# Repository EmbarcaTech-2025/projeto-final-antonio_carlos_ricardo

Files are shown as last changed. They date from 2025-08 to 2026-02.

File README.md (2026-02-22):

# Projeto final - EmbarcaTech 2025 - 2026

Autores: **Antonio Marcio Crepaldi**, **Carlos Martinez Perez** e **Ricardo Jorge Furlan**

Curso: Residência Tecnológica em Sistemas Embarcados

Instituição: EmbarcaTech - HBr

Campinas 22, fevereiro de 2026.

---

## ⚠ Disclaimer
## THE SOFTWARE IS PROVIDED "AS IS", USE AT YOUR OWN RISK
## O SOFTWARE É FORNECIDO "COMO ESTÁ", USE POR SUA CONTA E RISCO

## This code was developed for educational purposes as an assignment for Phase 2 and 3 of the residency program in the **EmbarcaTech professional training program**, with the goal of demonstrating some of the concepts learned during the residency.

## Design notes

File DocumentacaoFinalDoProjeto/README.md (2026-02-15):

# Projeto final - EmbarcaTech 2025-2026

Autores: **Carlos Martinez Perez** e **Ricardo Jorge Furlan** e **Antonio Crepaldi (na fase 3)**  

Curso: Residência Tecnológica em Sistemas Embarcados

Instituição: EmbarcaTech - HBr

Campinas 15, fevereiro de 2026.

---

## ⚠ Disclaimer
## THE PROJECT IS PROVIDED "AS IS", USE AT YOUR OWN RISK
## O PROJETO É FORNECIDO "COMO ESTÁ", USE POR SUA CONTA E RISCO

## This project was developed for educational purposes as an assignment for Phase 3 of the residency program in the **EmbarcaTech professional training program**, with the goal of demonstrating some of the concepts learned during the residency.

## Third-Party Code

- The `pico_sdk_import.cmake` file was **automatically generated** during project creation by the **Raspberry Pi Pico plugin**.
- The `CMakeLists.txt` file was initially **automatically generated** during project creation by the **Raspberry Pi Pico plugin**, and later edited as needed for the project.

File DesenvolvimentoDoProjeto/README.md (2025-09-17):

# Projeto final - EmbarcaTech 2025

Autores: **Carlos Martinez Perez** e **Ricardo Jorge Furlan**

Curso: Residência Tecnológica em Sistemas Embarcados

Instituição: EmbarcaTech - HBr

Campinas 08, setembro de 2025.

---

## ⚠ Disclaimer
## THE SOFTWARE IS PROVIDED "AS IS", USE AT YOUR OWN RISK
## O SOFTWARE É FORNECIDO "COMO ESTÁ", USE POR SUA CONTA E RISCO

## This code was developed for educational purposes as an assignment for Phase 2 of the residency program in the **EmbarcaTech professional training program**, with the goal of demonstrating some of the concepts learned during the residency.

## Third-Party Code

- The files for controlling the **OLED display** (`ssd1306_...` files), including the text fonts, were based on the repository:  
  https://github.com/BitDogLab/BitDogLab-C/tree/main/display_oled_logo/inc with minor modifications.
- The `pico_sdk_import.cmake` file was **automatically generated** during project creation by the **Raspberry Pi Pico plugin**.
- The `CMakeLists.txt` file was initially **automatically generated** during project creation by the **Raspberry Pi Pico plugin**, and later edited as needed for the project.

## How to Build/Compile the Code

This software was developed for the **BitDogLab V6.3** board. This board uses the **Raspberry Pi Pico_W** board (which contains the **RP2040 microcontroller**).

For development, the **Visual Studio Code IDE** was used along with the **Raspberry Pi Pico plugin**. The SDK version used was **2.2.0**.

---

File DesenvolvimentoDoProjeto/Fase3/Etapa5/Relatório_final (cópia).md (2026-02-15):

# RELATÓRIO FINAL DO PROJETO

# Estação Meteorológica IoT de Baixo Consumo com LoRaWAN

**Autores: Antonio Crepaldi - Carlos Perez - Ricardo Furlan**

**15/02/2026**

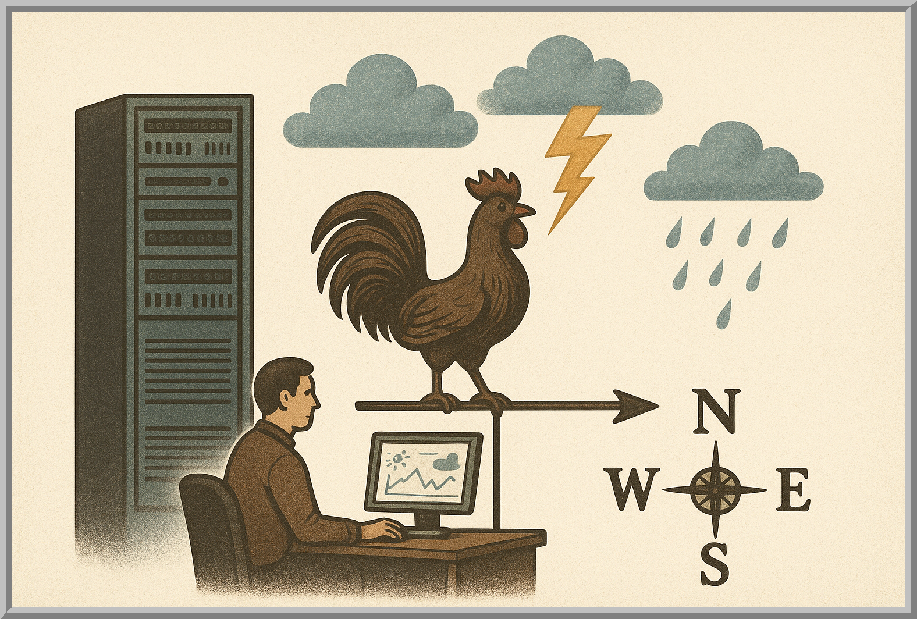
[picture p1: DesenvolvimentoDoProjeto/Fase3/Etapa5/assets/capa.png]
Capa do Manual

---

## 1. Introdução

Este relatório apresenta a consolidação final do projeto **Estação
Meteorológica IoT**, desenvolvido no âmbito do programa Embarcatech, com
foco em:

- Monitoramento ambiental distribuído;
- Comunicação via LoRaWAN;
- Autonomia energética com painel solar;
- Visualização em dashboards dos dados coletados;
- Solução escalável para múltiplas estações.

O projeto evoluiu desde validações laboratoriais (TRL 4) até validação
em ambiente operacional (TRL 7), culminando na implantação em
campo e validação integral do sistema.  
A figura a seguir, apresenta a estação operando em campo.

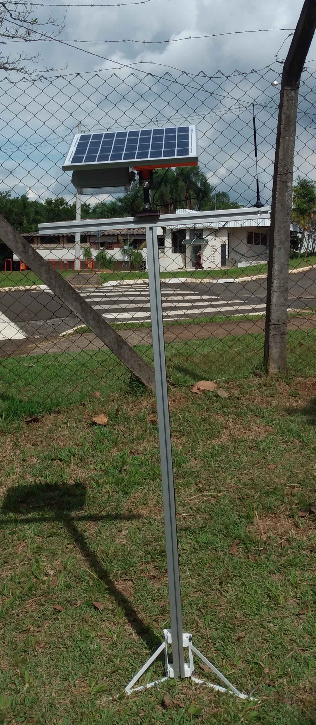
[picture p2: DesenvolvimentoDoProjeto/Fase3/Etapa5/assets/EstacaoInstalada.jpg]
Estação Instalada na FEEC


---

## 2. Requisitos do Projeto

O projeto atende ao que foi solicitado no Programa Embarcatech em sua fase 3. Os requisitos consolidados do projeto são os seguintes:  

### 2.1 Requisitos Funcionais

O sistema deverá ser capaz de executar as seguintes medições de parâmetros ambientais:  
- Temperatura do Ar: medição em graus Celsius (°C)
- Umidade Relativa do Ar: medição em porcentagem (%)
- Pressão Atmosférica: medição em hecto Pascal (hPa)
- Luminosidade: medição em Lux (lx)
- Localização: obtenção de coordenadas geográficas
- Tensão da bateria: medição em Volts (V)

Coleta de Dados:  
- Realizar a coleta de dados dos sensores habilitados em intervalos definidos (ex: a cada 1 minuto, 10 minutos, etc.).

Transmissão de Dados:  
- Transmitir os dados coletados via LoRaWAN para o gateway RAK7289V2 instalado na FEEC.  

Visualização e Análise de Dados:  
- Os dados serão acessíveis e visualizáveis através da plataforma TheThingsBoard, com dashboards personalizáveis e específicos.  

### 2.2 Requisitos Não Funcionais

- Modularidade: O design do sistema é modular, permitindo a fácil adição ou substituição de sensores para satisfazer às necessidades específicas de cada usuário.  
- Escalabilidade: O sistema é capaz de suportar a implantação de múltiplas estações em diferentes locais, de forma que os dados possam ser facilmente agrupados.
- Autonomia Energética: Operação autônoma com baixo consumo de energia, através de bateria de Lítio e carregamento com placa solar.
- Robustez Física e Resistência à Intempéries: O encapsulamento eletromecânico é resistente a condições climáticas adversas (chuva, vento, sol, poeira, umidade) atendendo ao grau de proteção IP68.
- Manutenibilidade: Facilidade de manutenção e atualização de software e hardware em campo.
- Segurança (Básica): Proteção básica dos dados transmitidos para o gateway, suprido pelo protocolo LoRaWAN.

---

## 3. Arquitetura Geral do Sistema

A figura a seguir, mostra a arquitetura geral do sistema, destacando os blocos de energia, sensores e comunicação.  
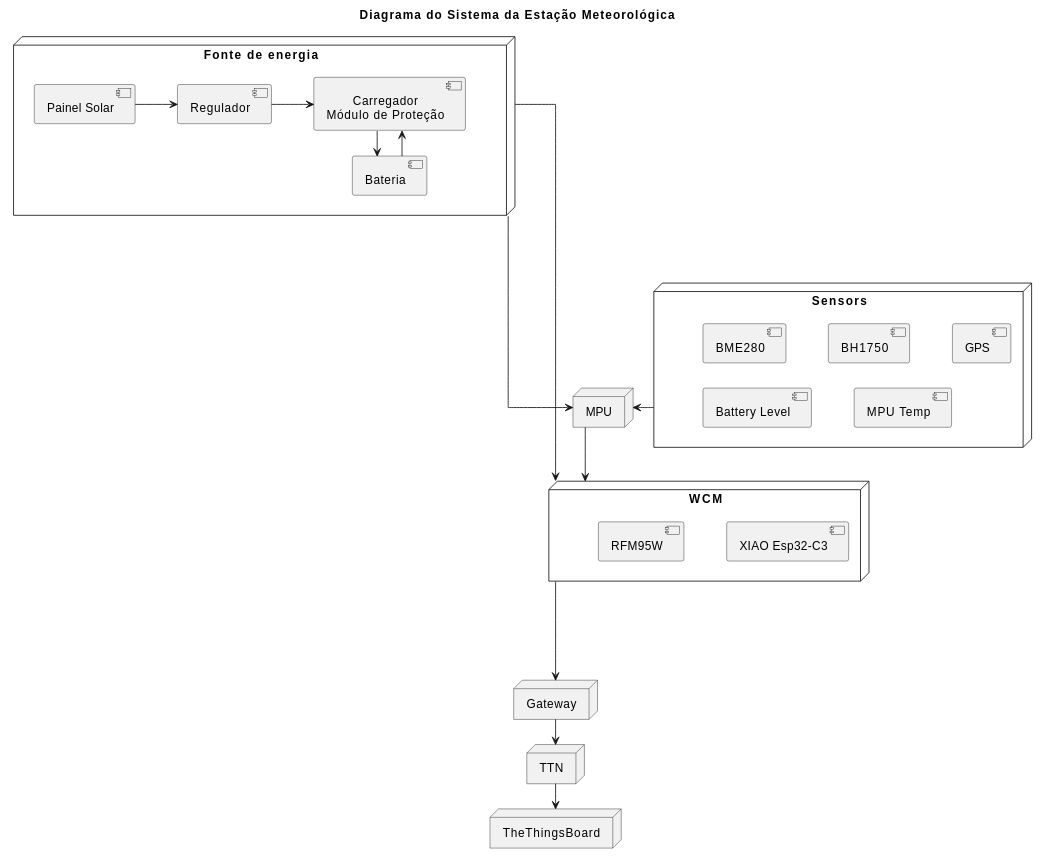
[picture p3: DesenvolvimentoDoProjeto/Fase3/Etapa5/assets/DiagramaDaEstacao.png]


O sistema é composto por cinco camadas principais:

### 3.1 Camada de Sensoriamento

A implementação consta dos seguintes sensores:  
- Temperatura, umidade e pressão atmosférica (BME280);

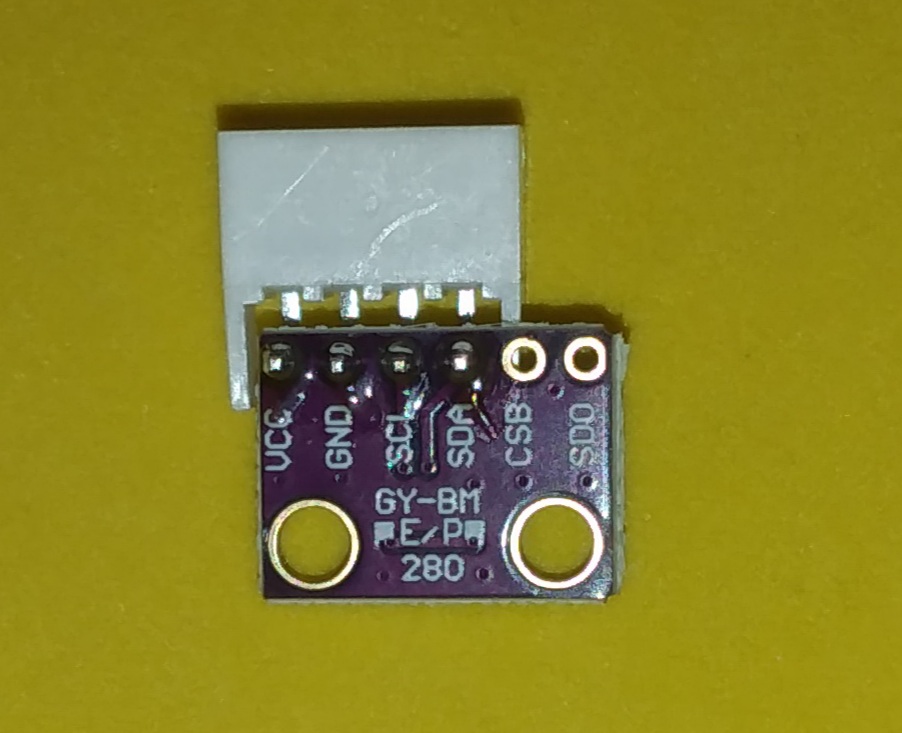
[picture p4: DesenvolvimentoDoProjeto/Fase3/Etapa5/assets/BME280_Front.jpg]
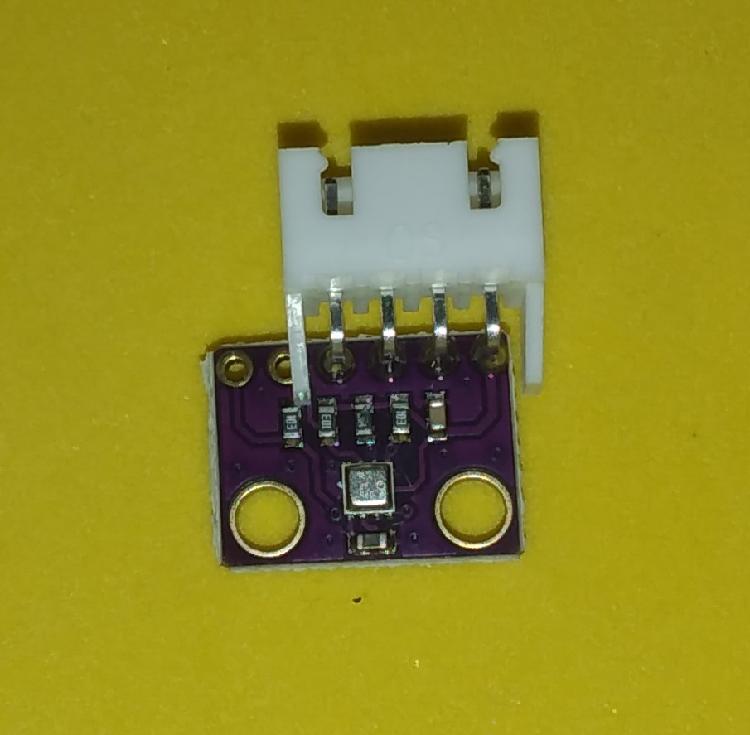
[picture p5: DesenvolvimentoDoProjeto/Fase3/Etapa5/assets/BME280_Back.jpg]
BME280 Verso
|  |  |
|---|---|

- Luminosidade (BH1750);

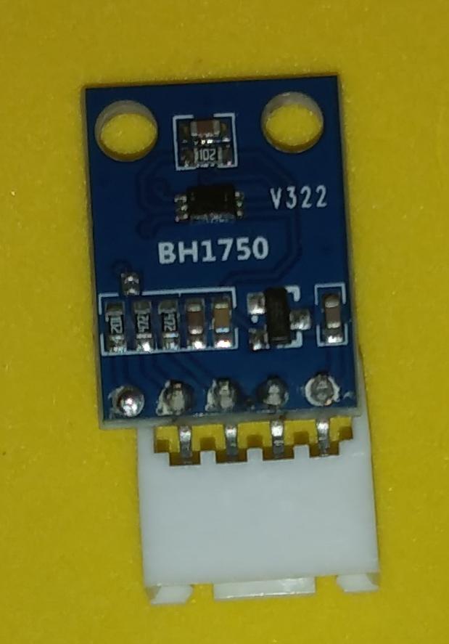
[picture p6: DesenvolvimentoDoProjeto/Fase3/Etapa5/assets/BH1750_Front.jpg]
BH1750 Frente
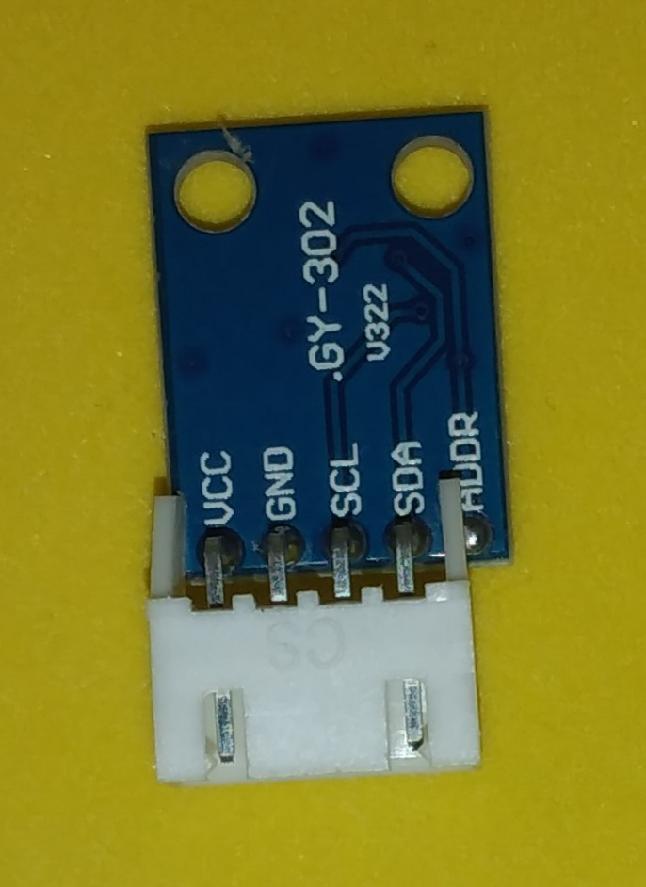
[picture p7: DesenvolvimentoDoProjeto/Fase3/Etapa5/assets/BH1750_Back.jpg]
BH1750 Verso
|  |  |
|---|---|

- GPS (GY-NEO6MV2);

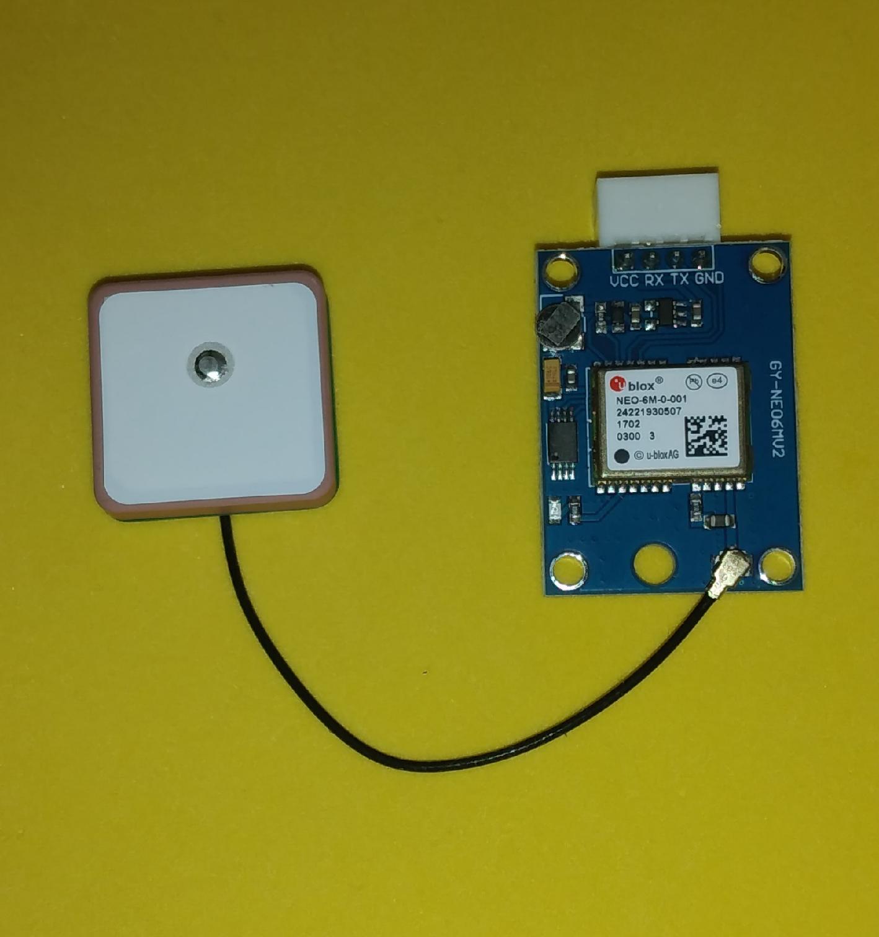
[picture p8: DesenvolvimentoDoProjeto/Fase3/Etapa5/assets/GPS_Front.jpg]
GPS Frente
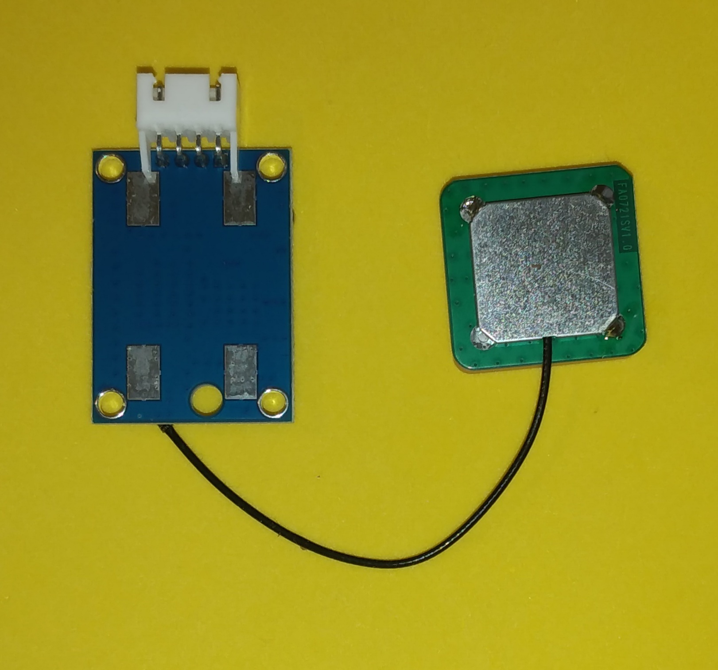
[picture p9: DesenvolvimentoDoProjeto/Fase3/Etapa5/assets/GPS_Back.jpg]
GPS Verso
|  |  |
|---|---|

- Nível de bateria (via AD e divisor resistivo);
- Temperatura interna do microcontrolador (RP2040).

### 3.2 Camada de Processamento

A camada de processamento é composta pelos seguintes elementos:

-   Microcontrolador RP2040 (Raspberry Pi Pico);
-   Estratégias de baixo consumo (desativação de funcionalidades desnecessárias e redução de clock do micricintrolador);
-   Estrutura modular do firmware.

A figura a seguir mostra a disposição dos componentes na placa.  

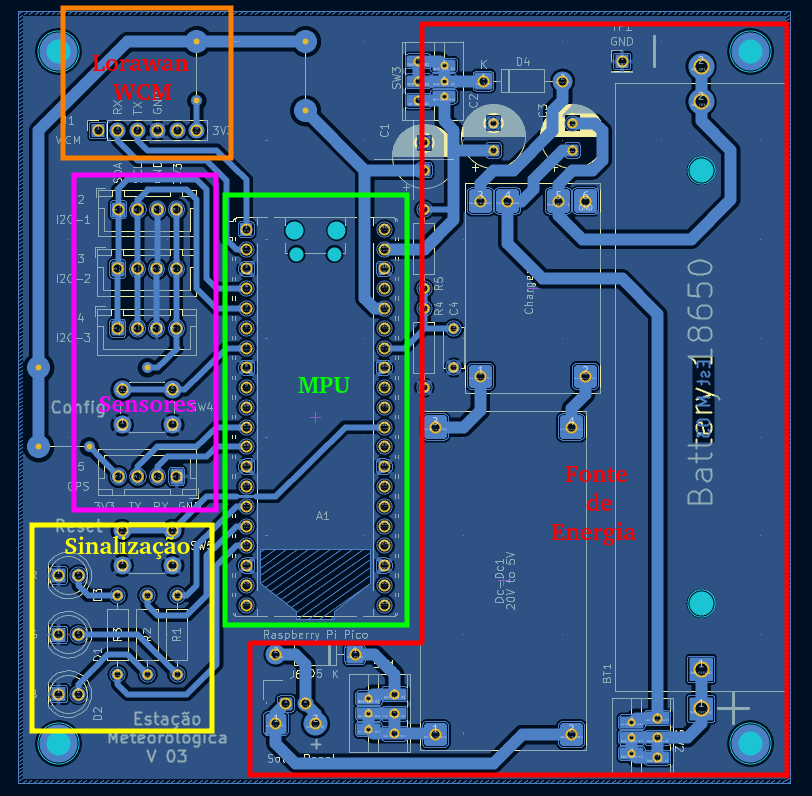
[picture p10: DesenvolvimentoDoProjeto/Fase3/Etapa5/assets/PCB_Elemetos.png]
Placa Principal - Extrutura


### 3.3 Camada de Comunicação

A camada de comunicação é constituída por:  
-   Módulo WCM - Wireless Communication Module (XIAO ESP32-C3 e RFM95W);
-  Implementação de Lite Sleep Mode;
-  Protocolo de comunicação LoRaWAN ABP;
-   Payload otimizado para redução do Time on Air (ToA).

Na figura a seguir aparece o WCM.

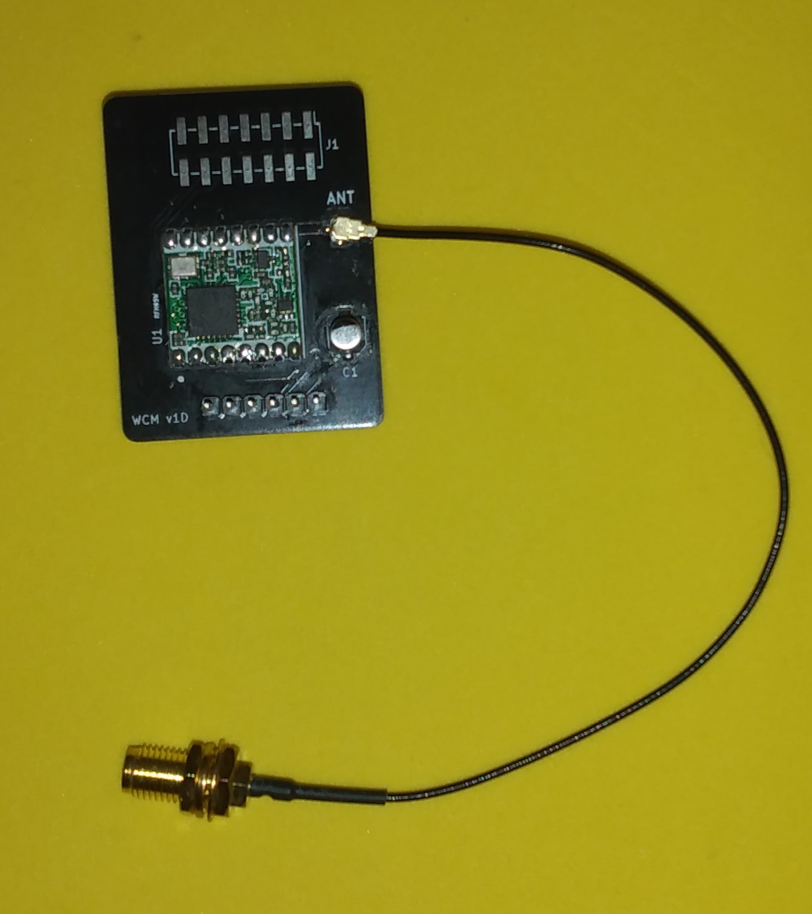
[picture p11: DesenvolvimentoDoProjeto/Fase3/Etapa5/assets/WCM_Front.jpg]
WCM Frente
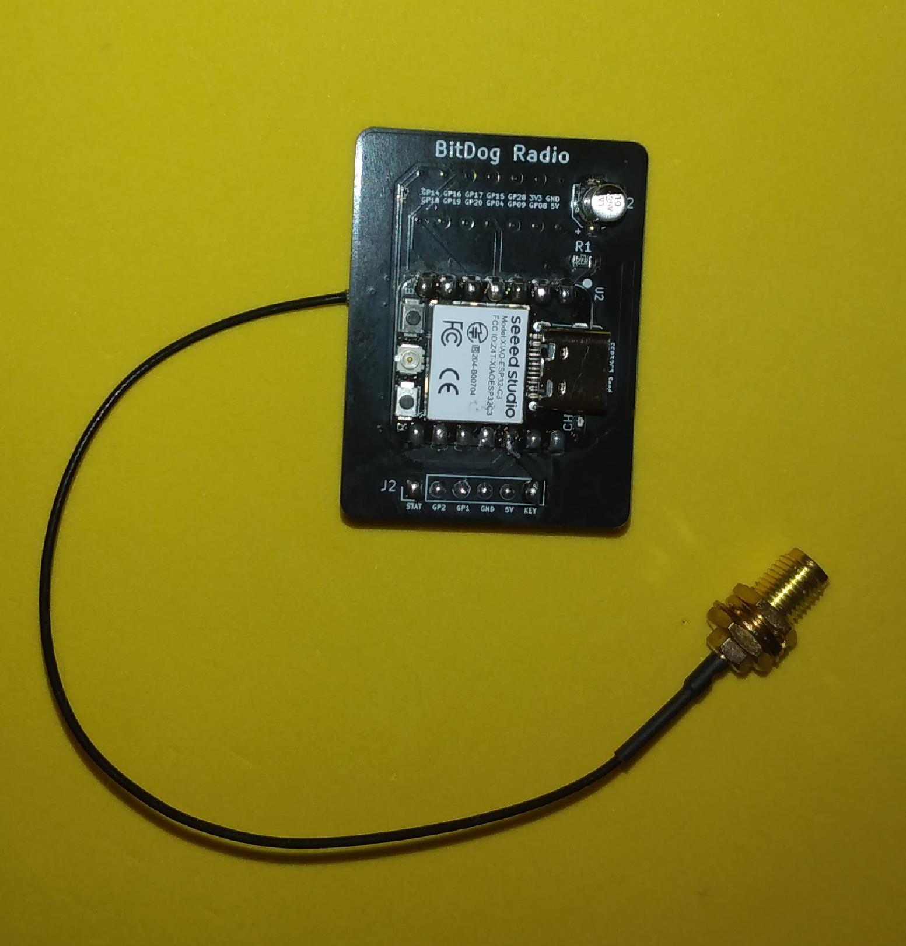
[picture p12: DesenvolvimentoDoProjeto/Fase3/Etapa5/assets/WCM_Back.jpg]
WCM Verso
|  |  |
|---|---|

O hardware do módulo WCM foi desenvolvido no projeto de iniciação científica da FEEC (https://drive.google.com/file/d/10zEuYUwZnq1ES-jrfOPs1fpPD2277zWO/view).

### 3.4 Camada de Recepção de Dados

A camada de recepção de dados é constituída por:  
-  Gateway RAK7289V2;
-  Servidor na nuvem (The Things Network - TTN).

A camada de recepção de dados foi desenvolvida no projeto de iniciação científica da FEEC (https://docs.google.com/document/d/1o25VC49TM4YPC_RLyG_XDTTJo1DXNHsViMWomo7teZQ/edit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).

### 3.5 Camada de Aplicação

A camada de aplicação envolve:  
-  Servidor local (Raspberry Pi 5);
-  Persistência de dados com PostgreSQL.
-  TheThingsBoard com dashboards individuais e comparativos;
-  Acesso via Cloudflare.

Esta camada também foi desenvolvida pelo grupo de iniciação científica da FEEC.

---

## 4. Evolução Técnica do Projeto

### 4.1 Desenvolvimento Individual dos Componentes

Foram desenvolvidos individualmente:  
-  Software para aquisição de dados dos sensores (em anexo);
-  Software para comunicação LoRa ponto a ponto com RFM95W (em anexo);
-  Estratégias de redução de consumo para RP2040 e ESP32-C3;
-  Estratégias de carregamento de bateria com placa solar.

### 4.2 Integração dos Componentes do Sistema

-  Desenvolvimento da PCB dedicada (em anexo):  
O desenvolvimento inicial da estação meteorológica previa o uso da placa educacional BitDogLab versão 7. No decorrer do desenvolvimento, devido aos rigorosos requisitos de consumo de energia, optou-se pelo desenvolvimento de uma nova placa dedicada. Isto deveu-se ao fato de que os diversos periféricos da BitDogLab, ou seja, display OLED, matriz de LEDs RGB, microfone e amplificador de áudio e regulador 3V3, consumiam energia mesmo não estando em operação. Além disso, o carregador não energizava a placa automaticamente. Outro aspecto que corrobora com essa decisão é a necessidade de utilização de carregamento de bateria via placa solar, através da utilização de um carregador dedicado. Assim, foi desenvolvida uma nova PCB agregando todas os componentes, (RP2040, carregador de bateria, regulador de tensão, bateria, chaves de comando e conectores para os sensores e WCM), como mostra a figura a seguir.  

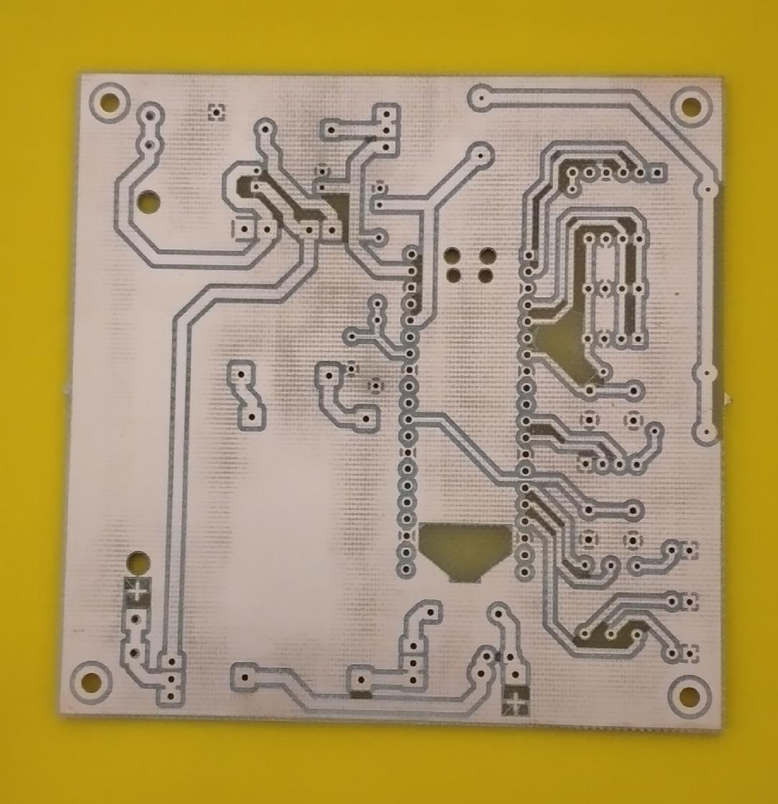
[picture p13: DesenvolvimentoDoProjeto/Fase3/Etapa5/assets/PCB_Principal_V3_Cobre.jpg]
Placa Principal, Cobre
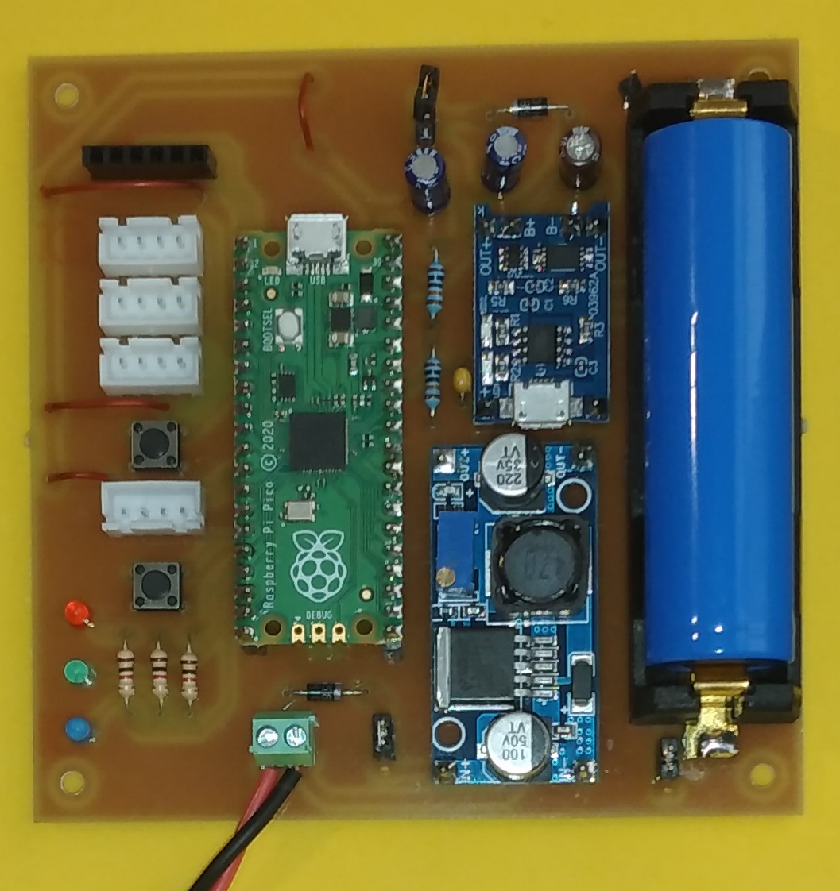
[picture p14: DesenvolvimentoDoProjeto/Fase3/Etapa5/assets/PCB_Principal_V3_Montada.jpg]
Placa Principal Montada
|  |  |
|---|---|

-  Firmware da estação (em anexo):  
O firmware da estação meteorológica tem duas seções principais:  
    - Interface de usuário, para configuração da estação e inicialização do sistema:  
A interface de usuário, com a configuração inicial do sistema, utiliza um menu intuitivo e de fácil navegação, através da utilização de um monitor serial via USB. Durante a operação normal, esta seção pode ser reacionada através do reset do sistema e do pressionamento do botão de configuração. Além disso, foram utilizados LEDs coloridos para indicar ao usuário os vários estados de funcionamento, ou seja, configuração, aquisição, comunicação, sleep mode e indicação de falhas de funcionamento.  
    - Loop para aquisição e comunicação dos dados climáticos coletados:  
O loop de operação da estação foi desenvolvido com uma estrutura modular de programação. A aquisição de dados pelos sensores, por exemplo, foi pensada para utilizar drivers que funcionam com uma estratégia comum de operação, ou seja, energizar o sensor, inicializar a aquisição, obter as medições das grandezas e, finalmente, colocar o sensor em sleep mode. Outro exemplo é a rotina responsável pela comunicação com o WCM, que pode ser editada para se comunicar com modelos futuros.  
Para atender aos requisitos de baixo consumo de energia, o firmware da estação, nos períodos em que ela não está coletando ou comunicando dados, foi projetado para simular um sleep mode via software, através da diminuição da frequência do clock principal e do desligamento dos PLLs, entre outras ações.  
O repositório do projeto (em anexo) descreve o firmware em detalhes.  

-  Firmware do WCM:  
O módulo WCM acorda assim que recebe uma comunicação via UART. Em seguida, recebe um comando para efetuar a comunicação e o payload com os dados a serem transmitidos e, assim que transmitir, volta a dormir, economizando energia.  

- Estrutura mecânica da estação:  
Para sua instalação em campo, a estação meteorológica conta com um suporte que sustenta a caixa com a placa principal, a placa solar e os sensores. Esse suporte, impresso em 3D, utilizando filamentos ABS, é acoplado á uma estrutura metálica fixada ao solo. Ele permite o correto posicionamento da placa solar para obter a máxima eficiência de insolação. Adicionamente, a placa solar funciona como abrigo à caixa do sistema.  

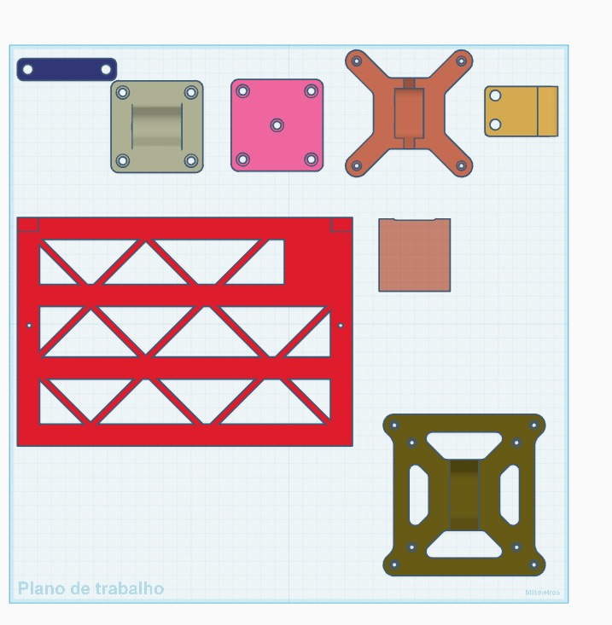
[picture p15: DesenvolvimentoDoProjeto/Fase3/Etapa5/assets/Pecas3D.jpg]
Pecas 3D


### 4.3 Construção e Montagem de Protótipos

Principais atividades realizadas:  
-   Montagem física de protótipos;
-   Correção do layout da PCB;
-   Substituição de componentes defeituosos;
-   Testes elétricos e funcionais;
-   Instalação física do primeiro protótipo em campo;
-   Mapeamento do sinal LoRaWAN em diversos pontos do campus (em anexo).  

### 4.4 Instalação Distribuída
-   Definição dos locais para instalação das unidades;
-   Instalação física das estações;
-   Verificação de funcionamento pós-instalação.

### 4.5 Backend e Dashboards
-   Verificação de chegada de dados no Gateway, TTN e TheThingsBoard;
-   Constatação de persistência e histórico;
-   Criação de dashboards.

### 4.6 Repositório Open Source
-   Criação de repositório exclusivo do projeto;
-   Organização de diretórios firmware, hardware e documentação.

---

## 5. Validação Final Integrada

Nesta seção são mostradas evidências do funcionamento do sistema.  

### 5.1 Evidência de Comunicação
 
- Dados obtidos durante o desenvolvimento simulando o gateway:  
    - A figura a seguir mostra o log da estação ao enviar dados ao WCM.
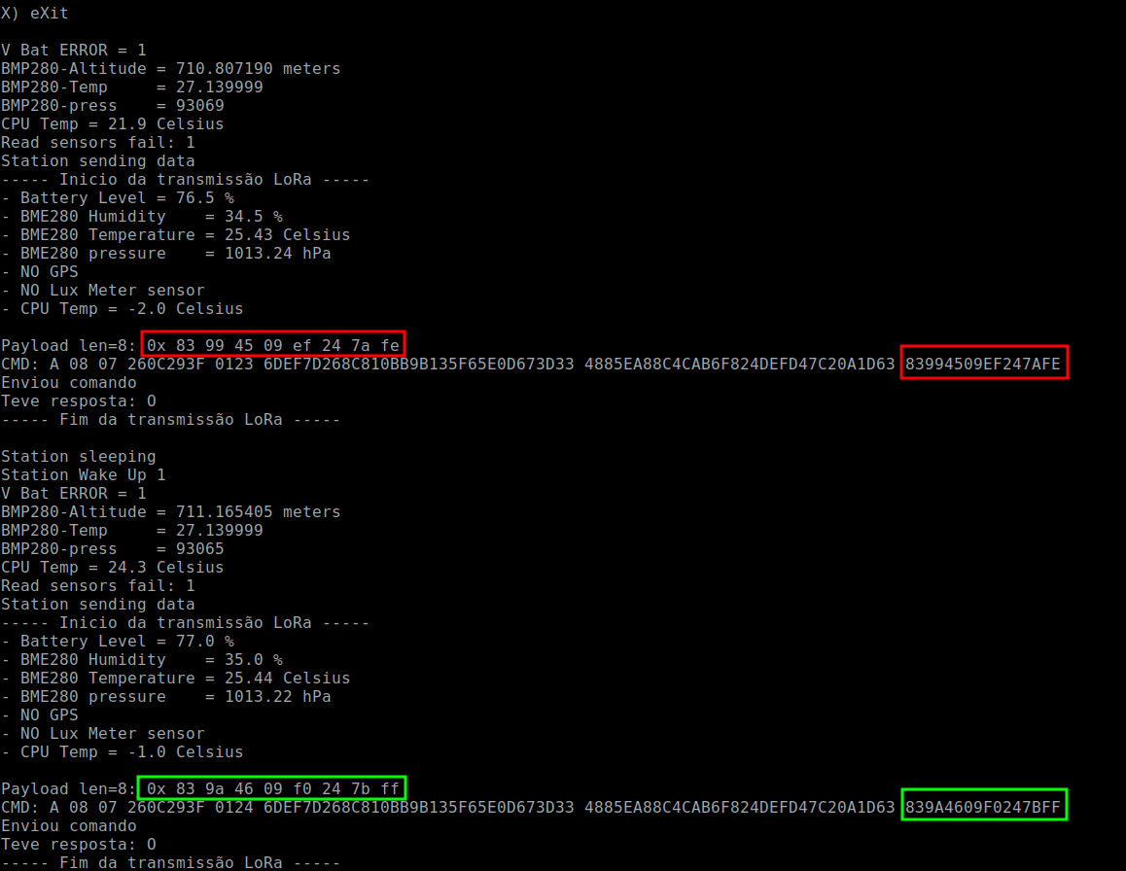
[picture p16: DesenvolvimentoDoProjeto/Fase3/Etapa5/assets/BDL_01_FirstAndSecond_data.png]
Dados enviados ao WCM
	

    - A figura a seguir mostra a recepção dos dados pelo simulador de gateway.
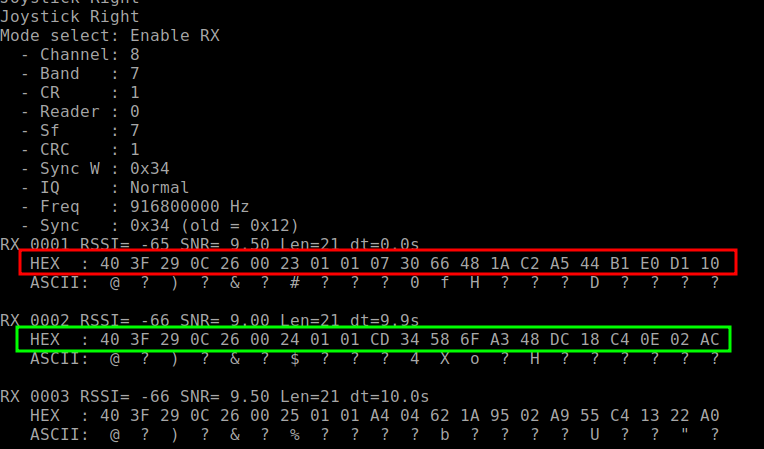
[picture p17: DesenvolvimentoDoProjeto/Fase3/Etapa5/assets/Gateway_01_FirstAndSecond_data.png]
Dados recebidos simulador Dateway
	

- A figura a seguir nostra os dados reais chegando ao gateway.
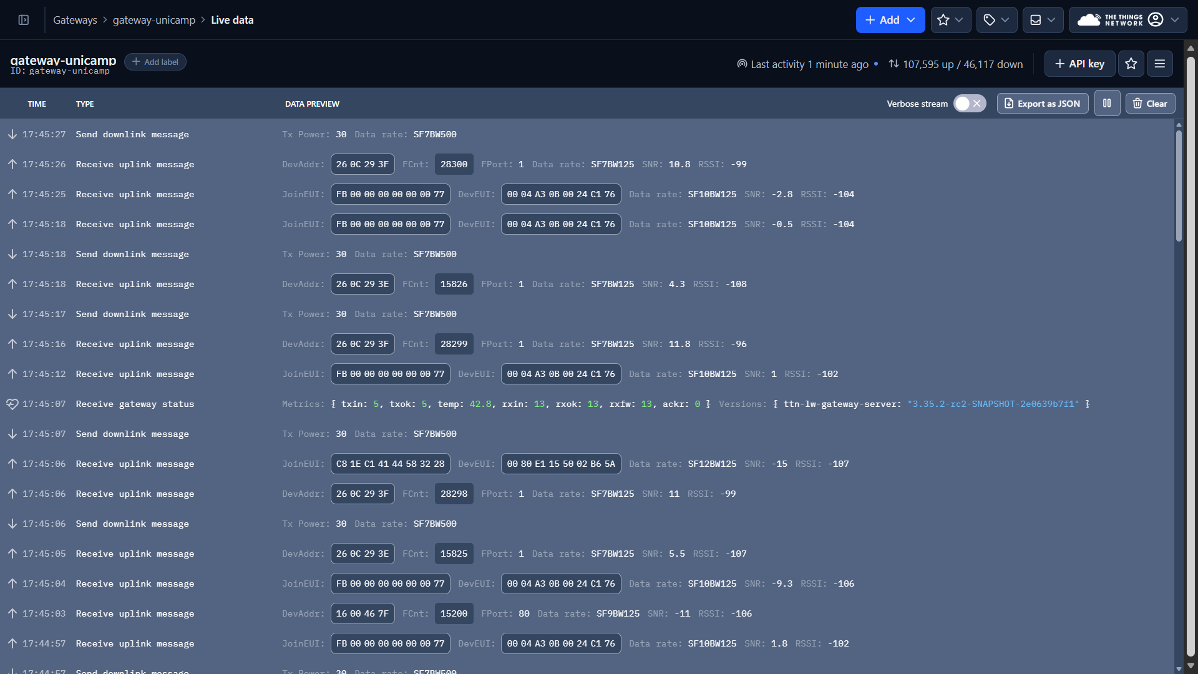
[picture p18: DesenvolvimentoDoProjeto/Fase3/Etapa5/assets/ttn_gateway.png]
TTN Gateway


- A figura a seguir nostra os dados reais chegando ao TTN e a decodificação do payload.  
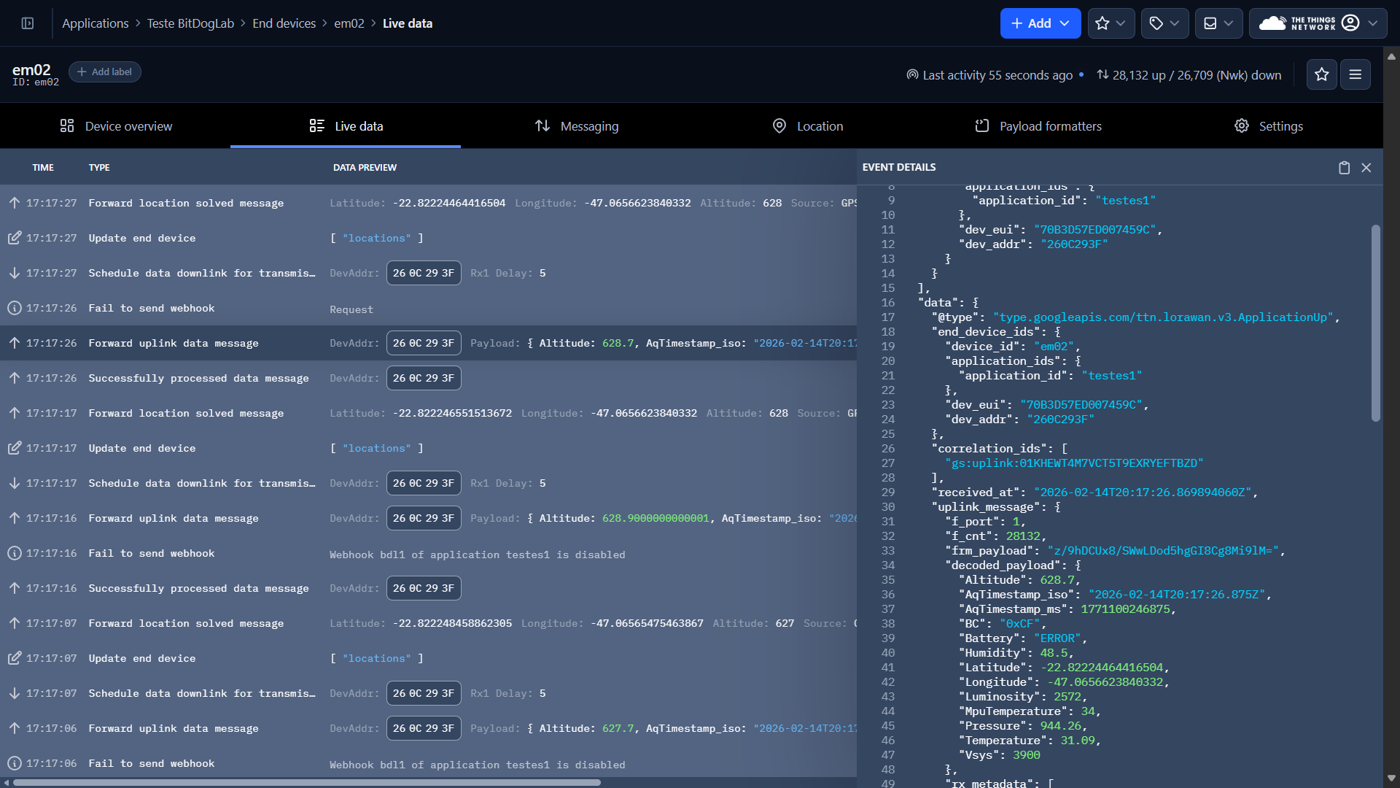
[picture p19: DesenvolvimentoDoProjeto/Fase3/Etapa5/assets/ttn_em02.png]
TTN em02


### 5.2 Evidencia de Autonomia Energética

- As figuras a seguir  mostram os estudos iniciais para avaliar o consumo do módulo WCM.  
	+ WCM transmitindo dados  
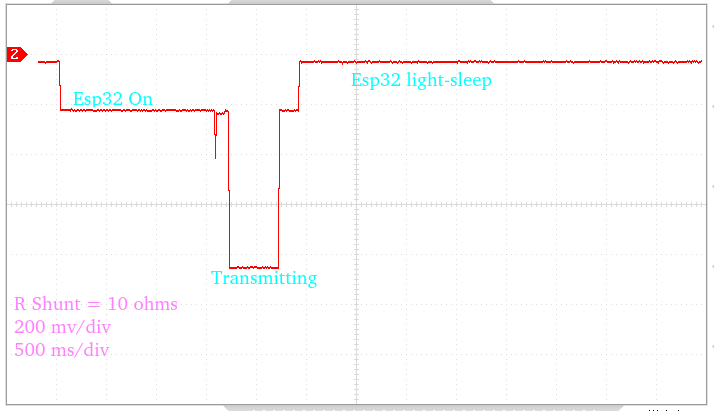
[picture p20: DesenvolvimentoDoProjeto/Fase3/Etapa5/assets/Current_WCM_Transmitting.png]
WCM Transmite

	+ WCM recebendo dados  
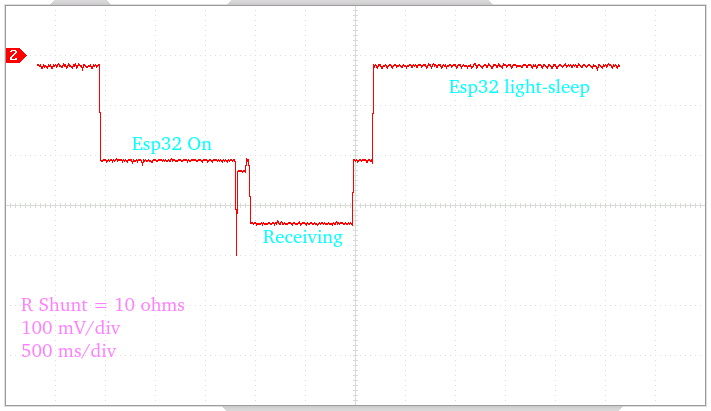
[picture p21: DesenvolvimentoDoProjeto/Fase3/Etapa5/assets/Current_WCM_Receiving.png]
WCM recebendo


- A figura a seguir mostra o resultado da otimização de consumo do RP2040 e WCM  
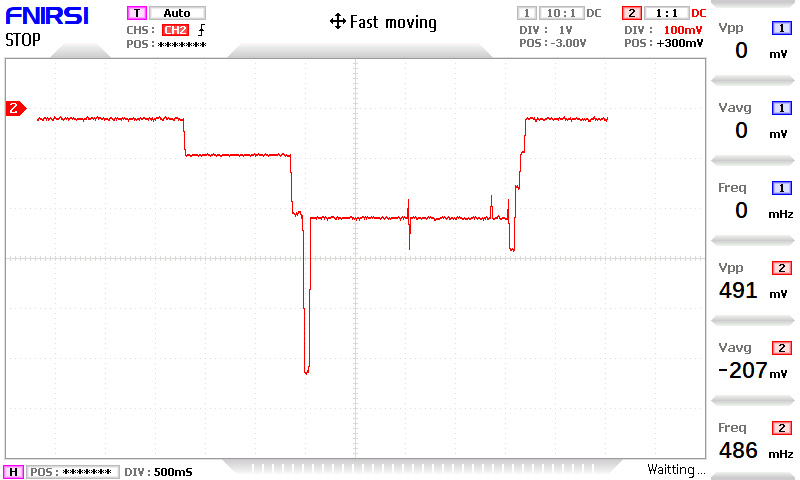
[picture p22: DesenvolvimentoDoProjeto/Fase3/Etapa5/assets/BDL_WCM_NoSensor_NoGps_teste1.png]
Otimização de consumo


- A figura a seguir mostra o gráfico de luminosidade e carga da estação operando ao ar livre, demostrando a carga da bateria em momentos de luminozidade alta.  
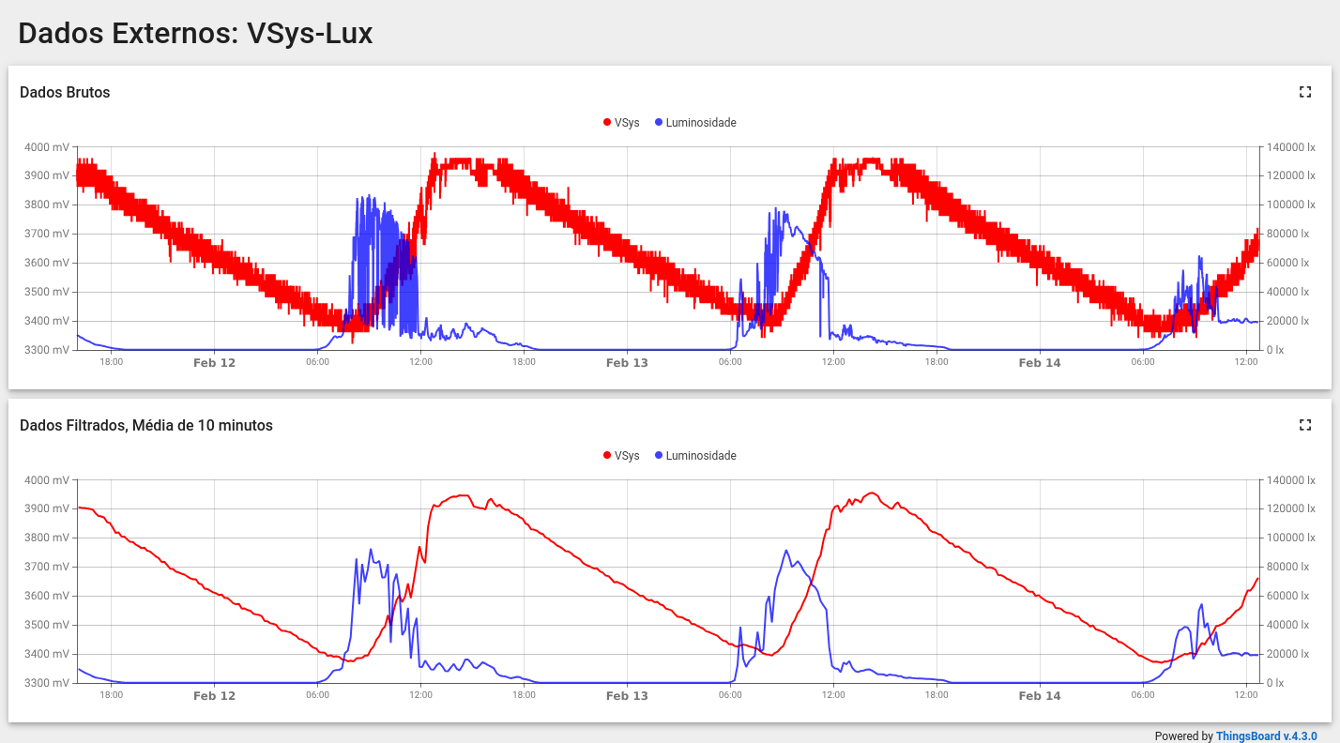
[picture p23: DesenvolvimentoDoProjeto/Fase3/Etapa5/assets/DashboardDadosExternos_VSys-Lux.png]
Dashboard dados Externos VSys e luminosidade


### 5.3 Evidência de Visualização de Dados

O dashboard abaixo contém dados da estação montada dentro do laboratório, sem painel solar. Nele, pode-se observar os seguintes eventos:
- A oscilação da temperatura e da umidade causada pelo liga-desliga do ar condicionado;
- Os momentos em que a iluminação interna é ligada e desligada;
- O esgotamento da bateria.  

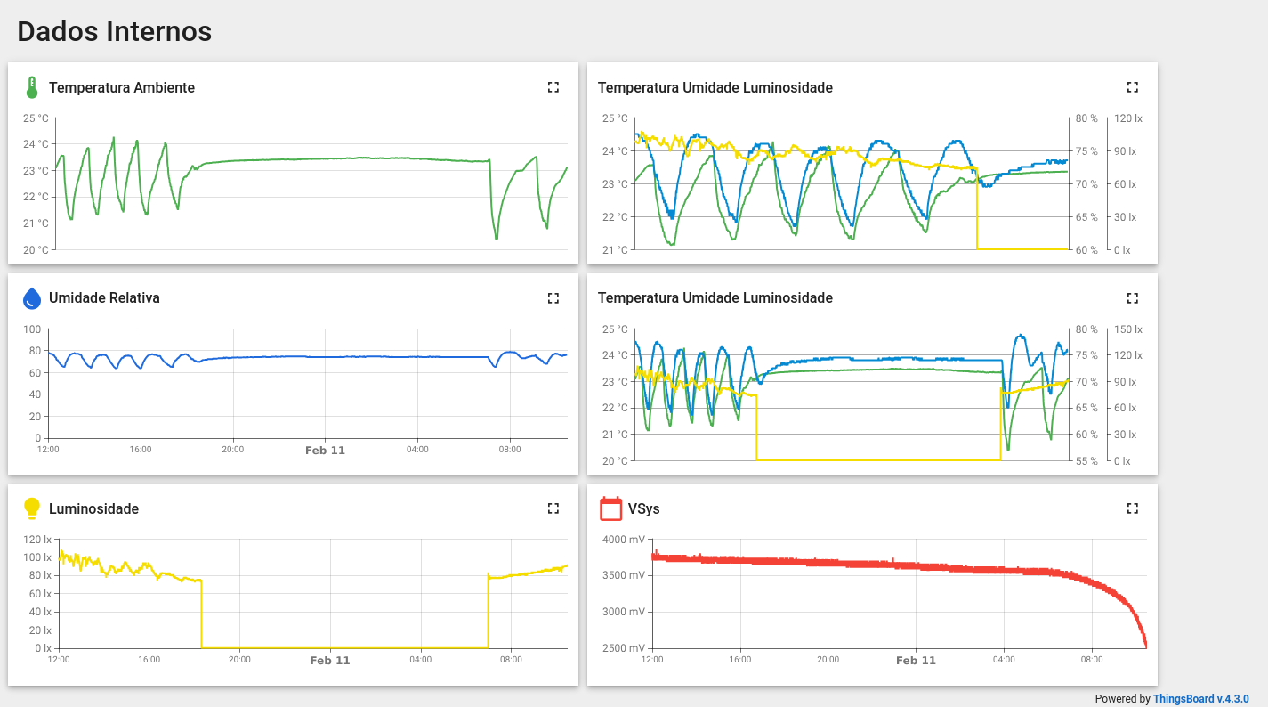
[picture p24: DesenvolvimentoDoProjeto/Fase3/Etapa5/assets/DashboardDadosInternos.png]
Dashboard dados Internos


Neste outro Dashboard, com dados de 10/02, na estação montada ao ar livre, pode-se observar os seguintes eventos:  
- Uma queda expressiva na pressão atmosférica entre 13 e 18 horas;
- Uma queda expressiva na temperatura entre 16 e 18 horas e 30 minutos.  

Cabe notar que foram observadas tempestades na região por volta das 18 horas.  

Dashboard dados Externos

---

## 6. Avaliação de Maturidade Tecnológica (TRL)

Estado ao final da Etapa 4: **TRL 5 -- Tecnologia validada em ambiente
relevante.**

Estado ao final da Etapa 5: Com a implantação em campo, operação
integrada e backend funcional, o projeto aproxima-se de **TRL 7 -- Demonstração de protótipo em ambiente operacional.**

A consolidação formal do TRL 7 dependerá de operação contínua prolongada
e coleta sistemática de dados.

---

## 7. Resultados Consolidados

-   Arquitetura modular e escalável;
-   Payload LoRaWAN otimizado;
-   Redução expressiva de consumo energético e carga via placar solar;
-   Integração real com TTN e ThingsBoard;
-   Hardware dedicado ao projeto;
-   Sistema preparado para replicação em escala.

---
  
## 8. Custo da estação

| Módulo | Custo estimado|
| :---: | ---: |
| Placa Principal | R$ 114,69 |
| WCM | R$ 164,16 |
| Sensores | R$ 83,97  | 
| Itens de Instalação | R$ 328,85 |
| **TOTAL** | **R$ 691,67** |

A título de comparação, uma estação comercial com LoRa, colocada no mercado nacional, pode ser obtida ao preço de R# 1.390,44, como informa https://www.mercadolivre.com.br/estaco-meteorologica-lora-7-em-1-com-sistema-de/p/MLB2030746108.

---
  
## 9. Conclusão

A Estação Meteorológica IoT desenvolvida demonstra viabilidade técnica,
maturidade arquitetural e potencial de escalabilidade.

O sistema encontra-se apto para expansão para múltiplas unidades,
operação contínua e evolução tecnológica futura.

---
  
---
  
## Anexos

Os anexos abaixo encontram-se dentro da pasta:  

https://github.com/EmbarcaTech-2025/projeto-final-antonio_carlos_ricardo/tree/main/DocumentacaoFinalDoProjeto

Obs.: Abaixo estão apenas o caminho e o nome do arquivo

### Manual do Usuário

Doc/Manual_Usuário/Manual_Usuario.md

### Planilha de Custos
Doc/BillOfMaterial_With_Cost.ods  
Doc/BillOfMaterial_With_Cost.pdf

### Mapeamento do sinal LoRaWAN
Doc/Dados_TX_LoRa.pdf

### Código Fonte
#### Placa Principal (Pico - RP2040)
Software/Main_Board

#### Placa WCM (ESP32-C3)
Software/WCM

#### Decodificador de Paylod para o TTN
Software/TTN_Payload_Decode

### Esquemáticos e PCB
#### Placa Principal (Pico - RP2040)
Hardware/MainBoard

#### Placa WCM (ESP32-C3)
Hardware/WCM

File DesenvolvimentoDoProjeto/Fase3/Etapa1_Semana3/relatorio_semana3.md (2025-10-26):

# Relatório — Semana 3  
**Escolha de Hardware e Planejamento para Mudanças**  
**Entrega escrita:** 26/10 **Apresentação:** 27/10

## 1. Objetivo
Selecionar hardware coerente com as especificações iniciais da estação meteorológica IoT e de acordo com a entrevista com o cliente(requisitos), planejar a resiliência a mudanças de componentes/tecnologias e documentar justificação técnica e econômica das escolhas.

---

## 2. Matriz comparativa de hardware

### 2.1 Microcontroladores (unidade de aquisição)

**Escolha recomendada:** *Raspberry Pi Pico 2*, com firmware em C, pois tem baixo custo e bom suporte.

| Característica | **Raspberry Pi Pico** | **Raspberry Pi Pico W** | **Raspberry Pi Pico 2** | **Raspberry Pi Pico 2 W** |
|---|---|---|---|---|
| **Microcontrolador** | RP2040 (Dual-core ARM Cortex-M0+) | RP2040 (Dual-core ARM Cortex-M0+) | RP2350 (Dual-core ARM Cortex-M33 ou RISC-V) | RP2350 (Dual-core ARM Cortex-M33 ou RISC-V) |
| **Frequência de CPU** | 133 MHz | 133 MHz | até 150 MHz | até 150 MHz |
| **Memória Flash** | 2 MB | 2 MB | 4 MB (padrão, expansível) | 4 MB (padrão, expansível) |
| **SRAM** | 264 KB | 264 KB | 520 KB | 520 KB |
| **Conectividade** | Nenhuma | Wi-Fi + BLE (CYW43439) | Nenhuma | Wi-Fi + BLE (CYW43439) |
| **GPIOs disponíveis** | 26 | 26 | 26 | 26 |
| **ADC** | 3 canais (12 bits) | 3 canais (12 bits) | 3 canais (12 bits) | 3 canais (12 bits) |
| **PWM** | 16 canais | 16 canais | 16 canais | 16 canais |
| **Interfaces** | I2C, SPI, UART, USB 1.1, PIO | I2C, SPI, UART, USB 1.1, PIO | I2C, SPI, UART, USB 1.1, PIO | I2C, SPI, UART, USB 1.1, PIO |
| **Suporte a PIO** | Sim (2 blocos) | Sim (2 blocos) | Sim (2 blocos) | Sim (2 blocos) |
| **Tensão de operação** | 1,8–5,5 V | 1,8–5,5 V | 1,8–5,5 V | 1,8–5,5 V |
| **Consumo típico** | 20–90 mA | 50–150 mA (com Wi-Fi) | 20–100 mA | 50–150 mA (com Wi-Fi) | 
| **Dimensões** | 51 × 21 mm | 51 × 21 mm | 51 × 21 mm | 51 × 21 mm |
| **Preço médio (2025)** | R$ 45 | R$ 65 | R$ 55 | R$ 75 |
| **Pontos fortes** | Simplicidade, baixo custo, PIOs poderosos | Wi-Fi integrado, alta estabilidade | CPU mais moderna e rápida | Wi-Fi + novo RP2350 |
| **Limitações** | Sem conectividade | Sem BLE | Ainda sem BLE | Sem BLE |
| **Classificação** | aceitável | aceitável | recomendado | aceitável |

---

### 2.2 Sensores
| Sensor | Medição | Interface | Precisão típica | Faixa | Custo |
|:-:|:--:|:--:|:--:|:--:|:---:|
| BMP180 | Pressão/Temp | I²C / SPI | ±1 hPa / ±1°C | 300–1100 hPa | médio |
| BMP280 | Pressão/Temp | I²C / SPI | ±1 hPa / ±1°C | 300–1100 hPa | baixo |
| BME280 | Pressão/Temp/Umidade | I²C / SPI | ±1 hPa / ±1°C / ±3% | similar | médio |
| AHT10 | Umidade/Temp | I²C | ±3% / ±0.3°C | comum | baixo |
| BH1750 | Luminosidade | I²C | bom para ambiente | 1–65535 lx | baixo |
| Anemômetro (sensor hall) | Velocidade vento | Entrada digital<br>pulsos | depende | 0–60 m/s | baixo |
| Pluviómetro (sensor hall) | Precipitação | Entrada digitall<br>pulsos | contagem por pulso | — | baixo |

**Escolha recomendada:**
- **BMP280:** baixo custo, disponibilidade, precisão.

---

### 2.3 Módulos de rede / Gateway
| Item | Função | Observação |
|:-:|:-:|---|
| RAK7289CV2 (Gateway LoRa) | Gateway LoRaWAN para uplink ao TTN | Recomendado; robusto, multi-channel, compatível TTN |
| Home built Gateway<br>RFM95W + ESP32-C3 | Gateway LoRaWAN para uplink | Necessário desenvolver todo o código |

---

### 2.4 Fontes de alimentação
| Tipo | Vantagens | Desvantagens | Quando usar |
|---|---|---|---|
| Rede elétrica AC para 5V DC | Estável, barato | Não disponível em campo | Estações fixas com rede |
| Bateria recarregável + regulador | Autonomia, remoto | Manutenção, custo | Locais remotos |
| Painel solar + bateria | Autossuficiência | Custo inicial | Locais isolados (recomendado) |

**Escolha recomendada:** *Painel solar + bateria* para estações remotas; rede elétrica quando disponível.

---

## 3. Justificativas técnicas e econômicas

### 3.1 Microcontrolador
- **Técnica:** RP2350 (Pico 2) atende leituras I²C, SPI, PWM, ADC; possui recursos para multitarefa simples e baixo consumo; boa comunidade para drivers de sensores.  
- **Econômica:** Custo unitário baixo (favorável para escalabilidade).
- **Alternativa:** ESP32 tem Wi-Fi/BT mais maduros e maior suporte a TLS se necessário, porém similar custo.

### 3.2 Sensores
- **Técnica:** Os senores escolhidos oferecem precisão adequada ao uso.
- **Econômica:** Possuem baixo custo alinhado aos requisitos do projeto.
- **Alternativa:** O projeto está construído de forma que, se o mercado fornecer alternativas mais atraentes, a sua troca pode ser realizada sem maiores dificuldades.

### 3.3 Rede e gateway
- **Técnica:** O módulo WCM(ESP32-C3 + RFM95W) e o uso do gateway RAK7289CV2, se mostraram eficientes para permitir a construção de uma rede LoRaWAN de estações meteorológica, como mostrou o  desenvolvimento do grupo da FEEC Unicamp.  
- **Econômica:** Custo do gateway é amortizado quando se atende várias estações.
- **Alternativa:** Utilizar, nos dispositivos IoT, o módulo RFM95W, controlado diretamente pela placa pico 2 e, para o gateway, utilizar uma solução home-built com ESP32-C3 + RFM95W.

### 3.4 Energia
- **Técnica:** O painel solar permite que a estação fique autônoma em relação à fonte de energia externa.  
- **Econômica:** O custo pode ser menor que uma instalação elétrica em lugares remotos.
- **Alternativa:** Gerador eólico ou instalação elétrica dedicda.

---

## 4. Plano de abstração de hardware (HAL)

### 4.1 Objetivo do HAL
Criar interfaces genéricas que desacoplem a lógica do sistema dos componentes físicos, permitindo trocar sensores e módulos de comunicação sem alterar a camada de aplicação.

### 4.2 Estratégia utilizada  
Os sensores do projeto têm uma interfaze (API) padrão composta de inicialização (init()) e aquisição de dados (read()). Desta forma, a troca de sensores pode ser realizada sem alterar a estrutura principal do firmware.

### 4.3 Benefícios  
- Troca de hardware reduz impacto no firmware (apenas trocar driver).
- Testes unitários isolados por interface.
- Reuso de código para múltiplas plataformas (RP2040 / Rp2350 / ESP32).

---

## 5. Análise de riscos de substituição e mitigação

### Riscos principais
1. **Obsolescência de sensores (EOL)** — fornecedor descontinua componente.  
   - *Mitigação:* projeto modular com HAL; manter lista de equivalentes.  

1. **Gateway/Rede indisponível (TTN down / gateway com defeito)**  
   - *Mitigação:* Manter backup dos dados em flash(storage circular) no dispositivo IoT.

1. **Interferência/ruído em leituras** (ambiente campo)  
   - *Mitigação:* condicionamento de sinal, filtros RC e aterramento adequado.

---

## 6. Diagrama consolidado do sistema



---

## 7. Conclusão
A arquitetura proposta combina **RP2350 (Pico 2)** em  nós, sensores consolidados (como exemplo BMP280), energia solar para autonomia e o **RAK7289CV2** como gateway LoRaWAN para integração com o **TTN**. O projeto é modular por meio de uma API para sensores padrão, equivalente a implementanção de um HAL adequado, facilitando substituições e escalabilidade. As escolhas tentam equilibar custo, desempenho e robustez operacional. As mitigações de riscos propostas objetivam acegurar continuidade e facilidade de manutenção do projeto.

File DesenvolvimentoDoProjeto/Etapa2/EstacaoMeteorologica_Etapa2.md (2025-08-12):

# EMBARCATECH - FASE 2

## PROJETO FINAL - ESTAÇÃO METEOROLÓGICA

Autores: Carlos Martinez Perez e Ricardo Jorge Furlan

## ETAPA 2 - 08/08/2025:

Nessa etapa, será realizada a definição da Arquitetura e a Modelagem do projeto. O objetivo é apresentar a proposta de arquitetura do sistema, incluindo o diagrama de hardware, os blocos funcionais e o fluxograma do software.  
   
---

### DIAGRAMA ESTRUTURAL

Figura 1: Diagrama Estrutural  
**Figura 1:** Diagrama Estrutural
  
### EXPLICAÇÃO SOBRE A ESTRUTURA

A estrutura da estação meteorológica é organizada em módulos funcionais, conforme ilustrado no Diagrama Estrutural na Figura 1.  

- CPU (Central Processing Unit) - Raspberry Pi Pico W:  
Este é o coração do sistema. O Pico W é responsável por orquestrar todas as operações, incluindo a leitura dos dados brutos dos sensores, o processamento inicial desses dados, o armazenamento temporário (se necessário) e a gestão da comunicação para o envio das informações. Ele atua como o cérebro da estação, garantindo que os dados sejam coletados e preparados para transmissão de forma eficiente.  

- Sensores:  
Este bloco agrupa todos os dispositivos responsáveis pela coleta de dados ambientais. A modularidade dos sensores permite a fácil adição ou substituição de componentes para atender a necessidades específicas. Os tipos de sensores representados incluem:  

    - Temperatura  
    - Umidade (do ar)  
    - Pressão  
    - Velocidade e Direção do Vento  
    - Luminosidade  
    - UV (Radiação Ultravioleta)  
    - Temperatura do Solo  
    - Umidade do Solo  
    - Qualidade do Ar  

Esses sensores fornecem os dados brutos que descrevem o microclima e as condições do solo.  

- Comunicação:  
Este módulo é fundamental para a transmissão dos dados coletados para um servidor remoto. Ele incorpora as tecnologias de conectividade que permitem à estação enviar as informações de forma confiável. Os componentes destacados são:  

    - Módulo LoRa SPI e Antena LoRa : Representam a opção de comunicação de longo alcance e baixo consumo de energia, ideal para áreas rurais sem infraestrutura Wi-Fi densa.  
    - WiFi Integrado : Sendo a comunicação primária, o Wi-Fi presente no Raspberry Pi Pico W, permite a conexão direta com redes locais ou roteadores para acesso à internet.  

- Fonte de Alimentação:  
Este bloco garante a autonomia energética da estação, um requisito fundamental para a operação em campo. Ele representa a capacidade de fornecer energia contínua ao sistema. Na figura aparecem:  
    
    - Bateria / Fonte 5V : Indicando que a estação pode ser alimentada por uma fonte externa de 5V ou, para autonomia, por um sistema de bateria, que pode ser recarregável por energia solar.  

Apresentam-se, a seguir, mais detalhes da estrutura do projeto.  

Figura 2: Diagrama de Blocos da Estação Meteorológica  
**Figura 2:** Diagrama de Blocos da Estação Meteorológica  

A figura 2 ilustra o **Diagrama de Blocos da Estação Meteorológica**, delineando a arquitetura modular proposta para o projeto. Cada bloco representa um subsistema chave, interconectado para garantir a funcionalidade completa do dispositivo. Essa organização modular, requisito primordial do projeto, é fundamental para a flexibilidade do desenvolvimento, a facilidade de manutenção e a escalabilidade futura, permitindo que novos sensores ou módulos sejam integrados de forma eficiente. O diagrama serve como um mapa visual da estrutura lógica do sistema, guiando a implementação e o entendimento das interações entre os componentes.  

Figura 3: Fluxo de Dados e Energia  
**Figura 3:** Fluxo de Dados e Energia  
  
A figura 3 detalha o **Diagrama de Blocos da Estação Meteorológica**, com a representação esquemática que ilustra a interconexão funcional dos principais subsistemas do projeto. Este diagrama ajuda a visualizar a arquitetura modular da estação e o fluxo de dados e energia entre os distintos módulos da estação meteorológica.  

Figura 4: Estrutura Modular de Energia  
**Figura 4:** Estrutura Modular de Energia  

A figura 4 apresenta a **Estrutura Modular de Energia**, ilustrando as conexões e interações entre os subsistemas de gerenciamento de energia, ressaltando o foco do projeto na autonomia energética, mesmo em locais remotos.  

Cada bloco tem as seguintes funções:  

- **Fontes de Energia Primária:** as fontes de energia representam diferentes formas de geração elétrica, permitindo diversificação de entrada e assegurando o funcionamento da estação em diferentes cenários ambientais.  
- **Painel Solar:** geração fotovoltaica baseada em incidência de luz solar. Ideal para locais abertos com boa exposição solar. Deve ser dimensionado para suprir o consumo da estação e recarregar a bateria.  
- **Gerador Eólico:** utiliza a força do vento para gerar energia. Complementa o painel solar em dias nublados ou períodos noturnos com boa ventilação.  
- **Célula de Combustível:** conversão de energia química (etanol, hidrogênio, etc.) em eletricidade. Opção de alta autonomia e baixo impacto ambiental. Útil como backup em ocasiões de baixa insolação e vento.  
- **Rede Elétrica Convencional:** fonte direta de 127/220V AC com conversão para carga DC. Pode ser usada em propriedades com infraestrutura elétrica instalada como fonte principal ou redundante.  
- **Carregadores de Bateria:** cada fonte primária possui um carregador de bateria dedicado, responsável por:
    - Controlar a tensão e corrente de carga.  
    - Evitar sobrecarga ou descarga profunda.  
    - Isolar eletricamente fontes diferentes.  
Esses módulos são otimizados conforme a natureza da fonte:  
        - MPPT (Maximum Power Point Tracking) para painéis solares.  
        - Reguladores lineares ou buck/boost para rede elétrica e célula combustível.  

- **Bateria Secundária 12V:** atua como reserva central de energia, mantém a alimentação da estação quando as fontes primárias não estão gerando energia. Deve ser de tecnologia recarregável, preferencialmente LiFePO₄ ou AGM (Absorbent Glass Mat), que oferecem boa estabilidade térmica e número de ciclos e com capacidade (Ah) dimensionada para no mínimo 7 dias de autonomia contínua.  

- **Regulador 12V → 5V:** responsável por fornecer tensão estável de 5V DC, compatível com a maioria dos componentes do sistema. Deve ser eficiente (preferência por reguladores comutados tipo buck converter) para minimizar perdas por aquecimento.  

- **Saída 5V:** ponto final da cadeia de energia, entregando a tensão necessária para os módulos do sistema. Pode incluir proteções adicionais, como polyswitch (PTC) para sobrecorrente, TVS diodes para surtos de tensão, além de filtros LC para estabilidade e eliminação de ruído.  

- **Considerações Técnicas e de Projeto:**  
    - Eficiência Energética: a escolha de fontes e reguladores prioriza o baixo consumo e alta eficiência energética, fator essencial para operação ininterrupta no campo.  
    - Escalabilidade: o sistema permite a inclusão de novas fontes ou substituição de módulos sem afetar o funcionamento geral, favorecendo manutenção e expansão.  
    - Monitoramento: opcionalmente, sensores de tensão e corrente podem ser integrados à CPU para monitorar o estado de carga da bateria e alertar o servidor em caso de falhas.  

Figura 5: Estrutura do Canal de Comunicação Wi-Fi  
**Figura 5:** Estrutura do Canal de Comunicação Wi-Fi  

O canal Wi-Fi é o meio principal de comunicação da estação meteorológica com o mundo externo, sendo responsável por transmitir os dados coletados para um **servidor remoto** via internet. Ele explora os recursos nativos do **Raspberry Pi Pico W**, que já integra módulo Wi-Fi 802.11 b/g/n, garantindo simplicidade de hardware e conectividade eficiente. Os blocos funcionais do Canal Wi-Fi, são:
- **Raspberry Pi Pico W:**  
    - Atua como ponto central de coleta, processamento e transmissão dos dados.  
    - Lê os sensores periodicamente, organiza os dados (brutos e processados) e prepara os pacotes de comunicação.  
    - Realiza a conexão Wi-Fi com SSID e senha configuráveis via firmware.  
    - Implementa protocolo MQTT, HTTP REST ou WebSocket (definir), conforme definido na fase de integração com o backend.  

- **Roteador Wi-Fi / Hotspot:**  
    - Dispositivo intermediário que fornece acesso à internet.  
    - Pode ser um roteador doméstico ou hotspot 4G/5G.  
    - Atua como gateway entre a rede local (LAN) e a internet pública.  

- **Servidor Remoto:**  
    - Recebe os dados da estação para visualização, armazenamento e análise.  
    - Pode estar implementado em nuvem (ex: AWS, GSP, Azure, Heroku) ou em um servidor próprio ("on premises").  
    - Compatível com plataformas de dashboards como **Grafana**, que acessa os dados via banco de dados (InfluxDB, PostgreSQL etc.).  
    - Também pode expor uma API REST para integração com sistemas de terceiros.  

Outros aspectos importantes relativos ao canal de comunicação, são:  
- **Segurança e Confiabilidade:**  
    - **Criptografia TLS (opcional):** pode ser implementada para proteger os dados transmitidos.  
    - **Reconexão automática:** o firmware do Pico W deve implementar lógica de reconexão automática em caso de perda de sinal.  
    - **Fallback local:** se o Wi-Fi estiver indisponível, os dados podem ser armazenados localmente no cartão SD, garantindo que nenhuma medição seja perdida.  

- **Vantagens:**  
    - **Alta taxa de transmissão**, ideal para dados contínuos e históricos.  
    - **Compatível com redes residenciais e empresariais.**  
    - **Baixo custo de implementação**, pois não exige hardware adicional além do Pico W.  

Figura 6: Estrutura do Canal de Comunicação LoRa  
**Figura 6:** Estrutura do Canal de Comunicação LoRa  

O **canal LoRa (Long Range)** representa uma alternativa de comunicação de **longo alcance e baixo consumo energético**, ideal para locais onde **não há cobertura Wi-Fi** confiável. Ele é especialmente indicado para aplicações rurais e remotas e atua como canal **secundário** ou complementar de envio de dados na estação meteorológica. Seus blocos funcionais são descritos a seguir:  
- **Raspberry Pi Pico W:**  
    - Responsável pela coleta dos dados dos sensores.  
    - Usa a interface **SPI** para se comunicar com o módulo LoRa externo (ex: SX1276/SX1278).  
    - Monta os pacotes de dados e envia periodicamente via LoRa.  
    - Pode implementar uma lógica de fallback: se o Wi-Fi falhar, o LoRa é ativado e se ambos falharem armazena os dados localmente no cartão SD.  

- **Módulo LoRa + Antena:**  
    - Dispositivo físico que implementa o protocolo LoRa (modulação, controle de potência, canal etc.).  
    - Conectado via SPI à CPU.  
    - A antena deve ser posicionada com boa visibilidade e isolamento para maximizar o alcance (até vários quilômetros, dependendo do ambiente).        
    - Frequência usada no Brasil: **915 MHz**.  

- **Gateway LoRa:**  
    - Dispositivo receptor que escuta os pacotes LoRa enviados pela estação.  
    - Pode ser dedicado (ex: RAK831, Dragino) ou construído com outro Pico W, ESP32 ou Raspberry Pi com módulo LoRa.  
    - Conectado a um roteador ou modem com acesso à internet.  
    - Realiza o "salto" dos dados da rede LoRa para a internet via Wi-Fi, Ethernet ou 4G.  

- **Servidor Remoto**  
    - Mesma função da estrutura Wi-Fi: recebe, armazena e exibe os dados em dashboards, como Grafana.  
    - Pode processar os dados recebidos diretamente do gateway ou via **rede LoRaWAN**, se houver um backend com protocolo como **The Things Stack**.  

Há algumas considerações técnicas e estratégicas que são dignas de nota:
    - **Alcance:** pode chegar a **10 km em campo aberto**, com consumo muito menor que Wi-Fi.  
    - **Baixo consumo:** ideal para dispositivos alimentados por energia solar ou baterias.  
    - **Baixa taxa de dados:** o LoRa transmite pequenos pacotes (tipicamente até 255 bytes), o que é suficiente para leituras periódicas de sensores.  
    - **Robustez:** funciona bem em áreas sem cobertura celular ou Wi-Fi.  

O projeto da estação meteorológica considera um modelo **híbrido**, ou seja:
    - Usa **Wi-Fi como canal primário** (alta taxa e velocidade).  
    - Usa **LoRa como canal secundário ou redundante**, quando o Wi-Fi falhar ou for insuficiente.  
    - Permite comunicação **assíncrona e resiliente**, garantindo que os dados cheguem ao destino mesmo em situações adversas.  

Figura 7: Estrutura de Armazenamento Local  
**Figura 7:** Estrutura de Armazenamento Local  

A estrutura de armazenamento local é responsável por **registrar os dados ambientais coletados** pela estação meteorológica em **memória não volátil**, permitindo a retenção mesmo sem conectividade com o servidor remoto. Essa funcionalidade é essencial para garantir **resiliência**, **confiabilidade** e **continuidade** no registro dos dados.  Os blocos funcionais do Armazenamento Local, são:  
- **Raspberry Pi Pico W:**  
    - Coleta dados dos sensores a cada intervalo definido (ex: 10 segundos).  
    - Organiza os dados em estruturas (ex: arquivos CSV, binários ou JSON).  
    - Realiza o salvamento dos dados em memória local via barramento SPI (usualmente).  

- **Módulo de Cartão MicroSD:**  
    - Utiliza comunicação SPI com o Pico W.  
    - Permite escrita e leitura em arquivos do sistema FAT32, que podem ser acessados facilmente em PCs.  
    - Armazena os seguintes tipos de dados:  
        - Leituras brutas (alta frequência)  
        - Médias temporais (10min, 12h, 24h)  
        - Logs de erro de sensores  
        - Estados do sistema (nível de bateria, status da conexão etc.)  
        - Suporta arquivos de log contínuo com rotação por data/hora.

- **Vantagens da Arquitetura:**  
    - **Continuidade de operação**: garante que nenhuma leitura se perca em caso de falhas na comunicação (Wi-Fi ou LoRa).  
    - **Facilidade de acesso local**: o cartão SD pode ser removido e lido diretamente em qualquer computador.  
    - **Flexibilidade de formatos**: permite salvar os dados em formatos customizados para diferentes aplicações.  

- **Considerações Técnicas:**  
    - Recomenda-se **uso de bibliotecas otimizadas** para SD (ex: FatFS ou pico\_sd\_card).  
    - É importante prever verificação de integridade (checksums) e estratégias de **rotação de arquivos** para evitar excesso de escrita em um mesmo setor do cartão (aumentando a vida útil).  

A estrutura de armazenamento local é especialmente útil em contextos onde a comunicação pode ser **intermitente** ou **indisponível por longos períodos**, como zonas rurais ou remotas. Ela forma o elo de segurança da arquitetura, garantindo a **persistência dos dados ambientais**.  

Figura 8: Estrutura de Monitoramento Remoto  
**Figura 8:** Estrutura de Monitoramento Remoto  

Esta estrutura representa como os dados fluem para que o usuário possa ter acesso a eles via internet.

- **Container Node.JS:**  
    - É o ponto de acesso pelo qual o dispositivo IoT enviará os dados.

- **Container PostgreSql:**  
    - Armazena os dados Recebidos

- **Container Grafana:**  
	- Gera os DashBoards

---

### FLUXOGRAMA DO SOFTWARE

A **Figura 9** apresenta a *estrutura lógica do código da CPU* da estação meteorológica, modelada para explorar os dois núcleos disponíveis no microcontrolador **RP2040** presente no Raspberry Pi Pico W. O diagrama ilustra a divisão funcional entre os núcleos 0 e 1, bem como a interação com a memória compartilhada, responsável por armazenar dados, ponteiros e parâmetros de configuração. Essa organização visa maximizar a eficiência do sistema, permitindo o processamento paralelo e a separação clara entre tarefas críticas de aquisição e rotinas de comunicação.  

Figura 9: Fluxograma CPU  
**Figura 9:** Fluxograma do Código da CPU  

Os blocos mais importantes da figura incluem: no **Núcleo 0**, a inicialização do Núcleo 1 e o controle da comunicação remota, operando em um loop contínuo após configurar os drivers. No **Núcleo 1**, destacam-se a inicialização dos sensores e a configuração da interrupção de aquisição, que permite leituras em tempo real sem bloqueios. A **memória compartilhada** atua como elo entre os dois núcleos, garantindo o acesso sincronizado aos dados coletados e parâmetros de configuração da estação, o que é essencial para a robustez e confiabilidade da operação multitarefa.  

A **Figura 10** ilustra o *fluxograma da estrutura principal do Núcleo 0* do microcontrolador RP2040, responsável por gerenciar a comunicação externa da estação meteorológica, a interação com o Núcleo 1 e o controle de integridade do sistema via watchdog. Esse núcleo é encarregado pelas tarefas de supervisão e transmissão de dados, funcionando continuamente em loop e garantindo que a estação esteja sempre conectada e sincronizada com o servidor ou gateway, além de coordenar o envio das mensagens processadas.  

Figura 10: Fluxograma Núcleo 0 - Base  
**Figura 10:** Fluxograma para o Núcleo 0  

Entre os elementos mais relevantes da figura estão: a **verificação e ativação do link de comunicação**, o **gerenciamento de mensagens recebidas e transmitidas**, e a **sincronização com o Núcleo 1** por meio de mensagens internas. Destaca-se também o controle do **WatchDog**, que garante a reinicialização do sistema caso ele entre em estado de falha ou travamento. A estrutura implementa verificações para confirmar se o link está ativo, se há mensagens a enviar, e se estas foram efetivamente transmitidas, com tentativas de reenvio em caso de falha, demonstrando uma lógica resiliente e adequada a ambientes com conectividade intermitente.  

As **Figuras 11 e 12** apresentam os *fluxograma da estrutura principal do Núcleo 1* do microcontrolador. Esse núcleo é responsável pela aquisição e preparação dos dados dos sensores, leitura dos parâmetros da estação e atualização da memória Flash. Além disso, realiza o controle dos contadores de eventos (como anemômetro e pluviômetro), a configuração das interrupções de leitura e o encaminhamento de mensagens com dados ambientais para o Núcleo 0, que se encarrega da transmissão externa.  

Figura 11: Fluxograma Núcleo 1 - Base  
**Figura 11:** Fluxograma para o Núcleo 1 (básico)  

As principais características do diagrama incluem: a **inicialização dos sensores I2C, I1C e entradas analógicas**, a **inicialização da interrupção de aquisição de dados** (que permite capturas precisas e não bloqueantes), e a **detecção de solicitações do Núcleo 0** para alteração dos parâmetros da estação, os quais são gravados na Flash. Destaca-se também a **lógica de tratamento de mensagens pendentes**, com verificações de envio e o uso de uma **estrutura FIFO circular**, que assegura a ordenação das mensagens e sua transferência controlada. Ao final de cada ciclo, o watchdog é atualizado, contribuindo para a estabilidade e segurança do sistema.  

A **Figura 12** apresenta o *fluxograma da rotina de interrupção de aquisição de dados* executada no **Núcleo 1** da estação meteorológica. Essa rotina é acionada periodicamente, com o objetivo de realizar a coleta das variáveis ambientais em instantes precisos. A interrupção é responsável por reunir todas as leituras instantâneas, estruturá-las e prepará-las para posterior envio ao servidor via o Núcleo 0.  

Figura 12: Fluxograma Núcleo 1 - Interrupção de Aquisição  
**Figura 12:** Fluxograma para o Núcleo 1 (interrupções)  

Entre as etapas mais relevantes, destacam-se: a **leitura dos sensores**, segmentada por protocolo — **I2C**, **I1C**, e **analógicos** — além da **leitura e reinicialização do contador de pulsos**, utilizado para sensores como anemômetros ou pluviômetros. Após a leitura, os dados são organizados em uma estrutura padrão e gravados no **buffer circular na memória Flash**, o que garante o registro cronológico e persistente. Em seguida, um **flag de disponibilidade de dados** é ativado, permitindo que o fluxo principal do Núcleo 1 prepare a transmissão. Por fim, os dados mais recentes são utilizados para **atualizar o display local**, fornecendo feedback imediato ao usuário. Essa abordagem garante precisão, reatividade e confiabilidade na aquisição dos dados ambientais.

### PRINCIPAIS CONEXÕES E GPIOS UTILIZADOS

| Componente | Interface | Endereço | Conector | GPIO |
| :-: | :-: | :-: | :-: | :-: |
| BME680 | I2C | 76-77 | J20-JST | 02 e 03|
| BME280 | I2C | 76-77 | J20-JST | 02 e 03|
| BMP280 | I2C | 76-77 | J20-JST | 02 e 03|
| ATH10 | I2C | 38 | J20-JST | 02 e 03|
| Anemômetro - HMC5883 | I2C | 3C | J20-JST | 02 e 03|
| Anemômetro - HALL | Pulse | - | J2-IDC  | 09 |
| Biruta - HMC5883 | I2C | 3C | J20-JST | 02 e 03|
| Pluviômetro - HALL | Pulse | - | J21-JST | 01|
| BH1750 | I2C | 23 | J20-JST | 02 e 03|
| GY33 | I2C | 29 | J20-JST | 02 e 03|
| DS1307 | I2C | 68 | J20-JST | 02 e 03|
| DS3231 | I2C | 68 | J20-JST | 02 e 03|
| Memory card | SIO | - | J2-IDC  | Cartão de expansão |
| AD card | SIO | - | J2-IDC  | Cartão de expansão |  
| LoRA card | SIO | - | J2-IDC  | Cartão de expansão |  

Obs.1: Endereço se refere ao endereço I2C;
Obs.2: Endereços repetidos indicam que apenas 1 dos componentes estarão instalados.

Componentes com saída analógica utilizarão o AD Card.
Obs.: As portas analógicas serão configuráveis por software

| Componente | Função |
| :-: | :-: |
| LM35 | Temperatura |
| GUVA-S12SD | UV |
| SEN0193 | Umidade do solo |
| MQ-131 | Qualidade do Ar: ozônio |
| MICS-6814  | Qualidade do Ar: CO, NH3, NO2 |
| NHZ-14A | Qualidade do Ar - CO2 |

---

### Obs.: A concepção geral da estação, apresentada acima, foi desenvolvida com uma arquitetura altamente modular, visando facilitar futuras expansões e manutenções. No entanto, nesta etapa inicial do projeto, e em função das limitações temporais, será implementado apenas o subconjunto mínimo necessário para assegurar a funcionalidade básica do sistema.

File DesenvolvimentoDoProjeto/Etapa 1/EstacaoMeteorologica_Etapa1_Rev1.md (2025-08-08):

# EMBARCATECH - FASE 2

## Projeto Final - Etapa 1 (16/07/2025)
Revisão 1: 08/08/2025

---

# Estação Meteorológica para o Agronegócio e a Agricultura Familiar

## Autores:                     Carlos Martinez Perez e Ricardo Jorge Furlan

---

### 1. INTRODUÇÃO

O agronegócio e a agricultura familiar, pilares fundamentais da economia global e brasileira, têm vivenciado uma transformação sem precedentes impulsionada pela adoção de novas tecnologias. A **"Agricultura 4.0"** ou **"Agricultura de Precisão"** representa a convergência de diversas inovações, como a Internet das Coisas (IoT), inteligência artificial, big data e automação, para otimizar processos, aumentar a produtividade e promover a sustentabilidade no campo. Nesse cenário, a capacidade de coletar e analisar dados em tempo real sobre as condições climáticas e do solo torna-se um diferencial competitivo para todos os produtores rurais.

#### 1.1 Objetivo do Projeto:

Este projeto visa o desenvolvimento de uma estação meteorológica inteligente, autônoma e modular, projetada especificamente para atender às demandas tanto do **agronegócio** quanto da **agricultura familiar**. O principal objetivo é fornecer aos produtores rurais dados precisos e localizados de temperatura, umidade do ar e do solo, pressão atmosférica, luminosidade (visível e UV), velocidade e direção do vento, em tempo real.  

#### 1.2 Justificativa:

A tomada de decisões no planejamento e na gestão das lavouras é diretamente influenciada pelas condições climáticas e do solo. A falta de informações detalhadas e específicas para cada microclima da propriedade, muitas vezes, leva a práticas ineficientes e/ou ineficazes. Ao disponibilizar dados climáticos e de solo com alta granularidade e de forma contínua, este projeto busca promover o conhecimento e a educação no campo, permitindo ao produtor rural:

* **Compreensão e Análise da Irrigação:** Decisões de irrigação baseadas na real necessidade hídrica das plantas, usando dados concretos para evitar o desperdício de água e o estresse hídrico, com foco em uma gestão mais consciente.
* **Aprendizagem sobre o Manejo de Culturas:** Melhor planejamento de atividades agrícolas como plantio e colheita, com base no conhecimento das condições que favorecem o desenvolvimento das culturas e na identificação de padrões favoráveis ou desfavoráveis.
* **Racionalização de Insumos e Consciência Ambiental:** Incentivar o uso mais eficiente da água, fertilizantes e outros insumos a partir do conhecimento de seu impacto nas condições locais, minimizando a pegada ambiental e os custos.
* **Capacitação e Resiliência:** Capacitar o produtor com informações para tomar decisões mais ágeis e fundamentadas, o que aumenta a resiliência da propriedade frente a eventos climáticos e promove uma gestão mais autônoma.

### 2. IDENTIFICAÇÃO DO PROBLEMA

Produtores rurais, tanto no agronegócio quanto na agricultura familiar, enfrentam desafios na tomada de decisões precisas sobre o manejo de suas culturas devido à carência de dados microclimáticos e de solo localizados e em tempo real. Essa lacuna de informação resulta em um deficit de conhecimento que pode levar a:

* **Manejo Hídrico Subjetivo:** Uso inadequado da água, seja por excesso (desperdício de recursos e lixiviação de nutrientes) ou por escassez (estresse hídrico e perdas de produtividade), pois não há dados para orientar as práticas.
* **Vulnerabilidade e Perdas:** Dificuldade em compreender as condições climáticas adversas específicas da propriedade (geadas, veranicos, chuvas intensas), bem como o ambiente ideal para o surgimento de pragas e doenças, aumentando os riscos para a produção.
* **Uso de Insumos sem Base de Conhecimento:** Aplicação de fertilizantes e defensivos de forma subótima, sem o amparo de dados reais do solo e do clima, o que leva a custos desnecessários e impactos ambientais evitáveis.
* **Planejamento Agrícola sem Fundamento:** Tomada de decisão sobre plantio e colheita baseada em estimativas ou dados regionais, que nem sempre refletem as condições pontuais da propriedade, limitando o potencial de conhecimento e aprendizado sobre a própria lavoura.

### 3.  REQUISITOS

#### 3.1 Requisitos Funcionais:

O sistema deverá ser capaz de executar as seguintes Medições de
Parâmetros Ambientais:
- Temperatura do Ar: Medição em graus Celsius (°C).
- Temperatura do solo: Medição em graus Celsius (°C).
- Umidade Relativa do Ar: Medição em porcentagem (%).
- Pressão Atmosférica: Medição em hecto-Pascal (hPa).
- Luminosidade: Medição em Lux.
- Intensidade UV: Medição em UV Index.
- Velocidade do Vento: Medição em metros por segundo (m/s) ou quilômetros por hora (km/h).
- Direção do Vento: Medição em graus magnéticos.
- Volume de Chuva (Precipitação): Medição em milímetros (mm).
- Umidade do Solo: Medição em porcentagem (%).
- Qualidade do Ar: Medida de parâmetros como: CO2, CO, O3, NH3, NO2, VOCs.
- Detecção de Descargas Elétricas: número de descargas ocorridas.

Coleta e Armazenamento de Dados:
- Realizar a coleta de dados de todos os sensores em intervalos definidos (ex: a cada 10 segundos para dados brutos, com resumos a cada 10 minutos, 12 horas e 24 horas para armazenamento histórico).
- Armazenar temporariamente os dados no Raspberry Pi Pico em caso de perda de conexão, utilizando um módulo de cartão de memória removível.  

Transmissão de Dados:
- Transmitir os dados coletados para um servidor remoto. A comunicação primária será via Wi-Fi e como opção LoRA, que farão a transmissão até um roteador (WiFi ou LoRa) para envio via internet até um servidor.

Visualização e Análise de Dados:
- Os dados serão acessíveis e visualizáveis através de uma plataforma como o Grafana, com dashboards personalizáveis e específicos para o agronegócio.
- Disponibilizar os dados via API REST e Web Socket para integração com outras plataformas.

Gerenciamento de Erros:
- O sistema deve reportar, ao servidor, erros dos sensores quando forem detectados.

#### 3.2 Requisitos Não Funcionais:
- Modularidade: O design do sistema será modular, permitindo a fácil adição ou substituição de sensores e componentes para satisfazer as necessidades especificas de cada usuário.
- Escalabilidade: O sistema deve ser capaz de suportar a implantação de múltiplas estações em diferentes locais, de forma que os dados possam ser facilmente agrupados.
- Autonomia Energética: Operação autônoma com baixo consumo de energia.
  Ainda, como opções, se vislumbram:
    - Módulo de bateria recarregável com substituição periódica.
    - Módulo de bateria recarregável com recarga por energia solar.
    - Módulo de bateria recarregável com recarga por célula de combustível movida a etanol.
- Robustez Física e Resistência à Intempéries: O encapsulamento eletromecânico será resistente a condições climáticas adversas (chuva, vento, sol, poeira, umidade).
- Manutenibilidade: Facilidade de manutenção e atualização de software e hardware em campo.
- Segurança (Básica): Proteção básica dos dados transmitidos para o servidor, principalmente relativos à: integridade, disponibilidade e confidencialidade.

### 4. LISTA INICIAL DE MATERIAIS
A lista seguinte contempla os principais componentes para uma implementação completa da estação. Os componentes para o MVP (Minimum Valuable Product - Produto Mínimo Viável), aparecem indicados.  

Sensores:
| Quantidade | MVP | Componente | Utilidade |
| :-: | :-: | :--- | :--- |
| 1 | | BME680 | Pressão |
| | | | Temperatura |
| | | | Umidade |
| | | | Qualidade do Ar |
| 1 | | BME280 | Pressão |
| | | | Temperatura |
| | | | Umidade |
| 1 | * | BMP280 | Pressão |
| | | | Temperatura |
| 1 | * | ATH10 | Umidade |
| | | | Temperatura |
| 1 | | Anemômetro com magneto + HMC5883 (ou sensor hall switch) | Velocidade do Vento |
| 1 | | Biruta com magneto + HMC5883 | Direção do Vento |
| 1 | | BH1750 | Luminosidade |
| 1 | | GY33 | Luminosidade "espectral" |
| 1 | | GUVA-S12SD | Índice UV |
| 3 | | LM35 | Temperatura do solo |
| 3 | | SEN0193 | Umidade do solo |
| 1 | | Pluviômetro de báscula | Pluviômetro |
| 1 | | MQ-131 | Qualidade do Ar - ozônio |
| 1 | | MICS-6814 | Qualidade do Ar - CO, NH3, NO2 |
| 1 | | NHZ-14A | Qualidade do Ar - CO2 |

Obs.: Nem todos os sensores serão implementados num primeiro momento do desenvolvimento, sendo apenas uma previsão para a estruturação do projeto.

Diversos:
| Quantidade | MVP | Componente | Utilidade |
| :-: | :-: | :--- | :--- |
| 1 | * | BitDogLab V6.3 | CPU |
| 1 | | RTC DS3231 ou DS1302 ou DS1307 | RTC (Real Time Clock) |
| 1 | * | Cartão de memória com módulo IDC | Armazenamento temporário |
| 1 | * | Cartão de expansão I2C com cabos | Módulo de expansão I2C |
| 1 | | Cartão de expansão IDC | Módulo de expansão IDC |
| 1 | | Módulo Lora IDC | Comunicação |
| 1 | | Módulo AD IDC | Conversor AD  |
| 1 | * | Fonte 5V | Alimentação |

A figura abaixo apresenta o diagrama estrutural da estação meteorológica, ilustrando a abordagem modular que fundamenta o projeto.
Cada bloco representa um subsistema autônomo, mas interconectado, garantindo flexibilidade, facilidade de manutenção e escalabilidade.
Essa arquitetura permite que os dados de diferentes sensores (temperatura, umidade, pressão, vento, chuva, luminosidade e umidade do solo) sejam coletados e processados de forma eficiente pelo Raspberry Pi Pico W, antes de serem transmitidos para um servidor remoto. A separação dos módulos otimiza o desenvolvimento e facilita futuras adaptações, reforçando o objetivo de criar um sistema robusto e versátil para o agronegócio.

Estrutura Simplificada da Estação Meteorológica

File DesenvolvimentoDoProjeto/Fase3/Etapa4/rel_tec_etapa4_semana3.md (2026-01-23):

# Relatório Técnico – Etapa 4 – Semana 3
## Consolidação da Documentação e Preparação Final do Protótipo

**Projeto:** Estação Meteorológica IoT  
**Período:** 19 a 25 de janeiro de 2026  
**Autores:** Antonio Crepaldi – Carlos Perez – Ricardo Furlan  

---

## 1. Introdução

A Semana 3 da Etapa 4 teve como objetivo a **consolidação final da documentação técnica do projeto**. Entretanto, dada a reorganização do hardware do projeto, detalhado mais à frente neste relatório, o grupo concentrou-se nessas atividades, visto que a documentação de instalação, configuração e operação da estação já teve sua estrutura praticamente consolidada na Fase 2 do programa Embarcatech.

---

## 2. Aspectos Abordados na Semana

As atividades dessa semana foram:  

- testes de validação da comunicação LoRaWAN junto ao Gateway e The Things Network (TTN);
- testes de carga de bateria com painel solar;
- desenvolvimento de novo hardware: definição de esquemático, layout e confecção da PCB do protótipo.

### 2.1 Testes de Validação LoRaWAN

Os testes de validação de LoRaWAN foram executados no laboratório da FEEC, junto ao Gateway e, usando o hardware previamente preparado com a BitDogLab, foi possível fazer chegar ao TTN o payload projetado com dados de bateria, temperatura e pressão.

### 2.2 Testes de Carregamento da Bateria

Foi verificada a possibilidade de carga da bateria da estação em dias nublados, garantindo a autonomia desejada. Além disso, várias condições de tensão que excedem as geradas pela placa solar foram testadas e aprovadas.

### 2.3 Desenvolvimento de novo hardware

A placa BitDogLab, em sua versão 7, carrega periféricos nativos, tais como, joystick, matriz de led, regulador de tensão, microfone e amplificador de áudio, display oled e buzzer, que não são necessários no projeto da estação meteorológica. Além disso, estes periféricos, mesmo não sendo utilizados, consomem energia, reduzindo significativamente a autonomia da estação.  
Assim, para mitigar essa condição indesejável, é necessário executar um grande retrabalho na placa, alterando seu propósito educacional. Nesse contexto, foi decidido pelo grupo a confecção de uma placa dedicada exclusivamente ao projeto da estação. Essa nova placa de face única, de tamanho compatível com a BitDogLab, consiste de Raspberry Pi Pico, regulador de tensão, carregador de bateria, bateria, chaves de operação e conectores para os sensores e a WCM, responsável pela comunicação LoRaWAN.  

---

## 3. Diagramas Atualizados

Como parte da consolidação, foram revisados e atualizados os seguintes diagramas:

- diagrama de arquitetura geral do sistema;
Diagrama Consolidado Estação

- esquemático da estação;
Layout

- layout da placa de circuito impresso.
Layout
Layout 3D

Esses diagramas refletem o estado atual do projeto e servem como apoio visual para entendimento rápido do sistema.

---

## 4. Organização e Versionamento do Repositório

O repositório do projeto está organizado visando clareza e manutenibilidade, com:

- separação clara entre firmware (Code), hardware e documentação (Docs);

- padronização de nomes de arquivos e pastas;

- inclusão de arquivos README explicativos.

---

## 5. Conclusão

A Semana 3 da Etapa 4 marcou um ponto de virada (turnning point), dado que foi resolvido pelo grupo a execução de uma placa consolidando todos os requisitos da estação, substituindo a BitDogLab. Isso se deveu ao fato de que os periféricos nativos da BitDogLab têm prioridade educacional. A prioridade da estação, por outro lado, é a autonomia energética.   
Assim, a próxima semana será de trabalho intenso para a montagem mecânica e instalação em campo do protótipo com a nova PCB.

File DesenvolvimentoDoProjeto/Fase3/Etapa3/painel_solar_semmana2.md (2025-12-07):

# Estudo Comparativo de Viabilidade Técnica e Económica: Estações Meteorológicas IoT

**Objecto:** Comparativo entre a arquitetura baseada no "Modelo Unicamp" (Painéis DIY + MP158) versus a Solução Profissional (Painel 10W + Step-Down Síncrono).
**Aplicação:** Alimentação de 9 Estações com BitDogLab (Raspberry Pi Pico W + ESP32 LoRa).

---

## 1. Resumo Executivo

A análise demonstra que a modernização dos componentes (painel solar e regulador de tensão) resulta numa **redução de custos superior a 65%**, aumenta a precisão dos sensores devido ao menor ruído elétrico e garante uma vida útil do equipamento superior a 10 anos.

---

## 2. Análise Financeira (Por Estação)

O impacto financeiro considera a substituição dos painéis e a troca do regulador MP158 pelo modelo Mini Síncrono.

| Item | Proposta Inicial (Unicamp + MP158) | Solução Otimizada (Resun 10W + Mini Step-Down) |
| :--- | :--- | :--- |
| **Painéis Solares** | R$ 227,20 (8 un.) | R$ 76,00 (1 un.) |
| **Regulador de Tensão** | ~R$ 15,00 (MP158) | ~R$ 9,00 (Mini Síncrono) |
| **Custo por Estação** | **R$ 242,20** | **R$ 85,00** |
| **Custo Total (9 Estações)** | **~ R$ 2.179,80** | **~ R$ 765,00** |
| **Economia Total Gerada** | — | **R$ 1.414,80** |

---

## 3. Comparativo: Painéis Solares

### A. Modelo Unicamp (Artesanal)
* **Arquitetura:** 8 placas laminadas (PET/Epóxi) ligadas manualmente.
* **Vulnerabilidades:** Degradação rápida do plástico (amarelecimento em < 3 anos), alta complexidade de soldadura (72 pontos de falha) e vedação precária.

### B. Solução Profissional (Recomendada)
* **Arquitetura:** Painel único Resun 10W.
* **Construção:** Vidro Temperado e Alumínio Anodizado (Certificação INMETRO).
* **Vantagens:** Instalação "Plug & Play", garantia de 12 anos e robustez contra granizo e radiação UV.

---

## 4. Comparativo: Reguladores de Tensão

A substituição do regulador MP158 pelo novo modelo Mini Step-Down Síncrono traz vantagens críticas para aplicações de IoT e sensores de precisão.

| Parâmetro Técnico | MP158 (Modelo Antigo) | Mini Step-Down Síncrono (Novo) | Veredicto |
| :--- | :--- | :--- | :--- |
| **Tecnologia** | Retificação Assíncrona (Diodo) | Retificação Síncrona (MOSFET) | **Novo é superior** |
| **Eficiência** | ~88% a 92% | Até **97.5%** | **Novo desperdiça menos energia** |
| **Output Ripple (Ruído)** | 30mV a 50mV | **10mV** | **Novo garante leitura estável dos sensores** |
| **Tamanho** | 42 x 16 mm | **26 x 15 mm** | **Novo facilita a integração na caixa** |
| **Aquecimento** | Moderado (pode exigir dissipador) | Mínimo (frio) | **Novo é mais seguro** |

> **Nota Técnica sobre o Ruído (Ripple):**
> O novo regulador possui um *ripple* de apenas 10mV. Para sensores climáticos (pressão, humidade), isto é crucial, pois evita flutuações nas leituras e previne reinícios inesperados do microcontrolador (Brownout).

---

## 5. Dimensionamento Energético (Balanço de Energia)

Considerando o hardware alvo (**BitDogLab**), o sistema é sobredimensionado para garantir operação contínua.

* **Consumo do Sistema:** ~1.2W (média).
* **Geração Painel 10W:** ~7W a 10W.
* **Margem de Segurança:** O painel gera aproximadamente **5x a 6x mais energia** do que o consumo, permitindo recarga rápida da bateria 18650 mesmo em dias com pouca incidência solar.

---

## 6. Arquitetura Final Sugerida

Para maximizar a eficiência, a segurança e a simplicidade de montagem das 9 estações:

1.  **Fonte:** 1x Painel Solar Resun 10W (18V).
2.  **Proteção:** 1x Diodo 1N4007 (No positivo, contra inversão de polaridade na instalação).
3.  **Conversão:** 1x Módulo Mini Step-Down DC-DC (R$ 9,00).
    * *Configuração:* Entrada 18V / Saída 5V USB.
4.  **Carga/IoT:** Placa BitDogLab.
    * *Conexão:* Via porta USB ou pinos VBUS/GND. A placa gere automaticamente a carga da bateria 18650 e a telemetria LoRaWAN.

---

## 7. Conclusão

A adoção do **Painel Profissional de 10W** combinada com o **Regulador Síncrono de Baixo Ruído** representa a melhor decisão técnica e económica.
O projeto ganha em **fiabilidade de dados** (energia limpa para sensores), **durabilidade física** (vidro/alumínio) e liberta orçamento substancial (R$ 1.400,00) que pode ser realocado para outros periféricos ou reservas de contingência.

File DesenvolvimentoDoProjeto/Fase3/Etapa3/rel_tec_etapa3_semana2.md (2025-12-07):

# **Relatório Técnico – Etapa 3 - Semana 2**  
## **Testes Funcionais Avançados**  
**Estação Meteorológica IoT – 02 a 08/12/2025**  
**Entrega:** 07/12 — **Reunião:** 15/12  
**Autores:** Antonio Crepaldi - Carlos Perez - Ricardo Furlan-

# **1. Introdução**

A Semana 2 da Etapa 3 teve como foco a execução de testes funcionais avançados para avaliar desempenho, tempo de resposta, estabilidade, consumo e robustez da comunicação da Estação Meteorológica IoT. Os testes desta fase permitem identificar gargalos, falhas de sincronismo e problemas de firmware ou hardware que só aparecem em operação contínua.

No entanto, o progresso foi parcialmente comprometido por atrasos na preparação de hardware crítico — especialmente o WCM (ESP32-C3 + RFM95W) — o que limitou a execução dos testes fim a fim com o TTN/ThinsBoard. Apesar disso, foram conduzidos os testes possíveis dentro do escopo atual, mantendo continuidade com a integração estabelecida na Semana 1.

Cabe ressaltar que, durante as próximas semanas, concomitante com a integração física das partes, deverão ser feitos os testes faltantes, efetivando as correções necessárias. sem comprometer o cronograma geral do projeto.

---

# **2. Metodologia de Testes**

### **2.1 Definição dos Casos de Teste**

Os casos de teste foram definidos com base na necessidade de avaliar o comportamento das partes do sistema já implementados em condições o mais próximo da realidade de operação, contornando as restrições já descritas. Os critérios para seleção incluíram:

* cobertura dos principais elementos do sistema (sensores, firmware, comunicação e energia);
* priorização de rotinas críticas para o funcionamento contínuo da estação;
* análise de pontos já identificados como sensíveis na Semana 1 desta etapa.

A matriz de cobertura contemplou:

* leitura dos sensores I²C,
* operação do GPS via UART,
* transmissão LoRa (ponto a ponto) e LoRaWAN (ainda pendente),
* montagem e envio do payload,
* ciclos de wake-up e consumo energético.

Com isso, foi preparado um **test plan** provisório contendo os testes de leitura, processamento, transmissão, latência, consumo, estabilidade do firmware e robustez da comunicação.

---

### **2.2 Ambiente e Ferramentas Utilizadas**

Os testes foram executados utilizando o hardware disponível até o momento:

* **BitDogLab (RP2040)** para leitura de sensores e montagem preliminar do pacote de telemetria;
* **WCM (ESP32-C3)** para testes iniciais do uplink LoRaWAN;
* **RFM95W** para validação da camada física LoRa.

A infraestrutura de rede foi composta por:

* servidor completo em Docker (ChirpStack),
* broker MQTT interno ao ChirpStack,
* simulador de gateway.

Foram utilizadas ferramentas auxiliares como multímetro, osciloscópio, interface serial para registro de comportamento. As versões do firmware foram registradas para rastreabilidade dos resultados obtidos.

---

### **2.3 Procedimentos**

Cada teste foi repetido diversas vezes para garantir consistência nos resultados, com repetição mínima de 5 ciclos por caso de teste. Os critérios de aceitação incluíram estabilidade da leitura, coerência do tempo de resposta e ausência de falhas inesperadas durante o ciclo completo.

---

# **3. Resultados dos Testes**

## **3.1 Desempenho Geral**
Assim que disponível o hardware faltante, o firmware necessário e a total integração do sistema, deverão ser efetivadas as seguintes medições:  
- Tempo médio de leitura de sensores:  
    - BMP280  
    - GPS  
    - Batery level  
- Tempo de processamento interno:  
    - Tempo para inicialização do sistemae carregamentoi da tela de configuração  
    - Tempo entre acordar, colher dados, montar o payload e enviar para transmissão  
    - Tempo de desativação de módulos para voltar a dormir  
    - Tempo total do ciclo completo  

## **3.2 Tempo de Resposta e Latência**

Assim que a comunicação LoRaWAN for integrada ao projeto, os seguintes dados de testes deverão ser obtidos para uma análise completa de desempenho:  
    - Tempo de envio do pacote via LoRaWAN → Servidor de rede.  
    - Análise de variabilidade (jitter).  

## **3.3 Estabilidade do Firmware**
Da mesma forma, com o sistema totalmente integrado, deverão ser observados os seguintes itens:  
    - Ocorrência de resets inesperados.  
    - Validação do funcionamento do watchdog.  
    - Ocorrência de leituras inconsistentes.  

## **3.4 Consumo de Energia**
Foram coletados, preliminarmente, ainda com o firmware em desenvolvimento, os seguintes valores de consumo de energia:  
* Raspberry Pi Pico:  
    - Corrente em simulação de deep sleep (clock reduzido): 1,7 mA
    - Corrente com clock default: 22 mA
* WCM (ESP32 + RFM95W): apenas com protocolo LoRa
    - ESP32-acordado (não transmitindo, nem recebendo  dados): 25 mA  
    - ESP32-acordado e recebendo dados: 35 mA  
    - ESP32-acordado e transmitindo dados: 90mA, com pouca alteração em diversas potências de transmissão 
    - ESP32 em light sleep: 0,5 mA  

Corrente Transmissão

corrente Recepção

Com a incorporação do firmware e tendo a estrutura de comunicação bem estabelecida, os seguintes consumos deverão ser ainda confirmados:  
* Corrente durante transmissão LoRaWAN.  
* Estimativa de autonomia diária baseada nas medições.  

## **3.5 Robustez da Comunicação**
Igualmente, os itens abaixo só poderão ser avaliadois assim que a nova versão de hardware e o novo firmware do WCM estiver pronta:  
    - Taxa de sucesso de pacotes.  
    - Pacotes não confirmados (quando aplicável).  
    - SNR e RSSI médios e extremos.  
    - Comportamento em paredes, distância e interferência.

---

# **4. Testes de Estresse**
Serão registrados aqui os testes pendentes que deverão ser levados a cabo quando da integração total do sistema:

## **4.1 Cenários-limite a Serem Aplicados**
- Transmissões repetidas com pouco intervalo.  
- Falhas induzidas (ex.: desconectar antena, reduzir bateria).  
- Ambiente com ruído eletromagnético.  

## **4.2 Comportamento a Ser Observado**
- Travamentos.  
- Degradação de desempenho.  
- Perda de pacotes.  
- Superaquecimento (se aplicável).  

---

# **5. Conclusão**

Mesmo sem muitos avanços nos testes de integração, pelos problemas já relatados acima, foram aplicados esforços em outros âmbitos com os recursos disponíveis:
* definição do payload de transmissão, essencial para a definição do ToA (Time on Air) e para apoiar a decodificação dos dados, além de influenciar no consumo de energia.  
* identificação dos principais gargalos de consumo de energia, gerando os pontos de atenção que deverão ser observados no desenrolar do projeto.
*  definição da estrutura básica do firmware da BitDogLab.

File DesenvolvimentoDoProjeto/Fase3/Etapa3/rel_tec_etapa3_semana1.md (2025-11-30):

# **Relatório Técnico – Etapa 3 - Semana 1**

### **Estação Meteorológica IoT – Integração Completa do Sistema**

**Autores:** Antonio Crepaldi – Carlos Perez – Ricardo Furlan
**Período:** 25/11 a 01/12/2025
**Entrega:** 30/11/2025

---

## **1. Objetivo da Semana**

A Semana 1 da Etapa 3 teve como foco a **integração completa do sistema**, conectando todos os módulos — sensores, atuadores, firmware, LoRaWAN, backend e dashboard. Os principais objetivos foram:

* Integrar todos os componentes físicos e lógicos do sistema.
* Garantir comunicação estável e coerente entre sensores → microcontrolador → transmissor → servidor → dashboard.
* Identificar conflitos de hardware, falhas de sincronismo e gargalos de comunicação.
* Validar o fluxo completo de dados, mesmo que ainda sem otimização.
* Consolidar a primeira versão totalmente integrada.

---

## **2. Estado Atual da Integração**

### **2.1 Módulos já validados anteriormente**

* Sensores em I²C1 funcionando de forma estável.
* GPS em UART decodificando NMEA com boa precisão.
* LoRa ponto-a-ponto validado com BitDogLab + RFM95W.
* Ambiente **ChirpStack** instalado e funcional com simulações MQTT.

### **2.2 Módulos integrados nesta semana**

* Esboço das rotinas de wake-up da BitDogLab, objetivando reduzir seu consumo.
* Desenvolvimento de firmware para ESP32-C3 para comunicação LoRa P2P, visando ativação do modo sleep para baixo consumo.
* Implementação em código Java para simular a montagem de Pyloads para tansmissão via MQTT para TTN/ChirpStack.

### **2.3 Integrações pendentes**

* Migração do simulador de payload de Java para C.
* Teste real de uplink LoRaWAN por falta de hardware.
* Integração com placas solares.
* Integração com dashboard final.

---

## **3. Atividades Realizadas**

### **3.1 Integração física e lógica**

* Revisão completa do cabeamento entre módulos.
* Testes funcionais dos sensores com o Pico W.
* Validação do SPI com o RFM95W.
* Testes de deep sleep.

### **3.2 Firmware do WCM (ESP32-C3 + RFM95W)**

* Desenvolvimento de firmware para transmissão e recepção de LoRa com sleep mode habilitado.
* Rotinas de publicação MQTT para o servidor ChirpStack.

### **3.4 Backend e infraestrutura**

* Testes de ingestão MQTT no ChirpStack.
* Preparação para integração com ThingsBoard/Grafana.

---

## **4. Problemas Encontrados (Buglist Inicial)**

| Categoria | Descrição | Status |
| --- | --- | --- |
| Firmware WCM | Diferenças entre estrutura Java e C dificultam montagem do payload | Em andamento |
| LoRaWAN | Join e uplink reais não testados | Pendente |
| Energia | Falta medição real de consumo | Pendente |
| SPI RFM95W | Monitoramento de estabilidade após solução do conflito no GPIO28 | OK |
| Dashboard | ThingsBoard ainda não configurado para múltiplas estações | Pendente |

---

## **5. Tabela de Verificação da Comunicação entre Módulos**

| Módulo | Protocolo | Status | Observações |
| --- | --- | --- | --- |
| Sensores → BitDogLab | I²C1 | OK | Estável |
| GPS → BitDogLab | UART | OK | Estável |
| BitDogLab → RFM95W | SPI | OK | Estável |
| BitDogLab → WCM | UART | OK | Estável |
| WCM → Gateway | LoRaWAN | Pendente | Aguardando teste real |
| Gateway → TTN | UDP/MQTT | Funcional com simulação | Converter em desenvolvimento |
| TTN → Dashboard | MQTT/HTTP | Pendente  | Aguardando teste real |

---

## **6. Registro Fotográfico**

* WCM controlado via adaptador serial:

Foto1

---

## **7. Conclusão da Semana**

A Semana 1 da Etapa 3 marcou o início da integração total do sistema, com avanços no firmware do WCM, na lógica do payload e na estrutura de telemetria e certa estagnação nos teste reais de integração do gateway LoRaWAN por falta de hardware.

---

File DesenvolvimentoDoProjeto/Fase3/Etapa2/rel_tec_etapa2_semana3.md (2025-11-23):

# **Relatório Técnico – Etapa 2 / Semana 3**

**Estação Meteorológica IoT com Comunicação LoRaWAN**
**Autores:** Antonio Crepaldi – Carlos Perez – Ricardo Furlan
**Data:** 23/11/2025

---

## **1. Objetivo da Semana**

A Semana 3 da Etapa 2 teve como prioridade **consolidar o sistema parcialmente integrado**, avaliando estabilidade, coerência entre módulos e revisando o nível atual de maturidade tecnológica (**TRL**).

As atividades principais objetivaram:

* Consolidação das integrações realizadas nas semanas anteriores;
* Aprendizado e familiarização com as stacks **TTN e ChirpStack**, visando a sua integração na fase final;
* Simulações com a comunicação LoRa ponto a ponto;
* Simulações de tráfego LoRaWAN com containers Docker;
* Revisão de arquitetura e padronização do firmware;
* Avaliação de consumo do hardware atual e da geração de energia com placas solares;
* Análise realista do TRL do projeto neste momento.

---

## **2. Estado Atual do Sistema Integrado**

O andamento do projeto e seu cronograma foram impactados por fatores externos críticos:

* A ausência de placas WCM prontas, impossibilitando a etapa essencial de testes reais da comunicação LoRaWAN com ESP32-C3, gateway e servidor de rede;  
* O código original do projeto da WCM apresenta limitações quanto à implementação de downlink na comunicação LoRaWAN, essencial pára a efetivação da comunicação diferida da estação;  
* A utilização de deep sleep, essencial para o gerenciamento do consumo de energia da estação, não foi tampouco, implementado no projeto original.  

Esses fatores implicam num esforço adicional para a consecução do projeto e o cumprimento do cronograma previamente estabelecido.  

Com base na Semana 1 e 2, o sistema integrado até o momento inclui:

### **2.1 Comunicação e Sensores**

* Sensores I²C migrados para barramento **I2C1**, liberando I2C0 para UART/GPS;  
* GPS operando com leitura NMEA quando conectado;  
* Módulo LoRa **RFM95W** validado em operação ponto-a-ponto LoRa (não LoRaWAN) entre duas BitDogLab, com RSSI estável e parâmetros SF, BW e CR ajustáveis.  

### **2.2 Energia**

* Primeiros testes reais com placas solares mostraram **capacidade média estimada de 10 Wh/dia**.  

### **2.3 Testes do RFM95W**

* Os testes permitiram:

  * Troca de modo TX/RX/RSSI;  
  * Leitura de registradores do RFM95W (especialmente o 0x42 – VERSION);  
  * Mitigação do conflito no GPIO28 da BitDogLab com o microfone.  

### **2.4 Integração pendente (por falta de hardware WCM)**

* Testes LoRaWAN via ESP32-C3 (WCM) → adiados
* Teste real de uplink com gateway e servidor
* Coleta real de RSSI/SNR via TTN
* Visualização real dos dados no ThingBoard

---

## **3. Testes Realizados Esta Semana**

Mesmo sem o WCM, foram realizadas as tarefas possíveis previstas no plano:

### **3.1 Testes funcionais do sistema parcialmente integrado**

* Validação do comportamento dos sensores no novo barramento I2C (ok).
* Consolidação da comunicação LoRa P2P com BitDogLab + RFM95W.

### **3.2 Métricas coletadas**

Embora incompletas sem LoRaWAN, as métricas de LoRa puro são relevantes:

| Métrica | Valor |
| --- | --- |
| Sucesso de pacotes  | 100% com SF fixo e sincronizado |
| Estabilidade do SPI | validada pelo reg. 0x42 = 0x12  |

**Corrente Raspberry Pico**, programa de led Blink, alimentação 5V
| Condição | Corrente Led ON | Corrente Led OFF |  
| --- | :---: | :---: |
| Default | 21,7 mA | 19,4 mA |
| Pll USB Off | 19,8 mA | 18,0 mA |
| Pll USB Off<br>CLK=4MHz |  6,0 mA |  3,9 mA |
| Pll USB Off<br>CLK=4MHz<br>Pll Sys Off |  4,0 mA |  **1,7 mA** |

**Corrente módulo WCN**, alimentação 5V: 31 mA

**Corrente módulo LoRa(RFM95W Kit Avançado)**, alimentação 3,3 V:
- Sem comandos por software:
    - Sem Reset(Reset open): 2,2 mA
    - Com Reset(Reset ground): 0,9 mA
 - Sem comandos por software:
     - modo LoRa + Sleep: **1.6 uA**
     - LoRa Standby: 1.83 mA

**Corrente módulo de Bateria da BitDogLab V7**, Tensão da bateria 4,04V:
- Durante power-on(3leds acessos): 14,8 mA
- Após power-on(leds apagados): **263uA**
- Power off: 50uA

### **3.3 Estudos paralelos sobre TTN**

Como o WCM foi projetado originalmente para integração com **TTN (The Things Network)**, mantivemos estudo das diferenças:

| Item | TTN | ChirpStack |
| --- | --- | --- |
| Arquitetura | Cloud-first | On-premise / local |
| SLA | limitado | controlado pelo usuário |
| Segurança | integrada | configurável |
| Customização | baixa | total |
| Decodificadores | Web Console | qualquer backend |

Manteremos compatibilidade com **TTN** para os testes de integração. No futuro do projeto será possível avaliar a utilização alternativa do **ChirpStack**.

### **3.4 Testes Preliminares da infraestrutura ChirpStack**

A equipe conseguiu:

* executar o **ChirpStack via docker-compose**, incluindo:

  * chirpstack-gateway-bridge
  * chirpstack-network-server
  * chirpstack-application-server
  * redis
  * postgres
* acessar os painéis web;
* criar gateways simulados;
* simular uplinks MQTT;
* simular packages LoRaWAN;
* validar decodificadores JSON (codec).

Tudo isso permite o desenvolvimento da parte do servidor servidor, mesmo sem rádio ativo.

---

## **4. Análise Realista do TRL**

A seguir, uma análise crítica do nível de maturidade tecnológica.

### **4.1 Situação Atual**

Apesar dos avanços técnicos, **o TRL não evoluiu tanto quanto planejado**, pois o ponto central desta fase — **testes LoRaWAN reais** — depende do hardware WCM que ainda não está pronto.

### **4.2 Avaliação usando a escala TRL (NASA/EC)**

Escala resumida:

* **TRL 3 – Prova de conceito experimental**
* **TRL 4 – Validação de componentes em ambiente de laboratório**
* **TRL 5 – Validação integrada em ambiente relevante**
* **TRL 6 – Protótipo funcional demonstrado**
* **TRL 7 - Protótipo funcional em campo**

### **4.3 Diagnóstico atual do projeto**

Com base nas semanas 1–3:

| Elemento | Situação real | TRL |
| --- | --- | --- |
| Leitura de sensores | Validada e estável | TRL 5 |
| LoRa ponto-a-ponto | Validado em bancada | TRL 5 |
| Energia solar | pré-análise, sem integração real | TRL 3 |
| LoRaWAN com WCM | **não testado, por falta de hardware** | **TRL 2–3** |
| Infraestrutura TTN | configurada e simulada | TRL 4 |
| Sistema como um todo | parcialmente integrado | **TRL atual estimado: 3-4** |

### **4.4 Justificativa**

Estamos entre TRL 3 e 4, mas não alcançamos TRL 4 porque:

* ainda não existe **demonstração integrada LoRaWAN real**;
* o servidor está configurado, mas não há dados reais entrando;
* não foram realizados testes de downlink, join OTAA, ADR, SNR real etc.

A conclusão técnica é:
**O sistema ainda está em validação de componentes e integração parcial**, sem o protótipo final integrado.

---

## **5. Plano de Ação para a Fase Seguinte (Etapa 3)**

### **5.1 Assim que as placas WCM estiverem funcionais**

1. **Configurar e testar uplink LoRaWAN real** (SF, BW, CR).
2. Validar OTAA e ABP.
3. Registrar métricas reais:

   * SNR
   * RSSI no gateway
   * time-on-air
   * taxa de sucesso
4. Integrar decodificador TTN → The ThingsBoard.

### **5.2 Firmware**

* Unificar o firmware entre sensores, LoRaWAN e lógica de transmissão.
* Incorporar machine-checking simples (failsafe, watchdog).
* Testar duty-cycle.

### **5.3 Energia**

* Medir consumo real do WCM + CPU + sensores.
* Ajustar duty cycle e intervalo de transmissão.
* Validar autonomia real da estação.

### **5.4 Documentação**

* Atualizar repositório com versões consolidadas.
* Gerar gráficos e logs para TRL da Etapa 3.

---

## **6. Diagrama Consolidado do Sistema (Atual)**

Representa o sistema proposto atualizado para o momento:

Foto1  

---

## **7. Conclusão**

Apesar do atraso causado pela indisponibilidade das placas WCM, a Semana 3 foi produtiva dentro das limitações:

* consolidamos toda a base técnica desenvolvida;
* validamos sensores, LoRa P2P e parte da arquitetura de energia;
* iniciamos os estudos do ambiente ChirpStack, operando via Docker, como alternativa futura de escalabilidade;
* revisamos o TRL de forma realista, mantendo o projeto dentro de padrões adequados de engenharia.

O projeto segue tecnicamente sólido, com fundações robustas.
A chegada das placas WCM será o gatilho para avançar para TRL 5 e 6.

---

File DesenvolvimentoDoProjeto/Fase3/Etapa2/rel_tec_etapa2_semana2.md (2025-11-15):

# Estação Meteorológica IoT – Etapa 2 - Semana 2  
## Integração Parcial dos Módulos
#### Autores: Antonio Crepaldi - Carlos Perez - Ricardo Furlan

### 1. Objetivo
Esta etapa teve como finalidade integrar os módulos de hardware e software já desenvolvidos na Estação Meteorológica IoT, estabelecendo comunicação entre sensores e microcontrolador via diferentes protocolos e validando a coerência dos dados trocados.  

Os objetivos específicos incluíram:
- Implementar a comunicação entre sensores e microcontrolador;
- Validar protocolos I²C, SPI, UART e LoRa (WCM – ESP32-C3);
- Garantir sincronismo e estabilidade na coleta e transmissão de dados;
- Iniciar os testes para o uso de placa solar;
- Identificar e corrigir conflitos de hardware e software.

---

### 2. Testes de Integração Realizados

Foram conduzidos testes sistemáticos de comunicação e sincronismo entre os módulos:

1. **Atualização do barramento I²C:**  
   Os sensores I2C que estavam alocados no barramento i2c0 foram transferidos para o barramento i2c1 a fim de liberar aquele para a interface UART visando o uso do módulo GPS.  

2. **Transmissão via LoRa (RFM95W):**  
   Foi utilizado o módulo RFM95W (Escola 4.0) para iniciar os testes de comunicação LoRa ponto a ponto. Além disso, foram também realizados testes com o mesmo módulo do kit avançado de periféricos.  

3. **Análise de placas solares:**  
   Foram iniciadas as tratativas para a utilização de placas solares no projeto. Apesar de ainda não estarem integradas, as primeiras medições com o aplicativo Android Charge Meter, dão conta de uma geração de 1,3 W num dia nublado e 4,2 W com céu limpo. Esses dados implicam em uma geração média, considerando apenas 5 horas de insolação, de entre 6,5 Wh/dia e 21 Wh/dia. Isso resulta numa média de 13 Wh/dia. Com uma margem de 20% de perdas em conversão e armazenamento, sobrariam, para uso efetivo da estação, aproximadamente 10 Wh/dia, em média, variando entre 5,2 Wh/dia e 16,8 Wh/dia. Esses dados, ainda preliminares, adiconados aos dados da bateria (3,7 V e 2 Ah ou 7,4 Wh) permitirão o cálculo prévio de autonomia, após a definição dos payloads e medições mais detalhadas de consumo e tempo de leitura e envio dos dados dos sensores. Mas, pode-se estimar que esse arranjo tem o desafio de ser bem equilibrado para que a estação funcione normalmente mesmo com seguidos dias de tempo nublado. Lembar que as placas devem ser instaladas com suas faces voltadas para o Norte inclinadas 23 graus em relação á vertical.

---

### 3. Resultados e Análises
1. A troca em si do barramento I2C de i2c0 para i2c1 não implicou em complexidade técnica, inclusive pelo fato de, na sua versão 7, a BitDogLab já utilizar o display oled nos pinos 2 e 3, padrão do barramento, evitando conflito com os GPIOs anteriores (14 e 15). Os primeiros testes com o módulo GPS mostraram bons resultados com a comunicação NMEA permitindo a obtenção do posicionamento geográfico com boa precisão.  

2. Foi implementado um firmware para estudo, em linguagem C, que comunica duas BitDogLab via LoRa com três tipos de mensagens enviadas e recebidas, com medição de RSSI  e informação de SF, BW, CR, frequência e SNR. A princípio, na BitDogLab houve a necessidade de eliminar o conflito do circuito do microfone da placa com o pino de reset do módulo RFM95W (GPIO 28), que causava o travamento da comunicação. Isso foi realizado simplemente trocando a posição do jumper que seleciona se o GPIO 28 recebe o sinal diretamente do microfone, para uso de ADC, ou de uma fonte externa, apesar do esforço demandado em descobri-lo.
O firmware utilizado permite a seleção de função da placa BitDogLab como transmissora, receptora ou medidora de RSSI.  

---

### 4. Registro Fotográfico do Protótipo

A foto abaixo mostra os módulos RFM95W disponíveis para teste de comunicação.  

Foto1  

As placas solares sob teste estão mostradas abaixo:  

Foto2  

O objetivo é integrar esses módulos à estação meteorológica, que aparece abaixo:  

Foto3  

---

### 5. Diagrama de Integração Atualizado

O diagrama de integração atualizado aparece abaixo:  



---

### 6. Observações e Próximos Passos

Nessa etapa do projeto, o foco esteve em efetivar os primeiros testes de conexão via LoRa e no uso das placas solares.  Os resulatados se mostraram bastante promissores.

Próximos passos do projeto:  

- Definir as mensagens LoRaWAN (payload) que serão transmitidas, a fim de determinar o Time on Air (ToA) aquilatando os requisitos restritivos do servidor de rede.  
- Avaliar o consumo geral de energia para dimensionar o sistema de placas solares e determinar a autonomia em diferentes condições climaticas.  
- Estudo para reestruturação do firmware de modo a acomodar a restrição atual de implementação de downlink LoRaWAN para reconhecer quais dados foram enviados e adequadamente recebidos pelo servidor de rede.  
- Iniciar estudos para a caixa que abrigará os dispositivos em campo.  

---

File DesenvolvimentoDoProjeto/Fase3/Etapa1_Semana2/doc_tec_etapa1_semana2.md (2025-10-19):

# Documento Técnico Resumido
## Estação Meteorológica IoT – Projeto Embarcatech

### 1. Introdução
A Estação Meteorológica IoT tem como objetivo realizar medições ambientais em tempo real e disponibilizar os dados por meio de uma infraestrutura conectada à internet. O sistema integra sensores meteorológicos, módulos de comunicação, fontes de energia autônomas e um servidor de visualização com dashboards interativos no Grafana ou thingsboard.

O projeto segue uma arquitetura modular, escalável e energeticamente autônoma, desenvolvida para suportar múltiplas estações distribuídas em campo, atendendo tanto a demandas de pesquisa e ensino quanto a aplicações produtivas, como agricultura, pecuária e monitoramento ambiental.

---

### 2. Requisitos Consolidados

#### 2.1 Requisitos Funcionais
O sistema deve:
- Medir prioritariamente: **temperatura do ar**, **umidade do ar**, **pressão atmosférica**, **luminosidade** e opcionalmente: **índice UV**, **velocidade e direção do vento**, **volume de chuva**.
- Realizar **coleta periódica** de dados a cada 5 minutos.
- **Armazenar temporariamente** os dados localmente (memória flash ou cartão SD) para que em caso de falha de conexão os dados possam ser transmitidos após o restabelecimento da rede.
- **Transmitir os dados** para um servidor remoto via **Wi-Fi** (HTTP/HTTPS) ou **LoRaWAN** com gateway.
- Disponibilizar os dados através de **dashboards no Grafana ou thingsboard**.
- Reportar **falhas de sensores** e anomalias operacionais ao servidor.
- **Autonomia energética:** operação contínua com baterias recarregáveis e painéis solares.

#### 2.2 Requisitos Não Funcionais
- **Modularidade:** cada bloco do sistema (sensores, energia, comunicação, CPU) deve ser independente e substituível.
- **Escalabilidade:** suporte a múltiplas estações simultâneas em locais distintos.
- **Robustez física:** invólucro resistente a intempéries (chuva, vento, sol e poeira).
- **Manutenibilidade:** fácil atualização de firmware e hardware em campo.
- **Segurança básica:** integridade e confidencialidade dos dados transmitidos.

---

### 3. Diagrama de Blocos e Camadas
O diagrama **DiagramaDaEstacaoEServidor.png** representa a **arquitetura hierárquica da estação meteorológica IoT**.


#### 3.1 Camada de Sensores
Compreende os módulos responsáveis pela aquisição de dados ambientais. Os sensores estão divididos em quatro grupos:
- **Digitais(pulos):** anemômetro e pluviômetro.
- **I²C:** sensores de temperatura do ar, umidade, pressão atmosférica, direção do vento e RTC.
- **Analógicos:** índice UV.
- **Serial (UART):** GPS

Esses sensores se comunicam com a CPU principal via barramentos digitais (I²C, GPIO, UART) e entradas AD.

#### 3.2 Camada de Infraestrutura
Inclui os subsistemas de energia e monitoramento:
- **Fonte primária de energia:** alimentação principal (painel solar ou fonte externa).
- **Fonte secundária de energia(no-break):** Bateria, o que garante autonomia durante falta da fonte primária energia.
- **Módulo de integridade:** monitora tensões, corrente e status da bateria.

#### 3.3 Camada de Processamento
A **CPU** (ex.: Raspberry Pi Pico W) realiza:
- Leitura e pré-processamento dos sensores;
- Armazenamento temporário em memória;
- Opcionalmente comunicação com a interface do usuário (display local, comunicação serial, wifi).

#### 3.4 Camada de Transmissão
Responsável pela comunicação com o servidor remoto. O sistema oferece três opções:
1. **Wi-Fi (HTTP)** – comunicação simples com servidor web;
2. **Wi-Fi (HTTPS/TLS)** – comunicação segura e criptografada;
3. **LoRaWAN + Gateway** – comunicação de longo alcance para áreas remotas.

#### 3.5 Camada de Servidor e Visualização
Após o envio dos dados, o servidor executa as seguintes funções:
- **Recepção e armazenamento** dos dados em um banco **PostgreSQL**;
- **Serviço de integração, visualização e análise** com o **Grafana** ou **ThingsBoard** para interface com os usuários, permitindo consultas e gráficos e históricos.

---

### 4. Interfaces e Dependências Principais

| Interface | Tipo | Função | Dependência |
|:---:|:----:|---|---|
| **I²C** | Digital serial | Comunicação com sensores de temperatura, pressão, umidade, luminosidade e RTC | CPU ↔ Sensores |
| **GPIO / Interrupções** | Digital | Leitura de pulsos do anemômetro e pluviômetro | CPU ↔ Sensores |
| **Wi-Fi / HTTPS** | Comunicação | Envio seguro de dados ao servidor | CPU ↔ Servidor |
| **LoRaWAN** | Comunicação de longo alcance | Alternativa para áreas sem Wi-Fi | CPU ↔ Gateway ↔ Servidor |
| **Energia Solar / Bateria** | Alimentação | Fonte primária e reserva de energia | Infraestrutura ↔ CPU |
| **Grafana/ThingsBoard<br>PostgreSQL** | Software | Visualização e armazenamento de dados | Servidor ↔ Usuário |

---

### 5. Conclusão
A arquitetura proposta integra sensores, energia, comunicação e software em uma estrutura modular. O projeto consolida a transição para um sistema de monitoramento ambiental funcional, com armazenamento local, comunicação segura e visualização em tempo real, apto para evoluir de TRL 4 para TRL 7 até o final da Fase 3 do Programa Embarcatech.

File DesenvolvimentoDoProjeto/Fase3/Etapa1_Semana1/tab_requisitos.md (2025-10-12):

# 📋 Tabela de Requisitos do Projeto – Estação Meteorológica IoT

| Requisitos Funcionais | Requisitos Não Funcionais |
|---|---|
| - Medição de Temperatura do Ar (°C)<br>- Medição de Umidade Relativa do Ar (%)<br>- Medição de Pressão Atmosférica (hPa)<br>- Medição de Luminosidade (Lux)<br>- Medição de Velocidade do Vento (m/s ou km/h)<br>- Medição de Direção do Vento (graus magnéticos)<br>- Medição de Volume de Chuva (mm)<br>- Coleta periódica de dados em intervalos definidos (ex: 5min)<br>- Armazenamento temporário local em caso de perda de conexão (Flash ou cartão SD)<br>- Transmissão de dados via Wi-Fi e LoRa até o servidor remoto<br>- Visualização de dados em dashboards Grafana/ThingsBoard<br>- Relato de erros de sensores ao servidor | - Design modular para adição e substituição de sensores e componentes<br>- Escalabilidade para múltiplas estações em diferentes locais<br>- Autonomia energética com baixo consumo de energia<br>- Opção de bateria recarregável substituível<br>- Opção de recarga solar<br>- Encapsulamento resistente a intempéries (chuva, vento, sol, poeira, umidade)<br>- Facilidade de manutenção e atualização em campo<br>- Segurança básica dos dados (integridade, disponibilidade e confidencialidade) |

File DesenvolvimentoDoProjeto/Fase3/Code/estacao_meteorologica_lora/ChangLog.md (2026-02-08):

# Estação Meteorológica LoRa/LoRaWAN
## Next:
- Melhorar estrutura do loop_printf quando o USB está off
- Manter histórico na flash do fcnt
- Verificar se e possivel melhorar a estabilidade da USB no modo OFF-ON
- rever funcionamento GPS, principalmente durante sleep
- Compartilhar código com esp32-c3

- wcm melhorar protocolo de envio/recebimento dos dados para o WCM
    - Aguardar OK de acordado
    - Criar Tipos de Mensagem de retorno
- Remover driver ina
- Doxigen pendentes:
    - aq_data_gps

## Build:0033 - 08/02/2026
- Doxigen:
    - hw_sleep

## Build:0032 - 08/02/2026
- Correção, faltava desligar o pll_sys no sleep

## Build:0030 - 08/02/2026
- refactory da rotina de geração do CMD do arquivo wcm.c
- Add opção de adicionar checksum ao payload
- Add janela para pressionar botão
- Doxigen:
    - wcm
    - storage

## Build:0029 - 07/02/2026
- Move conteudo das rotinas que estavam dentro do dir src/gps para aq_data_gps

## Build:0028 - 07/02/2026
- Doxigen:
    - main
    - aq_data
    - aq_data_ad
    - aq_data_bmep280
    - aq_data_lux
    - buttons_and_leds
    - code_config
    - est_config
    - loop_printf
    - menu-conf
    - wrap_watchdog
    
## Build:0027 - 07/02/2026
- gps rever printf para loop_print
- Criação do ChangeLog.md, estes dados foram para lá
- README.md com a descrição do funcionamento do programa (iniciado)
- Inicio da documentação com Doxygen

## Build:0026 - 06/02/2026
- Pequenos ajustes no MPU Temp
- Correção da primeira leitura do BME280
- BMEP280 suporta leitura tanto no BME280 como no BMP280
- Correçao nas defines de DEBUG do code_config.h

## Build:0025 - 06/02/2026
- Corrigido msg de erro do bme280
- Ajustado layout do printf:
  - de dados que serão enviados ao WCM
  - aq_data_lux
  - aq_data_ad
- Redução do consumo do BH1750 de 115uA para 3,7 uA

## Build:0024 - 01/02/2026
- USB TurnOn parametrizado
- Correção do calculo da pressão de bme280

## Build:0023 - 31/01/2026
- Correções do watchdog

## Build:0022 - 30/01/2026
- Opção de sempre ativar o menu após reset (util para detectar resets/travamentos)
- Add prints de parâmetros de compilação
- criação da rotina get_t_now() para que timer_hw->timerawl se transforme em uma variável de 64 bits
- Menu_conf: revisão de testos, limitado o modo LoRa em ABP e OTAA
- Botão Config, inverte a função do always menu
- Add Watchdog

## Build:0021 - 28/01/2026
- Adicionado no menu/sistema um parâmetro de calibração vsys_k_10000
- removido antigos src do bmp280
- rotinas i2c do luximetro revisto o blocking por timeout

## Build:0020 - 28/01/2026
- Luximetro:
    - foi reduzida a sensibilidade para 31/69 para poder suportar incidencias diretas do sol
    - foi adicionado no menu/sistema um parâmetro de calibração lux_k_10000
    - removido o antigo driver bh1750
- Correções no WCM.c para o VSys

## Build:0019 - 27/01/2026
- correção: Não salvava a versão da configuração
- Unificada as rotinas de ad: cpu temp e vsys
- corrigido a falta de? adc_gpio_init(ADC_VSYS_GPIO);

## Build:0018 - 24/01/2026
- Add aq_data_bmep280.h
Obs.: - roda só o bmep280 para testes e está com prints de debug
      - Está com o debug ativo e só em flash

## Build:0017 - 22/01/2026
- Add VSys

## Build:0016 - 17/01/2026
- Add ao Payload lux
- Add no estado original da flash, no printf e no menu_conf
- Refactore sensor tbo por cpu_temp
- Change default channel to 8

## Build:0015 - 15/01/2026
- Add no log das chamadas ao WCM o char que retornou
- Add driver do luximetro bh1750
- Add Timeout de transmissão

## Build:0014 - 14/01/2026
- Rotina de on-off do PLL USB agora leva em conta não só a USB mas também se o AD está On ou Off
- Implementada rotinas para comunicação LoRa e LoRaWANa OTAA
- Corrigido ordem do address no ABP

## Build:0013 - 14/01/2026
- Removido arquivos flash .h e .c

## Build:0012 - 14/01/2026
- Migrado da estação original as rotinas storage.h .c
- Add Funcionalidade no menu para Read Write configuração e clear all

## Build:0011unic - 13/01/2026
- Códigos default da instalação da Unicamp

## Build:0011 - 13/01/2026
- Correções no sensor CPU temp

## Build:0010 - 13/01/2026
- Criado: int aqdata_init_power_on( AqData *value)
- Transformado em parâmetro a interrupção da UART do GPS
- No menu:
  - Add CPU temp
  - Mudança de "Sleep time" para "Sampling time"

## Build:0009 - 11/01/2026
- Pequenas melhorias no menu_conf.c
- Adicionado controle de log(ativação) da USB: OFF, ON, OFF-ON
- Adicionado controle de LEDs acessos para reduzir consumo
- Obs.: wcm_send está documentado

## Build:0008- 10/01/2026
- replace printf por loop_printf para printf s que são acessados dentro do loop, para poder desativar a USB

## Build:0007- 10/01/2026
- Refactory variáveis de configuração
- Add Mode Lora
- Revisto menu

## Build:0006- 10/01/2026
- Transmitindo LoRaWAM ABP
- Baixo consumo quando em idle 

## Build:0004- 04/01/2026
- Menu parcialmente funcional para LoRaWAN ABP variaveis do lorawan
- Rotinas com sensores de:
    - Bateria
    - Pressão, temperatura (BMP280)
    - GPS
- Sleep mode
- Comunicação com WCM para envio LoRaWAN ABP

## Build:0002- 08/12/2025
- Add simple Sleep mode
- Add simple Bat    Driver
- Add simple Bmp280 Driver
- Add simple GPS    Driver
- Add print do que deve ser enviado pelo loRa
- Add Debug Mode
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

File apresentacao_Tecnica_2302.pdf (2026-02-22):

# Estação Meteorológica IoT

Contexto e Objetivos
- Âmbito Embarcatech
- Implantação distribuída no campus da Unicamp
- Projeto open source
- Requisitos técnico e não funcionais

# Estação Meteorológica IoT

Requisitos
- Sensores de temperatura, umidade, pressão e luminosidade
- Localização por GPS
- Autonomia energética
- Comunicação LoRaWAN
- IP68
- Visualização dos dados
- Escalabilidade

# Estação Meteorológica IoT


Arquitetura
- Sensoriamento
- Processamento
- Comunicação
- Backend
- Aplicação

# Estação Meteorológica IoT


Camada de Sensoriamento

- BME280
- BH1750
- GPS
- Tensão da bateria
- Temperatura interna do MCU

# Estação Meteorológica IoT

Camada de Processamento

- RP2040
- Modularização do firmware
- Simulação de sleep mode via software:
- Redução de clock
- Desligamento de PLL

# Estação Meteorológica IoT

Decisão Crítica de Engenharia – BitDogLab --> PCB dedicada


# Estação Meteorológica IoT

Camada de Comunicação


- WCM (ESP32-C3 + RFM95W)
- LoRaWAN ABP
- Lite Sleep Mode
- Payload otimizado


# Estação Meteorológica IoT


Gerenciamento Energético - Resultado da otimização

# Estação Meteorológica IoT

Backend

- Gateway RAK7289V2
- TTN
- Cloudflare
- Raspberry Pi 5
- ThingsBoard
- PostgreSQL

# Estação Meteorológica IoT


Evidências em Campo

# Estação Meteorológica IoT


TRL

- TRL 4 - componente e processos
- TRL 5 - teste de integração em laboratório
- TRL 6 - protótipo em laboratório
- TRL 7 - protótipo em campo

# Estação Meteorológica IoT

Conclusão Técnica

- Sistema validado
- Arquitetura consolidada
- Escalável
- Preparado para operação contínua
- Custo estimado de R$ 695,00

# Estação Meteorológica IoT

## OBRIGADO!

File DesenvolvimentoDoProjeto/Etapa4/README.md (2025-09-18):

# 📑 Relatório Final – Estação Meteorológica para o Agronegócio e a Agricultura Familiar

**Projeto Final - Etapa 4 (18/09/2025)**

**Autores: Carlos Martinez Perez e Ricardo Jorge Furlan**

---

## Índice
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

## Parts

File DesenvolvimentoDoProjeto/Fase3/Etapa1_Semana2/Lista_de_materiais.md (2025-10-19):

# Lista de materiais

| Item | Quant. | PCB | Descrição | Obs |
|:-:|:-: |:-:|:-:|:-:|
|  1 | 10 | |BitDogLab V7.0 | |
|  2 |  2 | X | Pico_2W | |
|  3 | 10 | |BMP280(com adaptador) | Sensor pressão temperatura |
|  4 |  2 | X |BMP280(sem adaptador) | Sensor pressão |
|  5 |  ? | |AHT10(com adaptador)  | Sensor umidade |
|  6 |  2 | X |AHT10(sem adaptador)  | Sensor umidade |
|  7 |  ? | |BH1750(com adaptador) | Sensor Luminoidade |
|  8 |  2 | X |BH1750(sem adaptador) | Sensor Luminoidade |
|  9 |  2 | X |Sensor Hall vetorial  | Direção Vento |
| 10 |  4 | X |Sensor Hall On-Off | Pluviometro/velo Vento |
| 11 |  2 | X |Módulo de carda da bateria | |
| 12 | | | Cabo JSD 4 vias | |
| 13 | 10  | | Placas de espanção | |
| 14 | ?+2 | | RTC |

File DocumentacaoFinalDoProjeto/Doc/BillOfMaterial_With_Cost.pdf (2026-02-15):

# Estação Meteorológica IoT: “Bill of Material” (com custos estimados)

## Placa Principal

Item | Quant. | Preço Unitário | Preço Total | Referência
PCB | 1 | R$ 30,00 | R$ 30,00 Estimado
Suporte bateria | 1 | R$ 3,99 | R$ 3,99 | https://www.casadarobotica.com/componentes-eletronicos/partes/suporte-para-pilhas/case-suporte-soquete-para-1-bateria-18650
Bateria | 1 | R$ 14,99 | R$ 14,99 | https://www.casadarobotica.com/fontes-conversores/fontes/outros/1x-bateria-3-7v-18650-de-litio-recarregavel-goldhill
Conector Borne KRE 2 Vias | 1 | R$ 0,60 | R$ 0,60 | https://www.piscaled.com.br/conector-borne-kre-2-vias
Diodos 1N5819 | 2 | R$ 0,22 | R$ 0,44 https://www.eletrogate.com/diodo-1n5819-10-unidades
Chaves H-H | 3 | R$ 1,20 | R$ 3,60 https://www.casadoresistor.com.br/chave-hh-liga-desliga-250v-03-terminais-180
Módulo Regulador de Tensão Step Down LM2596 | 1 | R$ 7,90 | R$ 7,90 | https://www.eletrogate.com/modulo-regulador-de-tensao-step-down-lm2596
Módulo Carregador Bateria de Lítio TP4056 Micro USB | 1 | R$ 3,70 | R$ 3,70 | https://www.makerhero.com/produto/modulo-carregador-de-bateria-de-litio-tp4056/
Capacitores 100uF x 16V | 3 | R$ 0,28 | R$ 0,84 https://www.casadoresistor.com.br/capacitor-eletrolitico-100uf-x-16v
Capacitor 100nF ceramico | 1 | R$ 0,15 | R$ 0,15 https://www.a2robotics.com.br/capacitor-disco-ceramico-100nf-x-50v-104
Raspberry Pico | 1 | R$ 37,90 | R$ 37,90 https://www.makerhero.com/produto/raspberry-pi-pico/
Barra de 40 Pinos | 2 | R$ 1,80 | R$ 3,60 https://www.makerhero.com/produto/barra-de-pinos-1x40-180-graus/
Conector de 20Pinos | 3 | R$ 1,20 | R$ 3,60 | https://www.casadarobotica.com/componentes-eletronicos/partes-eletronicas/conectores/barra-de-pinos-pin-head-femea-pci-1x20-passo-2-54mm-180
Resistores 1 k x 1/4W 5% | 3 | R$ 0,08 | R$ 0,24 https://www.casadoresistor.com.br/resistor-filme-carbono-carvao-cr25-1-4w-5-1k
Resistores 100k x 1/4W 1% | 2 | R$ 0,15 | R$ 0,30 https://www.casadoresistor.com.br/resistor-filme-metalico-metal-film-mf25-1-4w-1-100k
Led Vermelho 3mm | 1 | R$ 0,18 | R$ 0,18 https://www.casadoresistor.com.br/led-3mm-200mcd-30-vermelho-encapsulamento
Led Verde | 1 | R$ 0,18 | R$ 0,18 https://www.casadoresistor.com.br/led-3mm-verde-0301doyg
Led Azul | 1 | R$ 0,32 | R$ 0,32 https://www.casadoresistor.com.br/led-3mm-250-mcd-difuso-azul
Conectores JSH | 4 | R$ 0,40 | R$ 1,60 https://www.smartkits.com.br/conector-jst-xh2-54mm-macho-4-vias
Chaves tactil | 2 | R$ 0,28 | R$ 0,56 | https://www.casadoresistor.com.br/chave-tactil-kfc-a06-6x6x5-4t-180
Total | | | R$ 114,69

## WCM

Item | Quant. | Preço Unitário | Preço Total | Referência
PCB | 1 | R$ 30,00 | R$ 30,00 Estimado
XIAO-ESP32-C3 | 1 | R$ 70,00 | R$ 70,00 Estimado, referências abaixo
RFM95-W | 1 | R$ 61,10 | R$ 61,10 https://www.piscaled.com.br/modulo-lora-rfm95w-915mhz
Capacitores SMD 100uF | 2 | R$ 0,59 | R$ 1,18 https://www.casadoresistor.com.br/capacitor-eletrolitico-smd-100uf-16v-diametro-7mm-altura-5mm
Resistor SMD | 1 | R$ 0,08 | R$ 0,08 https://www.casadoresistor.com.br/resistor-smd-0603-1-4k75
Barra de 6 pinos | 1 | R$ 1,80 | R$ 1,80 https://www.makerhero.com/produto/barra-de-pinos-1x40-180-graus/
Total | | | R$ 164,16
Preço Estimado do XIAO-ESP32-C3 | Referência
US$ 4,90 R$ 69,90 https://www.robocore.net/seeed-studio/seeed-studio-xiao-esp32c6 | https://www.seeedstudio.com/Seeed-XIAO-ESP32C3-p-5431.html

## Sensores

Item | Quant. | Preço Unitário | Preço Total | Referência
bme280 | 1 | R$ 32,87 | R$ 32,87 | https://www.usinainfo.com.br/sensor-de-pressao/sensor-de-pressao-umidade-e-temperatura-bme280-de-alta-precisao-33v-4682.html
bh1750 | 1 | R$ 12,00 | R$ 12,00 https://www.piscaled.com.br/modulo-sensor-de-luminosidade-bh1750-gy-302-lux
Módulo GPS GY-NEO6MV2 Com Antena | 1 | R$ 37,90 | R$ 37,90 | https://www.makerhero.com/produto/modulo-gps-gy-neo6mv2-com-antena/
Conectores JSH | 3 | R$ 0,40 | R$ 1,20 https://www.smartkits.com.br/conector-jst-xh2-54mm-macho-4-vias
Total | | | R$ 83,97

## Instalação

Item | Quant. | Preço Unitário | Preço Total | Referência
Painel Solar | 1 | R$ 78,99 | R$ 78,99 | https://www.mercadolivre.com.br/painel-placa-solar-fotovoltaica-10w-inmetro/up/MLBU727939907
Caixa | 1 | R$ 78,90 | R$ 78,90 | https://www.mercadolivre.com.br/up/MLBU780593118
Cabos JSH | 3 | R$ 3,00 | R$ 9,00
Suporte Caixa Painel solar | 0,22 | R$ 63,50 | R$ 13,97 | https://www.filamentos3dbrasil.com.br/produtos/filamento-abs-premium-natural/
Parafusos Suporte | 2 | R$ 2,00 | R$ 4,00 Estimado
Solda | 1 | R$ 15,99 | R$ 15,99 | https://www.casadarobotica.com/prototipagem-ferramentas/prototipagem/soldas/solda-tubinho-fio-ra-63x37-sn-x-pb-1-0mm-22g-cobix
Parafusos PCB | 4 | R$ 0,75 | R$ 3,00 https://www.casadoresistor.com.br/espacador-nylon-femea-macho-m3x12mm-branco
Antena | 1 | R$ 125,00 | R$ 125,00 | https://www.mercadolivre.com.br/antena-para-rf-lora-868mhz--915mhz-1m-6dbi--cabo-ipex/up/MLBU1972521930
Total | | | R$ 328,85

## Custo Total

Item | Quant. | Preço Unitário | Preço Total | Referência
Placa Principal | 1 | R$ 114,69 | R$ 114,69
WCM | 1 | R$ 164,16 | R$ 164,16
Sensores | 1 | R$ 83,97 | R$ 83,97
Itens de Instalação | 1 | R$ 328,85 | R$ 328,85
Total | | | R$ 691,67

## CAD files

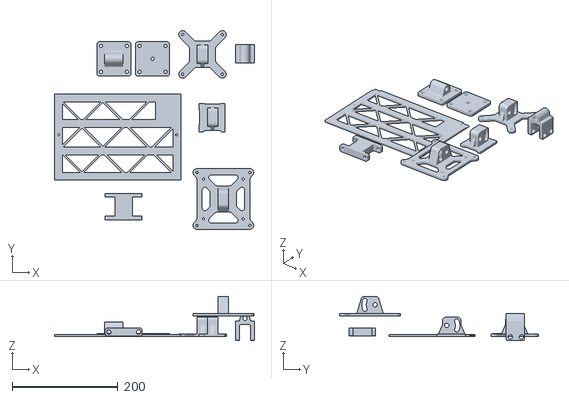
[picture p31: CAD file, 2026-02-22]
DocumentacaoFinalDoProjeto/Hardware/Pecas3D/haste fixação painel solar.stl
378.4 x 376.0 x 83.6

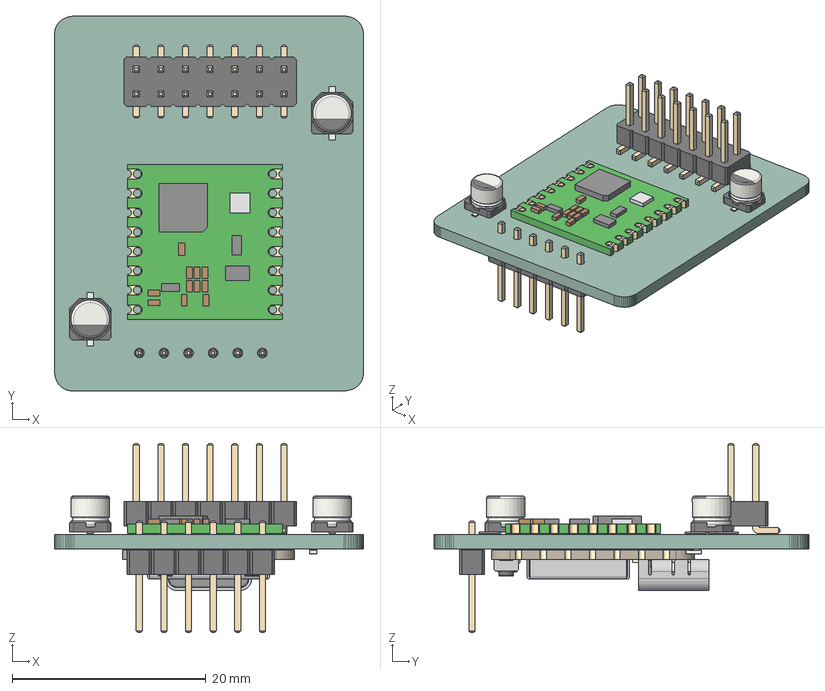
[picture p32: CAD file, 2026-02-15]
DocumentacaoFinalDoProjeto/Hardware/WCM/KiCad/WCM_v1D.step
31.9 x 38.7 x 19.5 mm
CP_Elec_4x3.9 x 2
PinHeader_2x07_P2.54mm_Vertical_SMD
RFM95W-868S2--3DModel-STEP-56544
BOSS-EXTRUDE14_8_
BOSS-EXTRUDE7_4_
BOSS-EXTRUDE7_3_
BOSS-EXTRUDE14_4_
BOSS-EXTRUDE14_2_
BOSS-EXTRUDE14_11_
BOSS-EXTRUDE7_7_
BOSS-EXTRUDE14_9_
BOSS-EXTRUDE14_3_
BOSS-EXTRUDE14_7_
MIRROR2
BOSS-EXTRUDE14_5_
BOSS-EXTRUDE14_12_
BOSS-EXTRUDE7_8_
BOSS-EXTRUDE7_1_
BOSS-EXTRUDE14_10_
BOSS-EXTRUDE7_9_
BOSS-EXTRUDE14_6_
BOSS-EXTRUDE14_1_
BOSS-EXTRUDE7_6_
BOSS-EXTRUDE7_2_
CUT-EXTRUDE5
BOSS-EXTRUDE7_5_
U.FL Connector v1
Button (1) x 2
Shield
PinHeader_1x06_P2.54mm_Vertical
R_0603_1608Metric
WCM_v1D_PCB

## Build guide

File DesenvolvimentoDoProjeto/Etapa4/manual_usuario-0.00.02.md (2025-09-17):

# 📖 Manual do Usuário – Estação Meteorológica para o Agronegócio e a Agricultura Familiar

Capa

Autores: **Carlos Martinez Perez** e **Ricardo Jorge Furlan**

Versão: 0.00.02 de 12/09/2025

## Índice

- [📖 Manual do Usuário – Estação Meteorológica para o Agronegócio e a Agricultura Familiar](#-manual-do-usuário--estação-meteorológica-para-o-agronegócio-e-a-agricultura-familiar)
  - [Índice](#índice)
  - [0. O que você recebeu](#0-o-que-você-recebeu)
  - [1. Instalação dos Módulos](#1-instalação-dos-módulos)
  - [2. Configuração da Estação](#2-configuração-da-estação)
    - [Tela 1 – Configuração Geral da Estação](#tela-1--configuração-geral-da-estação)
    - [2.1 Parâmetros da Estação](#21-parâmetros-da-estação)
    - [2.2 Parâmetros da Comunicação](#22-parâmetros-da-comunicação)
    - [2.3 Definição dos Intervalos e Clock](#23-definição-dos-intervalos-e-clock)
    - [2.4 Sensores I2C Ativos](#24-sensores-i2c-ativos)
    - [2.5 Sensores Digitais Ativos](#25-sensores-digitais-ativos)
    - [2.6 Sensores Analógicos Ativos](#26-sensores-analógicos-ativos)
    - [2.7 Opções de Sistema](#27-opções-de-sistema)
    - [Tela 2 – Ajustes de Data e Hora](#tela-2--ajustes-de-data-e-hora)
    - [2.8 Ajuste de Data e Hora](#28-ajuste-de-data-e-hora)
  - [3. Funcionamento da Estação](#3-funcionamento-da-estação)
    - [3.1 Indicações do LED RGB](#31-indicações-do-led-rgb)
    - [3.2 Indicações do Display da Placa Mãe](#32-indicações-do-display-da-placa-mãe)
    - [3.3 Indicações do Monitor Serial](#33-indicações-do-monitor-serial)
  - [4. Instalação do Servidor](#4-instalação-do-servidor)
  - [5. Uso do Grafana](#5-uso-do-grafana)
    - [5.1 Painéis do Dashboard](#51-painéis-do-dashboard)
      - [Escolha da estação](#escolha-da-estação)
      - [Indicadores em tempo real (Gauges)](#indicadores-em-tempo-real-gauges)
      - [Temperaturas mínimas e máximas do dia](#temperaturas-mínimas-e-máximas-do-dia)
      - [Médias semanais](#médias-semanais)
      - [Mapa das estações](#mapa-das-estações)
      - [Gráfico de históricos](#gráfico-de-históricos)
    - [5.2 Como Acessar o Dashboard](#52-como-acessar-o-dashboard)
  - [6. Especificações Técnicas da Estação](#6-especificações-técnicas-da-estação)
    - [Principais características](#principais-características)
    - [Características dos sensores homologados](#características-dos-sensores-homologados)
    - [Características dos sensores em homologação](#características-dos-sensores-em-homologação)
    - [Especificação do servidor](#especificação-do-servidor)

---

## 0. O que você recebeu
- Uma caixa suporte para os principais sensores;
- Uma placa BitDogLag;
- Sensores:
  - BMP280, sensor de pressão e temperatura;
  - AHT10, sensor de umidade e temperatura;
  - BH1759, sensor de luminosidade;
- RTC DS3131;
- Placa Expansora I2C;
- 4 Cabos JST XH de 4 pinos;
- 1 Cabo JST XH de 4 pinos para RTC;
- Cabo USB;
- Manual de instruções.

---

## 1. Instalação dos Módulos

Para colocar a estação meteorológica para o Agronegócio e a Agricultura Familiar em funcionamento, instale os módulos segundo os seguintes passos:
   - Conecte os módulos I2C na placa expansora I2C com os cabos JST XH de 4 pinos fornecidos;
   - Conecte a placa expansora o RTC com o cabo JST XH de 4 pinos para RTC;
   Obs.: **Cuidado** ao conectar na placa expansora pois ela possui um conector que é exclusivo para fazer a conexão com a BitDogLab;
   - Conecte a placa expansora com o cabo JST XH de 4 pinos, ao conector I2C-0 da BitDogLab;
   - Para os módulos que não são I2C siga as instruções contidas nos respectivos manuais;
   - Conecte A BitDogLab a uma fonte USB de 5 Volts para o funcionamento normal.
   Obs.: é Fornecido separadamente vários modelos de fontes de 5 Volts USB, cada uma com um tipo de fonte energética como:Energia solar, eólica, rede elétrica etc, consulte;
   - Obs.: Para a configuração inicial da estação será necessário conectar a BitDogLab em um terminal serial USB.

---

## 2. Configuração da Estação

- A estação meteorológica inicia automaticamente seu funcionamento assim que for energizada.
- Case se deseje ajustar os parâmetros da estação, configuração, que será feito via terminal serial USB, basta pressionar o botão A da BitDogLab antes de energizá-la, e mantenha pressionado até o LED azul ficar aceso após o display acender, ai pode soltá-lo e conectar o terminal serial
- A configuração é realizada através de **menus textuais** exibidos no monitor serial.
  - O primeiro menu permite ajustar parâmetros gerais, de comunicação, os intervalos de operação e ativar e desativar os sensores disponíveis, conforme será descrito a seguir.
  - O segundo menu permite que se ajuste o Relógio, Obs.: caso não se utiliza RTC sempre ao energizar a estação se entrará no menu de ajuste do relógio.

### Tela 1 – Configuração Geral da Estação

A imagem abaixo mostra a tela de configuração geral da estação:

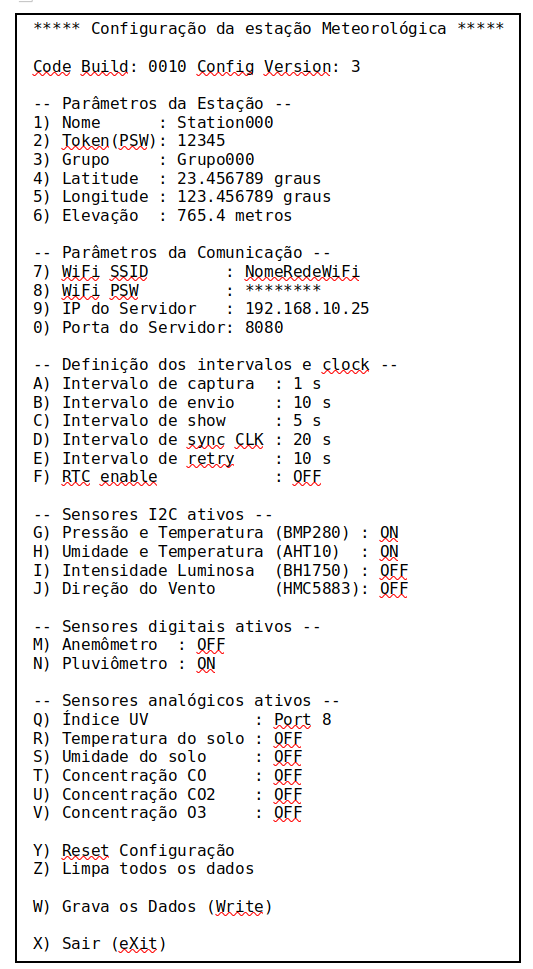
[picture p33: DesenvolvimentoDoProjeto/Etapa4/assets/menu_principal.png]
Menu de Configuração Geral
  

---

### 2.1 Parâmetros da Estação

Escolha o número do menu, atualize com o valor desejado e pressione Enter para alterar.

- **Nome** – Identificação da estação na rede.
- **Token (PSW)** – Senha utilizada para autenticação junto ao servidor.
- **Grupo** – Permite organizar várias estações sob um mesmo identificador.
- **Latitude / Longitude / Elevação** – Definem a posição geográfica da estação.

---

### 2.2 Parâmetros da Comunicação

Escolha o número do menu, atualize com o valor desejado e pressione Enter para alterar.

- **WiFi SSID** – Nome da rede Wi-Fi que será utilizada.
- **WiFi PSW** – Senha da rede Wi-Fi.
- **IP do Servidor** – Endereço IP do servidor central.
- **Porta do Servidor** – Porta TCP usada para envio dos dados.

---

### 2.3 Definição dos Intervalos e Clock

Pressione a letra do menu para escolher os valores desejados.

- **A) Intervalo de captura** – Tempo entre cada registro da leitura dos sensores. Escolha um dos intervalos pré definidos: 1 s, 2 s, 5 s, 10 s, 20 s, 1 min, 2 min, 5 min, 10 min, 20 min ou 1 hora.
- **B) Intervalo de envio** – Tempo entre transmissões de dados para o servidor. Escolha um dos intervalos pré definidos: 10 s, 20 s, 1 min, 2 min, 5 min, 10 min, 20 min, 1 hora, 2 horas, 6 horas, 12 horas, 1 dia ou Desativado.
- **C) Intervalo de show** – Frequência de envio das informações para o terminal serial. Escolha um dos intervalos pré definidos: 1 s, 2 s, 5 s, 10 s, 20 s, 1 min, 2 min, 5 min, 10 min, 20 min, 1 hora, 2 horas, 6 horas, 12 horas, 1 dia ou Desativado.
- **D) Intervalo de sync CLK** – Período para sincronização do relógio. Escolha um dos intervalos pré definidos: 1 s, 2 s, 5 s, 10 s, 20 s, 1 min, 2 min, 5 min, 10 min, 20 min, 1 hora, 2 horas, 6 horas, 12 horas, 1 dia ou Desativado.
- **E) Intervalo de retry** – Tempo de espera entre tentativas de reconexão com o servidor. Escolha um dos intervalos pré definidos: 1 s, 2 s, 5 s, 10 s, 20 s, 1 min, 2 min, 5 min, 10 min, 20 min, 1 hora, 2 horas, 6 horas, 12 horas ou 1 dia.
- **F) CLK enable** – Ativa ou desativa o uso do módulo RTC (Real Time Clock).

---

### 2.4 Sensores I2C Ativos

Pressione a letra correspondente para ativar ou desativar os sensores I2C.

- **G) Pressão e Temperatura (BMP280)** – Mede pressão atmosférica e temperatura.
- **H) Umidade e Temperatura (AHT10)** – Mede umidade relativa do ar e temperatura.
- **I) Intensidade Luminosa (BH1750)** – Mede luminosidade ambiente.
- **J) Direção do Vento (HMCS5883)** – Magnetômetro que indica direção do vento.

---

### 2.5 Sensores Digitais Ativos

Pressione a letra correspondente para ativar ou desativar os sensores digitais.

- **M) Anemômetro** – Mede a velocidade do vento.
- **N) Pluviômetro** – Mede volume de chuva acumulado.

---

### 2.6 Sensores Analógicos Ativos

Pressione a letra correspondente do sensor para escolher a porta analógica em que ele está conectado. A porta 0 é a entrada analógica da BitDogLab. As portas de 1 a 8 são da placa de conversão analógico/digital AD5592 (item opcional).

- **O) Índice UV** – Mede intensidade de radiação ultravioleta.
- **P) Temperatura do solo** – Mede a temperatura do solo.
- **S) Umidade do solo** – Mede a umidade do solo.
- **T) Concentração CO** – Mede concentração de monóxido de carbono.
- **U) Concentração CO₂** – Mede concentração de dióxido de carbono.
- **V) Concentração O₃** – Mede concentração de ozônio.

---

### 2.7 Opções de Sistema

Pressione a letra correspondente para realizar a operação desejada.

- **Y) Reset Configuração** – Restaura os parâmetros de fábrica na tela.
- **Z) Limpa todos os dados** – Apaga todos os registros locais, **é necessário ser executado na primeira inicialização da estação**.
- **W) Grava os Dados (Write)** – Salva as alterações de configuração realizadas.
- **X) Sair (Exit)** – Encerra o menu de configuração.

---

### Tela 2 – Ajustes de Data e Hora

A imagem abaixo mostra a tela de ajuste de Data e Hora:

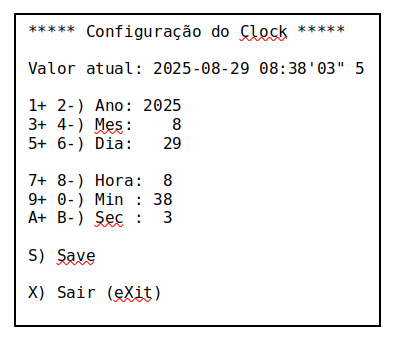
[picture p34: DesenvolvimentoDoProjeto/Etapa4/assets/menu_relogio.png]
Menu de Ajuste de Data e Hora


### 2.8 Ajuste de Data e Hora

Pressione os números ou letras correspondentes para incrementar ou decrementar as variáveis de data e hora e para salvar ou sair.

- **1+ / 2-** – Incrementa ou decrementa o ano.
- **3+ / 4-** – Incrementa ou decrementa o mês.
- **5+ / 6-** – Incrementa ou decrementa o dia.
- **7+ / 8-** – Incrementa ou decrementa a hora.
- **9+ / 0-** – Incrementa ou decrementa os minutos.
- **A+ / B-** – Incrementa ou decrementa os segundos.
- **S) Save** – Grava as alterações feitas.
- **X) Sair (Exit)** – Vai para a coleta de dados meteorológicos.

Ao sair com a tecla X, é mostrada a mensagem **** Fim da Configuração do Clock **** e a estação entra em operação.

---

## 3. Funcionamento da Estação

Após a energização do sistema o LED RGB pisca rapidamente em sequências as cores vermelho, verde e azul, na sequência o Display pisca e mostra a mensagem:

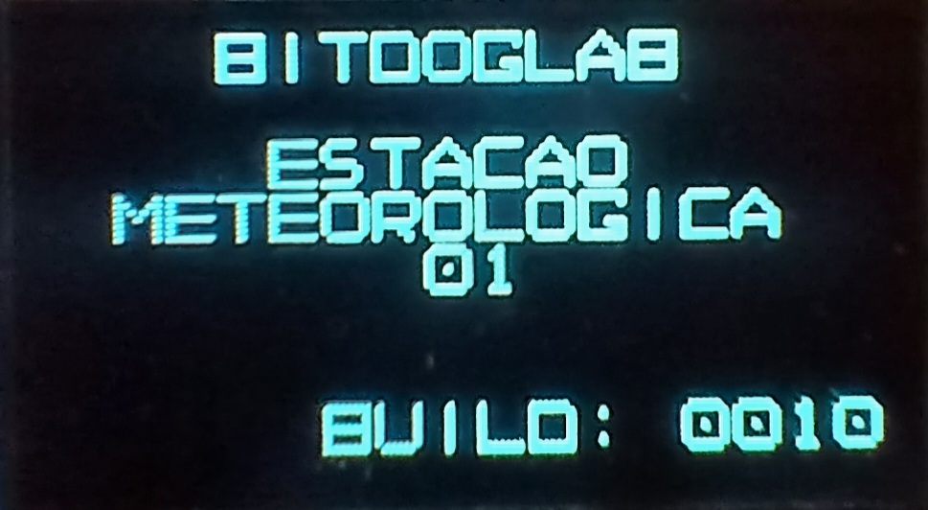
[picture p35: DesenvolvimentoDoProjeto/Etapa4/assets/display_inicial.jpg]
Indicação Inicial do Display


Se o botão A for pressionado quando o display ainda está piscando e continuar assim até o LED azul ficar acesso, a estação ativa o modo de configuração, conforme já mencionado acima. Após a configuração e/ajuste do relógio a operação da estação meteorológica começa. 

### 3.1 Indicações do LED RGB

Durante a operação, a cor do LED indica:
- Vermelho ==> Não há conexão com o roteado;
- Verde ==> Conexão WiFi estabelecida com o roteador, roteador, e não houve falhas de acesso ao servidor;
- Amarelo ==> Conexão WiFi estabelecida com o roteador, mas a última tentativa de conexão com o servidor falhou
- Piscadas Azuis ==> Dados da estação estão sendo salvos na memória não volátil

---

### 3.2 Indicações do Display da Placa Mãe

Durante o funcionamento o display é atualizado a cada nova aquisição de dados. As 3 primeiras linhas do display são fixas e indicam:
- "DATA" - A data atual (UTC)
- "TIME" - A hora atual (UTC)
- "CYCLE" - número de aquisições feitas desde quando os dados foram limpos da memória

As 4 últimas linhas trazem informações da estação e das leituras efetuadas e com o joystick é possivel navegar entre elas:
- Build : Build do software;
- linha em branco;
- nome_da_estação;
- token;
- grupo;
- lat : latitude;
- lon : longitude;
- elev: elevação;
- Press: Pressão atmosférica;
- Tempp: Temperatura reportada pelo sensor BMP280;
- Humid: Umidade relativa do ar;
- Temph: Temperatura reportada pelo sensor AHT10;
- Lumin: Luminosidade;
- WindD: Direção do vento;
- WindS: Velocidade do vento;
- Rain : Intensidade da precipitação;
- CO   : Concentração de CO;
- CO2  : Concentração de CO2;
- O3   : Concentração de O3;
- SoilH: Umidade relativa do solo;
- SoilT: Temperatura do solo;
- Uv In: Índice UV.

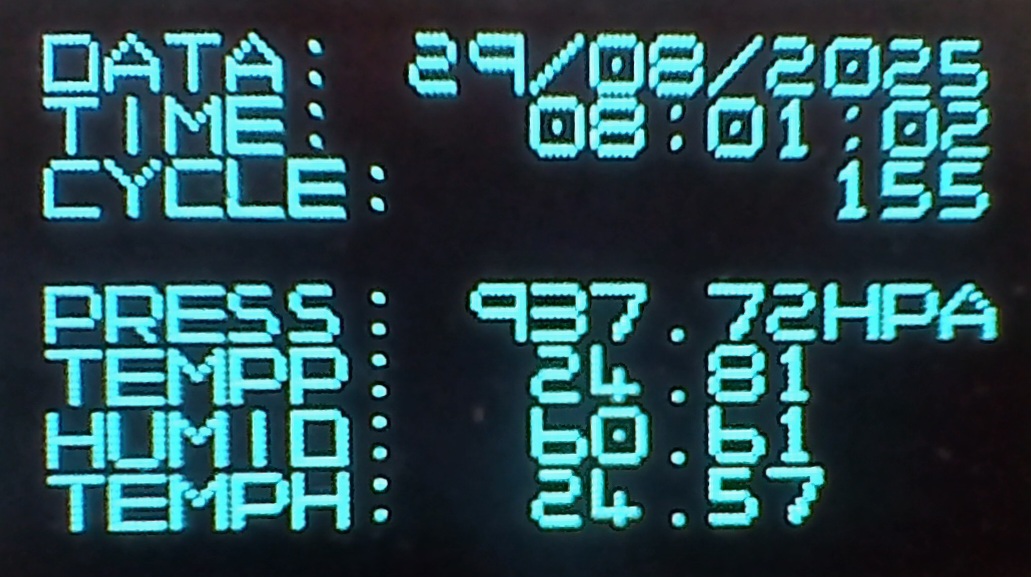
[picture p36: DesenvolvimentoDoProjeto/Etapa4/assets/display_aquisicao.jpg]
Display quando a estação está em aquisição


---

### 3.3 Indicações do Monitor Serial

Durante a operação da estação, o monitor serial mostra:
- Aquisições efetuadas periodicamente
- Dados enviados para o servidor, bem como o resultado do envio.
- Requisições de atualização do relógio, bem como o resultado da requisição.

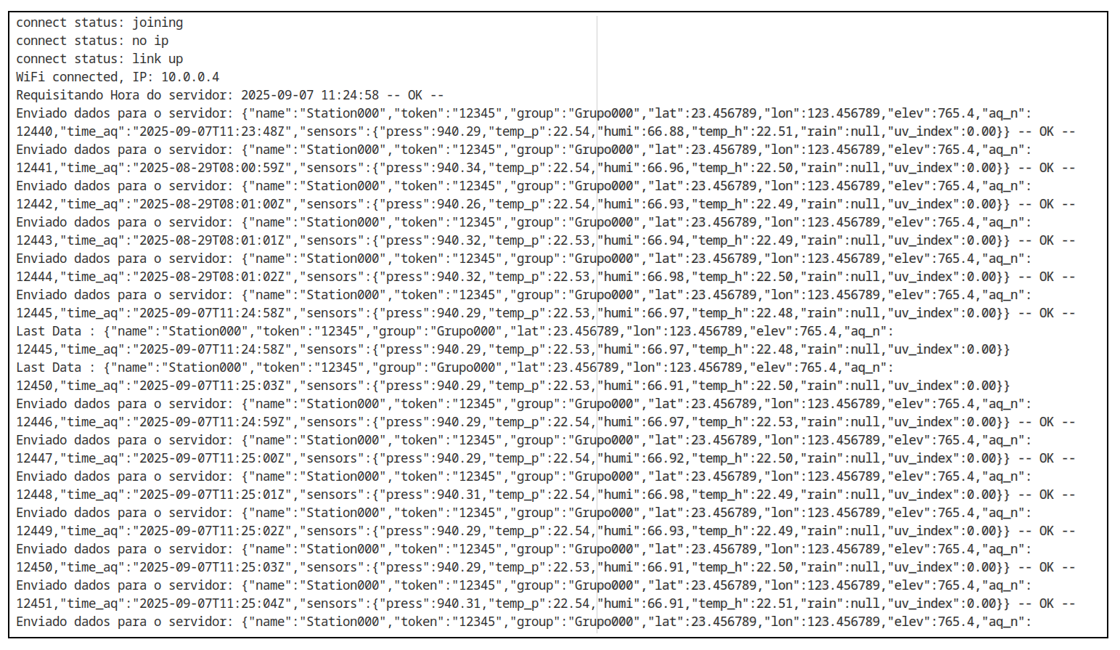
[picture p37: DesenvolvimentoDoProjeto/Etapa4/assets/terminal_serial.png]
Terminal serial


---

## 4. Instalação do Servidor

Para que os dados da estação possam ser armazenados remotamente e acessos pela internet é necessário instalar o servidor.
Esta versão básica de servidor é de simples instalação e inclui todos os componentes necessários e roda em contêiner.
Para instalar e levantar o servidor faça:
- download dos arquivos do servidor em https://github.com/EmbarcaTech-2025/projeto-final-carlos_ricardo/tree/main/Etapa4/Servidor em um diretório *servidor*
- no terminal entre no diretório *servidor*
- rode:
  - $ docker-compose build
- e depois rode:
  - $ docker-compose up 
  
Isso colocará no ar três contêiner docker com as funcionalidades necessárias:
- API
- Banco de dados
- Grafana
  Obs.: É possível acompanhar a chegada das requisições da estação monitorando o terminal a onde foi executado o comando:
  - $ docker-compose up
  Exemplo abaixo:

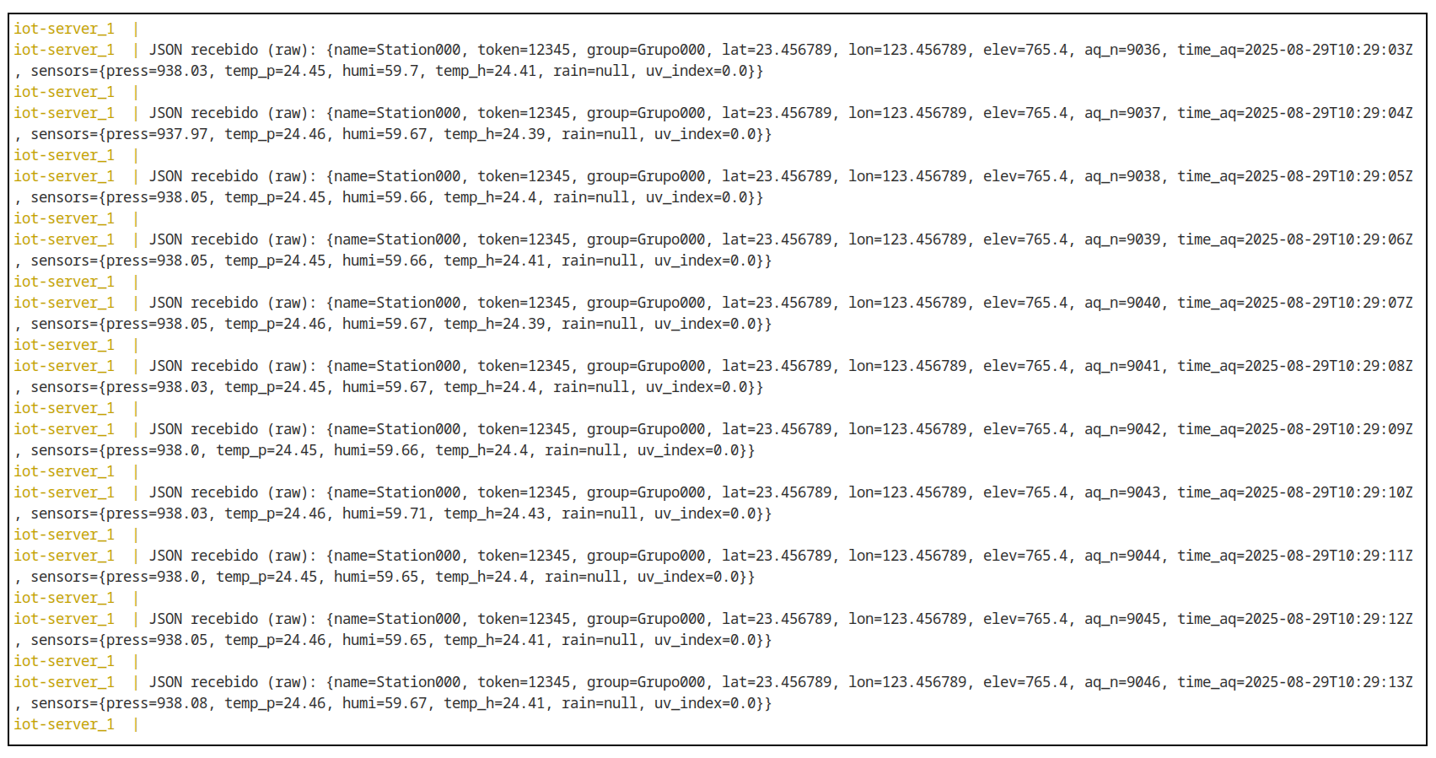
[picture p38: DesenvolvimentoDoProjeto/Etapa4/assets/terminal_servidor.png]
Servidor


---

## 5. Uso do Grafana

O projeto da estação meteorológica utiliza o Grafana como plataforma open source para monitoramento e visualização de dados em tempo real. O dashboard criado para a visualização aparece abaixo.  
Exemplo 1:
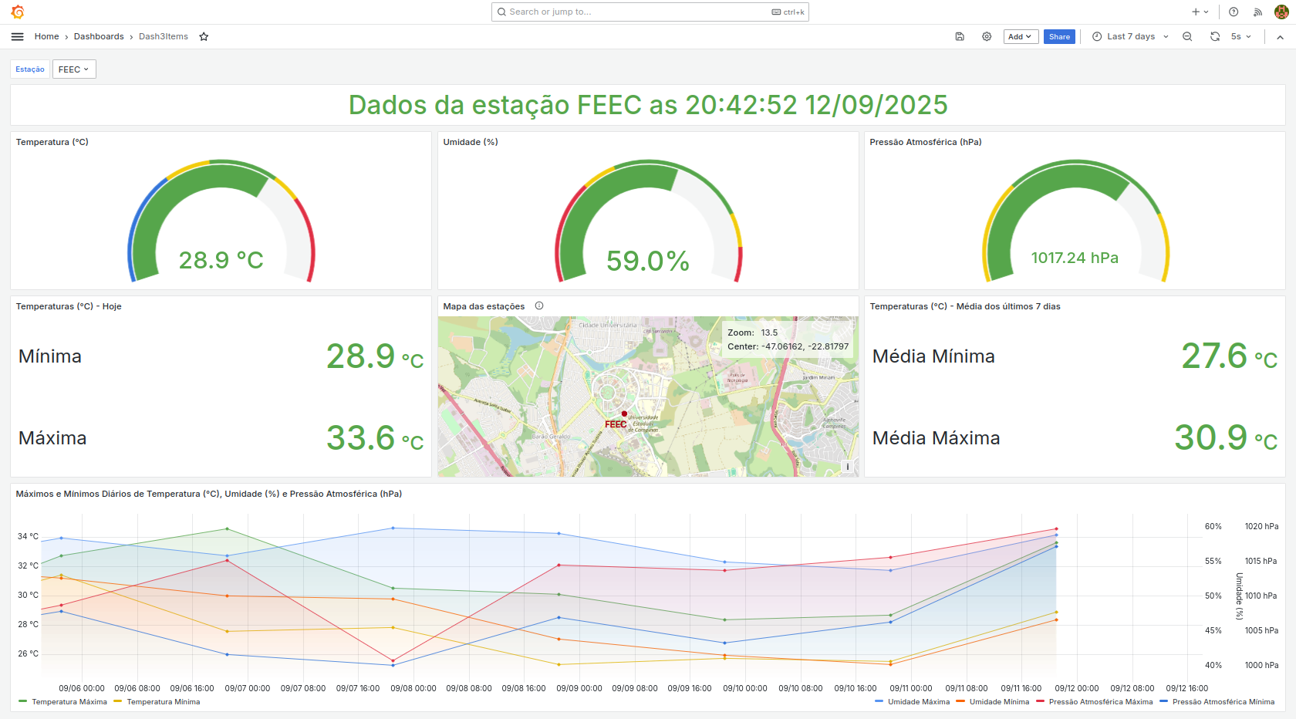
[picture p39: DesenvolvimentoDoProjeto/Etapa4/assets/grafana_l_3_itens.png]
Dashboard-1

Exemplo 2:
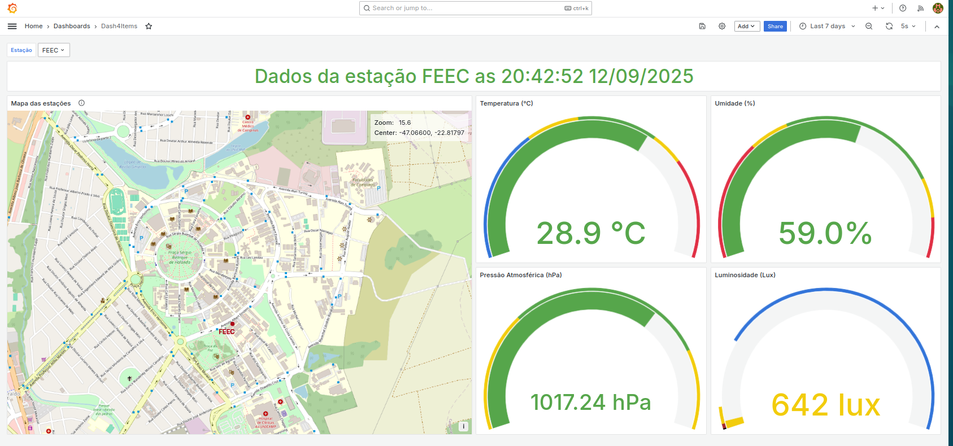
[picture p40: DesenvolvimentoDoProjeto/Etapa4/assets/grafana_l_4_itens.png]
Dashboard-2


### 5.1 Painéis do Dashboard

**Descrição do exemplo1**

#### Escolha da estação
Selecione a estação que deseja visualizar no painel Device, no canto superior esquerdo do dashboard. Um menu suspenso mostra as estações que tiveram dados colhidos. O dashboard é atualizado instantaneamente.  
#### Indicadores em tempo real (Gauges)
Os três painéis superiores exibem as últimas informações colhidas para temperatura, umidade relativa e pressão atmosférica no local da estação.  
#### Temperaturas mínimas e máximas do dia
O painel de central à esquerda exibe as temperaturas mínima e máxima do dia.  
#### Médias semanais
O painel direito central apresenta as médias semanais, mostrando os valores médios das temperaturas mínima e máxima registradas nos últimos 7 dias da a estação selecionada.  
#### Mapa das estações
No centro do dashboard, o mapa exibe a localização geográfica da estação selecionada.  
#### Gráfico de históricos
O gráfico na parte inferior do dashboard apresenta as séries temporais das medições da estação selecionada, permitindo acompanhar a evolução das temperaturas máxima e mínima, das umidades relativas máxima e mínima e das pressões atmosféricas máxima e mínima dds dados dos últimos 7 dias. A figura abaixo mostra um exemplo do gráfico:

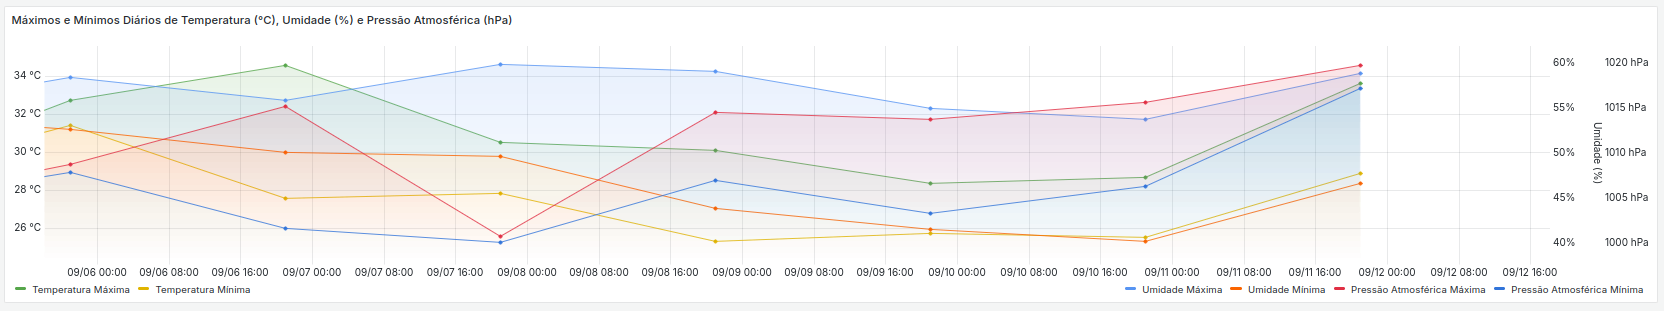
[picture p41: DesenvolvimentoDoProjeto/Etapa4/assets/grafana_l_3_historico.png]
Dashboard


---
### 5.2 Como Acessar o Dashboard

Para ter acesso ao dashboard, siga estes passos:

1. **Abrir o navegador**: a partir de qualquer navegador web, acesse o endereço [http://localhost:3000/login](http://localhost:3000/login). Esse é o **gateway de acesso** ao Grafana, desde que o servidor esteja em execução.

2. **Login no Grafana**: insira o nome de usuário e senha cadastrados para acessar o ambiente do Grafana.

3. **Configurar a fonte de dados (Data Source)**:

   * No menu lateral, selecione **Connections → Data sources**.
   * Clique em **Add data source** e escolha a opção **PostgreSQL**.

4. **Conectar ao banco de dados**: na tela de configuração do PostgreSQL, informe os seguintes dados:

   * **Nome do banco**: o nome definido na instalação/configuração do banco de dados.
   * **Usuário e senha**: credenciais de acesso ao banco.
   * **TLS/SSL**: selecionar a opção **Disabled**.

5. **Salvar e testar**: clique em **Save & test** para verificar se a conexão foi estabelecida corretamente.

6. **Acessar o dashboard**: depois que a conexão com o banco de dados for validada, é possível visualizar os dashboards já configurados. Para isso:

   * No menu lateral do Grafana, clique em **Dashboards**.
   * No canto superior direito da tela, selecione a opção **New → Import**.
   * Escolha o dashboard desejado pelo **nome** na lista disponível ou insira o ID de um dashboard previamente exportado.
   * Clique em **Load** e confirme para abrir o painel e navegar.

---

## 6. Especificações Técnicas da Estação

### Principais características
  
- Placa mãe: BitDogLab V6.3.
- Software Build: 0012 ou superior.
- Consumo total médio típico:
	+ WiFi desconectado: 46 mA
	+ WiFi conectado: 70 mA
	+ Transmitindo dados: 97 mA  

  Obs.: Sem sensores AD de alto consumo.

- Duração estimada da bateria backup presente na BitDogLab: 20 horas
	+ Para Bateria 18650 de 2000 mA hora  

- Modo de comunicação:
	+ WiFi Conexão constante com o roteador, com reconexão automática.
- Vida estimada da memória Flash:
  -  **> 12 anos** Supondo uma aquisição salva por segundo.
  -  **> 120 anos** Supondo uma aquisição salva a cada 10 segundos.
  
  Ref.: minimo 100K escritas por setor(W25Q16JV).
- Mecanismo de Integridade:
	+ WatchDog com timeout de 45 segundos.

### Características dos sensores homologados

| Sensor | Grandeza | Unidade | Range | Precisão | Faixa de Operação |Consumo | Outros |
| --- | --- | --- | --- | --- | --- | --- | --- |
| BMP280 | Pressão | hPa| 300-1100hPa|+-1hPa (de 0 a +40C) | -40 - +85 C | 1120 uA peak | I2C ad=0x76 |
| BMP280 | Temperatura | Celsius | 0 - 65 C| +-1.0 C | |
| AHT10 | Umidade | Relativa | 0 - 100% | +-3% | -40 - 100C| 23 ua | I2C ad=0x38 |
| AHT10 | Temperatura | Celsius | -40 - 80C | +- 0,4 C |
| BH1750 | Luminosidade | lx|0-65535 * | 1.2x  | -40 - +85C | 190 uA | I2C ad=0x23 0x5C |

### Características dos sensores em homologação
Obs.1: Para sua inclusão na estação pode ser necessitar de atualização de firmware e/ou hardware
Obs.2: Como os sensores estão em homologação a tabela abaixo é apenas um indicativo, com valores ausentes em virtude da homologação.

| Sensor | Grandeza | Unidade | Range | Precisão | Faixa de Operação |Consumo | Outros |
| --- | --- | --- | --- | --- | --- | --- | --- |
| HMC5883 | Direção do Vento |Graus| 0-359 graus| 1 grau |-30 - +85C | 100 uA| I2C ad=0x1E |
| --- | --- | --- | --- | --- | --- |
|  | Quantidade de chuva | mm  | --- | --- | --- | --- |
|  | Velocidade do Vento | m/s | --- | --- | --- | --- |
| --- | --- | --- | --- | --- | --- |
| | Índice UV | índice | 0 - 12 | --- | --- | --- | Portas AD de 0 a 8 |
| | Umidade do Solo | % | --- | --- | --- | --- | Portas AD de 0 a 8 |
| | Temperatura do Solo | Celsius | --- | --- | --- | --- | Portas AD de 0 a 8 |
| | Concentração de CO | ppm | --- | --- | --- | --- | Portas AD de 0 a 8 |
| | Concentração de CO2 | ppm | --- | --- | --- | --- | Portas AD de 0 a 8 |
| | Concentração de O3 | ppm | --- | --- | --- | --- | Portas AD de 0 a 8 |

### Especificação do servidor

- Suporte a Docker contêineres 64 bits;
- IP fixo;
- Porta 8080 liberada para acesso externo;
- 1G de memoria Ram disponível para a aplicação;
- 16G de HD para a Aplicação;
- Obs.: as configurações podem ser maiores dependendo do número de estações conectadas, taxa de dados adquiridas e número de dashboards ativos.

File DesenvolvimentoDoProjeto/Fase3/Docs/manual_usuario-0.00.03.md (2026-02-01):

# 📖 Manual do Usuário – Estação Meteorológica IoT com LoRaWAN

Capa

Autores: **Antonio**, **Carlos** e **Ricardo**

Versão: 0.00.03 de 25/01/2026

## Índice

- [📖 Manual do Usuário – Estação Meteorológica IoT com LoRaWAN](#-manual-do-usuário--estação-meteorológica-iot-com-lorawan)
  - [Índice](#índice)
  - [1. Apresentação do Sistema](#1-apresentação-do-sistema)
  - [2. O que você recebeu](#2-o-que-você-recebeu)
  - [3. Visão Geral do Funcionamento](#3-visão-geral-do-funcionamento)
  - [4. Instalação Física da Estação](#4-instalação-física-da-estação)
  - [5. Configuração da Estação](#5-configuração-da-estação)
    - [5.1 Parâmetros LoRaWAN](#51-parâmetros-lorawan)
    - [5.2 Definição dos Intervalos de Coleta](#52-definição-dos-intervalos-de-coleta)
    - [5.3 Seleção dos Sensores Ativos](#53-seleção-dos-sensores-ativos)
    - [5.4 Seleção dos Modos de Log](#54-seleção-dos-modos-de-log-afetam-o-consumo-da-estação)
    - [5.5 Opções Adicionais do Menu](#55-opções-adicionais-do-menu)
  - [6. Funcionamento da Estação](#6-funcionamento-da-estação)
    - [6.1 Indicações dos LEDs da Placa](#61-indicações-dos-leds-da-placa)
    - [6.2 Indicações do Monitor Serial](#62-indicações-do-monitor-serial)
  - [7. Configuração do The Things Network (TTN) Gateway](#7-configuração-do-the-things-network-ttn-gateway)
  - [8. Configuração do TheThingsBoard](#8-configuração-do-thethingsboard)
  - [9. Especificações Técnicas da Estação](#9-especificações-técnicas-da-estação)
    - [Principais características](#principais-características)
    - [Características dos sensores homologados](#características-dos-sensores-homologados)
---

## 1. Apresentação do Sistema

A Estação Meteorológica IoT é um sistema para monitoramento ambiental distribuído, projetado para operar de forma autônoma e com baixo consumo energético. A solução utiliza comunicação **LoRaWAN**, permitindo a coleta e visualização remota de dados meteorológicos por meio de plataformas web.

O sistema foi desenvolvido, primeiramente, para aplicações no Agronegócio e na Agricultura Familiar, tendo sido estendido posteriormente para aplicações acadêmicas, experimentais e de pesquisa. Como parte do projeto, o campus universitário da Unicamp possibilitará a instalação de múltiplas estações distribuídas geograficamente.

---

## 2. O que você recebeu

- Uma caixa para a instalação da estação;
- Uma placa da Estação Meteorológica;
- Um módulo WCM;
- Sensores:
  - BH1750, sensor de luminosidade;
  - BME280, sensor de pressão, temperatura e umidade;
  - GPS, sensor de posição;
- 3 Cabos JST XH de 4 pinos;
- Um Painel Solar;
- Manual de instruções.

---

## 3. Visão Geral do Funcionamento

A estação opera de forma totalmente automática após a instalação. O ciclo de funcionamento é composto por:

1. Coleta periódica dos dados ambientais  
2. Processamento local das medições  
3. Empacotamento dos dados  
4. Transmissão via LoRaWAN  
5. Recepção pelo gateway  
6. Armazenamento e visualização no backend  

Não é necessária intervenção do usuário durante a operação normal.

---

## 4. Instalação Física da Estação

Para garantir o funcionamento adequado da estação, siga as orientações abaixo:

1. Instale a estação em local aberto e bem ventilado  
2. Evite proximidade com superfícies metálicas ou obstáculos  
3. Posicione o painel solar voltado para o norte geográfico com uma inclinação que depende da latirude do local de instalação 
4. Instale os módulos segundo os seguintes passos:
   - Conecte os módulos I2C (BH1750 e BME280) na placa da estação com os cabos JST XH de 4 pinos fornecidos;
   - Conecte o GPS na placa da estação com o cabo JST XH de 4 pinos fornecido;
   - Conecte o painel solar a placa da estação atravês do conector KRE;
   - Obs.: Para a configuração inicial será necessário conectar a placa da estação via um cabo usb a um terminal serial.

---

## 5. Configuração da Estação

Obs.: Obrigatória na primeira energização.

- A estação meteorológica inicia automaticamente seu funcionamento assim que é energizada.  
- Para energizar a estação ligue as chaves na sequinte sequência:
	+ SW2
	+ SW3
	+ SW1
- Caso queira ajustar os parâmetros da estação use o terminal serial USB. Para isso pressione o botão Config da placa da estação antes de energizá-la (ou de pressionar o botão Reset). Mantenha pressionado o botão Config até que apenas o LED Vermelho fique aceso (demora aproximadamente 10 segundos). Solte o botão Config.
- A configuração é realizada através de **menus textuais** exibidos no monitor serial.
  - O menu permite ajustar parâmetros gerais, de comunicação, os intervalos de coleta de dados e ativar ou desativar os sensores, conforme será descrito a seguir.
- Para configurar os parâmetros da estação, pressione a letra/número correspondente ao item desejadoo. Alguns parâmentros têm seu valor atualizado automaticamente e outros necessitam que se digite o valor desejado seguido de Enter.

### Tela de Configuração Geral da Estação

As imagens abaixo mostram telas do menu:
  
- Quando configurando parâmetros ABP:
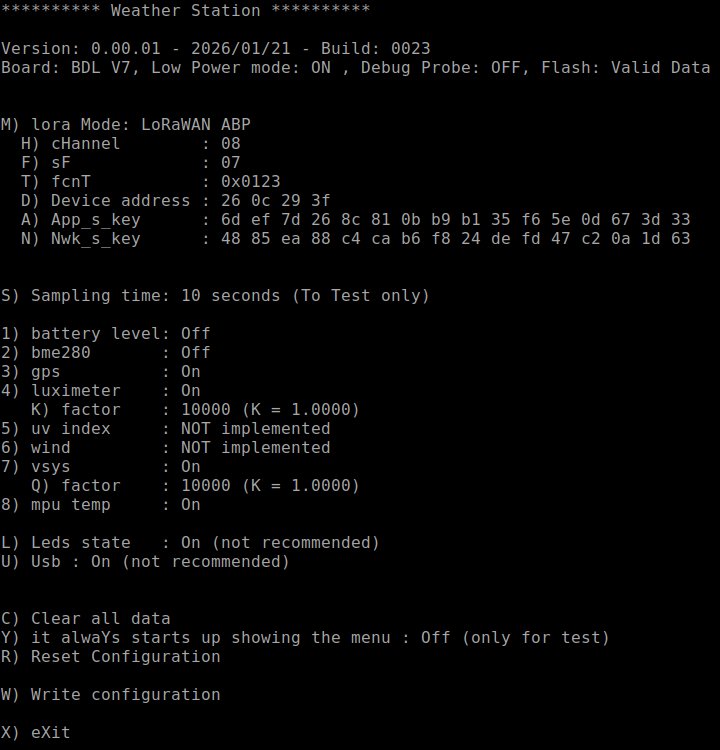
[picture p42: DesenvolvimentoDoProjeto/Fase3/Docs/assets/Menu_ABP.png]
Menu de Configuração ABP
  
  
- Quando configurando parâmetros OTAA:
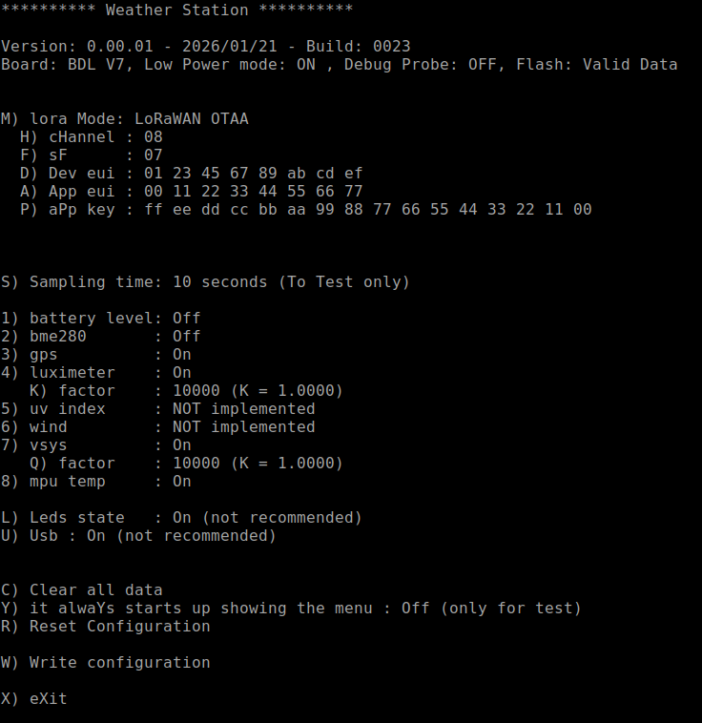
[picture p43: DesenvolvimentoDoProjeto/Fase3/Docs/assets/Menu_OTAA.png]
Menu de Configuração OTAA
  
---

### 5.1 Parâmetros LoRaWAN

- Para selecionar entre os modos ABP ou OTAA utilize a tecla M  
- Cada modo tem seus próprios parâmetros configuráveis, sendo:  
	+ Modo ABP:
		* Canal  
		* Sf  
		* fcnt
		* Device Address
		* App_s_Key
		* Nwk_s_Key
 	
  + Modo OTAA:
		* Canal  
		* Sf  
		* Dev EUI
		* App EUI
		* App Key

	- Obs.: Em operação normal os parâmetros Canal e Sf devem está em AUTO.  

---

### 5.2 Definição dos Intervalos de Coleta

Selecione a tecka S para escolher os intervalos de coleta entre 10 segundos (apenas para teste) e 1, 2, 5, 10, 15, 20, 30, 45 ou 60 minutos.  

---

### 5.3 Seleção dos Sensores Ativos

- **1) batery level** – Ainda não implementado.  
- **2) bme280** – Para medir a umidade relativa, a temperatura e a pressão atmosférica.  
- **3) gps** – Para medir a latitude, a longitude e altitude.  
- **4) luxímetro** – Para medir a luminosidade do ambiente. 
    - **K) factor** – Fator de correção do luxímetro.
- **5) uv index** – Ainda não implementado.  
- **6) wind** – Ainda não implementado.  
- **7) vsys** – Para medir a tensão de alimentação da placa.  
    - **Q) factor** – Fatpr de correção do Vsys.
- **8) mpu temp** – Para medir a temperatura interna do microcontrolador.  

---

### 5.4 Seleção dos Modos de Log (afetam o consumo da estação)

- **L) Leds state** – Se ativado, os LEDS exibem o estado da estção, ou seja:
  - Sleeping - Estação em modo de baixo consumo.  
  - Coleta - Estação em modo de aquisição de dados dos sensores.  
  - Transmissão - Estação em modo de envio de dados ao gateway.  

- **U) Usb** – Para escolher entre os modos do USB:  
  - OFF - Desativa a porta USB,  
  - ON - Mantêm a porta USB sempre ativa.  
  - ON-OFF AUTO - Ativa a USB apenas se a estação está em modo de aquisição ou transmissão de dados.  

---

### 5.5 Opções Adicionais do Menu

- **C) Clear all data** – Apaga todos os registros locais, **é necessário ser executado na primeira inicialização da estação**.  
- **R) Reset configuration** – Restaura os parâmetros de fábrica na tela.  
- **W) Write configuratiom** – Salva as alterações das configurações.
- **X) eXit** – Encerra o menu de configuração e ativa a operação da estação.  

---

## 6. Funcionamento da Estação

Após a energização do sistema os LEDs R, G e B pisca rapidamente na sequência vermelho, verde e azul.

Se o botão Config ficar pressionado durante o periodo que os LEDs Verde e Vermelho estiverem acessos a estação entrará em modo de configuração.

### 6.1 Indicações dos LEDs da Placa

Durante a operação, os LEDs acessos indicam:
- Verde e Vermelho ==> Inicializando e aguardado se entra ou não no modo de configuração (dura uns 10 segundos);
- Vermelho ==> Modo de configuração ativo. O menu pode ser acessado pela USB;
- Azul e Verde ==> Sai do menu de configuração e continua a inicialização. Periodo bem curto, menos de 1 segundo;
- Vermelho piscando ==> Falha na inicialização dos sensores. A estação aguarda correção;  
- Azul ==> A estação faz a aquisição dos dados dos sensores;
- Azul, Verde e Vermelho ==> A estação transmite os dados;
- Nenhum LED acesso ==> Periodo entre aquisições. A estação está em baixo consumo.

---

### 6.2 Indicações do Monitor Serial

Durante a operação da estação, se o log USB estiver ativo, o monitor serial mostrará os dados enviados para o servidor, bem como o resultado do envio.  

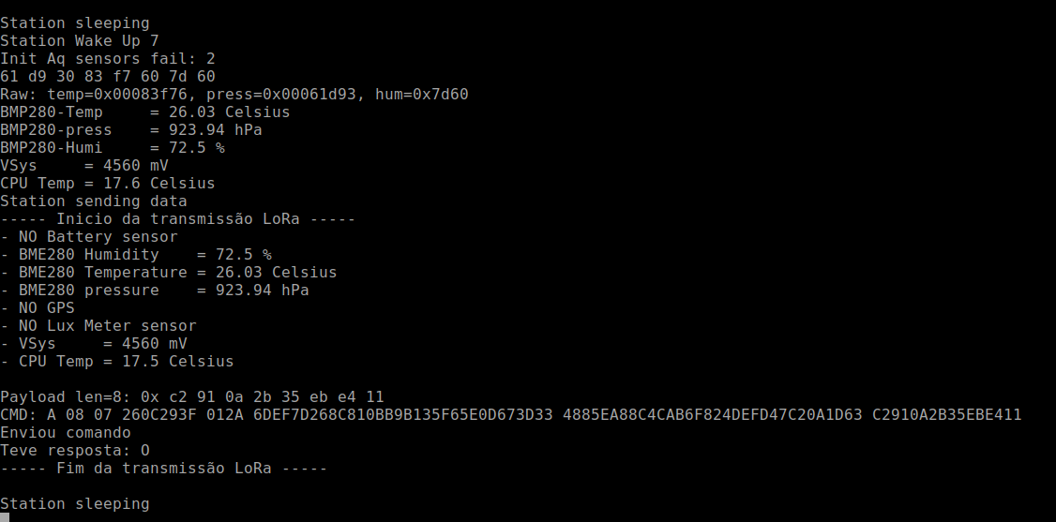
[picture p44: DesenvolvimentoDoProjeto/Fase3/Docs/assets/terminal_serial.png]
Terminal serial


---

## 7. Configuração do The Things Network (TTN) Gateway

Veja: 
[Link][https://docs.google.com/document/d/1o25VC49TM4YPC_RLyG_XDTTJo1DXNHsViMWomo7teZQ/edit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]

---

## 8. Configuração do TheThingsBoard

Veja: 
[Link][https://docs.google.com/document/d/1o25VC49TM4YPC_RLyG_XDTTJo1DXNHsViMWomo7teZQ/edit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]

---

## 9. Especificações Técnicas da Estação

### Principais características
  
- Placa principal dedicada com a taspberry pi pico.  
- Software Build: 0021 ou superior.
- Consumo médio:  
	+ Sleep mode: 6 mA
	+ Estação transmitindo os dados coletados: 97 mA  

  Obs.: Sem GPS conectado.  

- Duração estimada da bateria sem alimentação solar (noite, nublado):
  - sem GPS ligado: em avaliação  
  - com GPS ligado: em avaliação  
	+ Considerando:
    - Bateria 18650 de 2000 mA hora  
    - Comunicação a cada 5 minutos  

### Características dos sensores homologados

| Sensor | Grandeza | Unidade | Range | Precisão | Faixa de Operação |Consumo | Outros |
| --- | --- | --- | --- | --- | --- | --- | --- |
| BME280 | Pressão | hPa| 300 a 1100 hPa|+/- 1 hPa (de 0 a +40 ºC) | -40 a +85 ºC | 1120 uA peak | I2C address = 0x60 |
| BME280 | Temperatura | ºC | 0 a 65 ºC| +/-1.0 ºC | |
| BME280 | Umidade relativa | % | 0 a 100 %|  | |
| BH1750 | Luminosidade | lx | 0 a 65535 * | | -40 a +85 ºC | 190 uA | I2C address = 0x23 0x5C |

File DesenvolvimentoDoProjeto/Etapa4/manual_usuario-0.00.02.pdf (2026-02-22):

manual_usuario-0.00.02.md | 2025-09-14

# 📖 Manual do Usuário – Estação Meteorológica para o Agronegócio e a Agricultura Familiar


Autores: Carlos Martinez Perez e Ricardo Jorge Furlan

Versão: 0.00.02 de 12/09/2025

## Índice

📖 Manual do Usuário – Estação Meteorológica para o Agronegócio e a Agricultura Familiar Índice
0. O que você recebeu
1. Instalação dos Módulos
2. Configuração da Estação
Tela 1 – Configuração Geral da Estação 2.1 Parâmetros da Estação
2.2 Parâmetros da Comunicação
2.3 Definição dos Intervalos e Clock 2.4 Sensores I2C Ativos
2.5 Sensores Digitais Ativos
2.6 Sensores Analógicos Ativos 2.7 Opções de Sistema
Tela 2 – Ajustes de Data e Hora

2.8 Ajuste de Data e Hora
3. Funcionamento da Estação
3.1 Indicações do LED RGB
3.2 Indicações do Display da Placa Mãe 3.3 Indicações do Monitor Serial
4. Instalação do Servidor
5. Uso do Grafana
5.1 Painéis do Dashboard
Escolha da estação
Indicadores em tempo real (Gauges) Temperaturas mínimas e máximas do dia Médias semanais
Mapa das estações
Gráfico de históricos
5.2 Como Acessar o Dashboard
6. Especificações Técnicas da Estação
Principais características
Características dos sensores homologados Características dos sensores em homologação Especificação do servidor

## 0. O que você recebeu

Uma caixa suporte para os principais sensores; Uma placa BitDogLag;
Sensores:
BMP280, sensor de pressão e temperatura; AHT10, sensor de umidade e temperatura; BH1759, sensor de luminosidade;
RTC DS3131;
Placa Expansora I2C;
4 Cabos JST XH de 4 pinos;
1 Cabo JST XH de 4 pinos para RTC; Cabo USB;
Manual de instruções.

## 1. Instalação dos Módulos

Para colocar a estação meteorológica para o Agronegócio e a Agricultura Familiar em funcionamento, instale os módulos segundo os seguintes passos:

Conecte os módulos I2C na placa expansora I2C com os cabos JST XH de 4 pinos fornecidos; Conecte a placa expansora o RTC com o cabo JST XH de 4 pinos para RTC; Obs.: Cuidado ao conectar na placa expansora pois ela possui um conector que é exclusivo para fazer a conexão com a BitDogLab;
Conecte a placa expansora com o cabo JST XH de 4 pinos, ao conector I2C-0 da BitDogLab;

Para os módulos que não são I2C siga as instruções contidas nos respectivos manuais;
Conecte A BitDogLab a uma fonte USB de 5 Volts para o funcionamento normal. Obs.: é Fornecido separadamente vários modelos de fontes de 5 Volts USB, cada uma com um tipo de fonte energética como:Energia solar, eólica, rede elétrica etc, consulte;
Obs.: Para a configuração inicial da estação será necessário conectar a BitDogLab em um terminal serial USB.

## 2. Configuração da Estação

A estação meteorológica inicia automaticamente seu funcionamento assim que for energizada.
Case se deseje ajustar os parâmetros da estação, configuração, que será feito via terminal serial USB, basta pressionar o botão A da BitDogLab antes de energizá-la, e mantenha pressionado até o LED azul ficar aceso após o display acender, ai pode soltá-lo e conectar o terminal serial
A configuração é realizada através de menus textuais exibidos no monitor serial.
O primeiro menu permite ajustar parâmetros gerais, de comunicação, os intervalos de operação e ativar e desativar os sensores disponíveis, conforme será descrito a seguir.
O segundo menu permite que se ajuste o Relógio, Obs.: caso não se utiliza RTC sempre ao energizar a estação se entrará no menu de ajuste do relógio.

Tela 1 – Configuração Geral da Estação

A imagem abaixo mostra a tela de configuração geral da estação:


2.1 Parâmetros da Estação

Escolha o número do menu, atualize com o valor desejado e pressione Enter para alterar.

Nome – Identificação da estação na rede.
Token (PSW) – Senha utilizada para autenticação junto ao servidor.
Grupo – Permite organizar várias estações sob um mesmo identificador. Latitude / Longitude / Elevação – Definem a posição geográfica da estação.

2.2 Parâmetros da Comunicação

Escolha o número do menu, atualize com o valor desejado e pressione Enter para alterar.

WiFi SSID – Nome da rede Wi-Fi que será utilizada.
WiFi PSW – Senha da rede Wi-Fi.
IP do Servidor – Endereço IP do servidor central.
Porta do Servidor – Porta TCP usada para envio dos dados.

2.3 Definição dos Intervalos e Clock

Pressione a letra do menu para escolher os valores desejados.

A) Intervalo de captura – Tempo entre cada registro da leitura dos sensores. Escolha um dos intervalos pré definidos: 1 s, 2 s, 5 s, 10 s, 20 s, 1 min, 2 min, 5 min, 10 min, 20 min ou 1 hora.
B) Intervalo de envio – Tempo entre transmissões de dados para o servidor. Escolha um dos intervalos pré definidos: 10 s, 20 s, 1 min, 2 min, 5 min, 10 min, 20 min, 1 hora, 2 horas, 6 horas, 12 horas, 1 dia ou Desativado.
C) Intervalo de show – Frequência de envio das informações para o terminal serial. Escolha um dos intervalos pré definidos: 1 s, 2 s, 5 s, 10 s, 20 s, 1 min, 2 min, 5 min, 10 min, 20 min, 1 hora, 2 horas, 6 horas, 12 horas, 1 dia ou Desativado.
D) Intervalo de sync CLK – Período para sincronização do relógio. Escolha um dos intervalos pré definidos: 1 s, 2 s, 5 s, 10 s, 20 s, 1 min, 2 min, 5 min, 10 min, 20 min, 1 hora, 2 horas, 6 horas, 12 horas, 1 dia ou Desativado.
E) Intervalo de retry – Tempo de espera entre tentativas de reconexão com o servidor. Escolha um dos intervalos pré definidos: 1 s, 2 s, 5 s, 10 s, 20 s, 1 min, 2 min, 5 min, 10 min, 20 min, 1 hora, 2 horas, 6 horas, 12 horas ou 1 dia.
F) CLK enable – Ativa ou desativa o uso do módulo RTC (Real Time Clock).

2.4 Sensores I2C Ativos

Pressione a letra correspondente para ativar ou desativar os sensores I2C.

G) Pressão e Temperatura (BMP280) – Mede pressão atmosférica e temperatura.
H) Umidade e Temperatura (AHT10) – Mede umidade relativa do ar e temperatura.
I) Intensidade Luminosa (BH1750) – Mede luminosidade ambiente.
J) Direção do Vento (HMCS5883) – Magnetômetro que indica direção do vento.

2.5 Sensores Digitais Ativos

Pressione a letra correspondente para ativar ou desativar os sensores digitais.

M) Anemômetro – Mede a velocidade do vento.
N) Pluviômetro – Mede volume de chuva acumulado.

2.6 Sensores Analógicos Ativos

Pressione a letra correspondente do sensor para escolher a porta analógica em que ele está conectado. A porta 0 é a entrada analógica da BitDogLab. As portas de 1 a 8 são da placa de conversão analógico/digital AD5592 (item opcional).

O) Índice UV – Mede intensidade de radiação ultravioleta.
P) Temperatura do solo – Mede a temperatura do solo.
S) Umidade do solo – Mede a umidade do solo.
T) Concentração CO – Mede concentração de monóxido de carbono.
U) Concentração CO₂ – Mede concentração de dióxido de carbono.
V) Concentração O₃ – Mede concentração de ozônio.

2.7 Opções de Sistema

Pressione a letra correspondente para realizar a operação desejada.

Y) Reset Configuração – Restaura os parâmetros de fábrica na tela.
Z) Limpa todos os dados – Apaga todos os registros locais, é necessário ser executado na primeira inicialização da estação.
W) Grava os Dados (Write) – Salva as alterações de configuração realizadas.
X) Sair (Exit) – Encerra o menu de configuração.

Tela 2 – Ajustes de Data e Hora

A imagem abaixo mostra a tela de ajuste de Data e Hora:


2.8 Ajuste de Data e Hora

Pressione os números ou letras correspondentes para incrementar ou decrementar as variáveis de data e hora e para salvar ou sair.

1+ / 2- – Incrementa ou decrementa o ano.
3+ / 4- – Incrementa ou decrementa o mês.
5+ / 6- – Incrementa ou decrementa o dia.
7+ / 8- – Incrementa ou decrementa a hora.
9+ / 0- – Incrementa ou decrementa os minutos.
A+ / B- – Incrementa ou decrementa os segundos.
S) Save – Grava as alterações feitas.
X) Sair (Exit) – Vai para a coleta de dados meteorológicos.

Ao sair com a tecla X, é mostrada a mensagem **** Fim da Configuração do Clock **** e a estação entra em operação.

## 3. Funcionamento da Estação

Após a energização do sistema o LED RGB pisca rapidamente em sequências as cores vermelho, verde e azul, na sequência o Display pisca e mostra a mensagem:

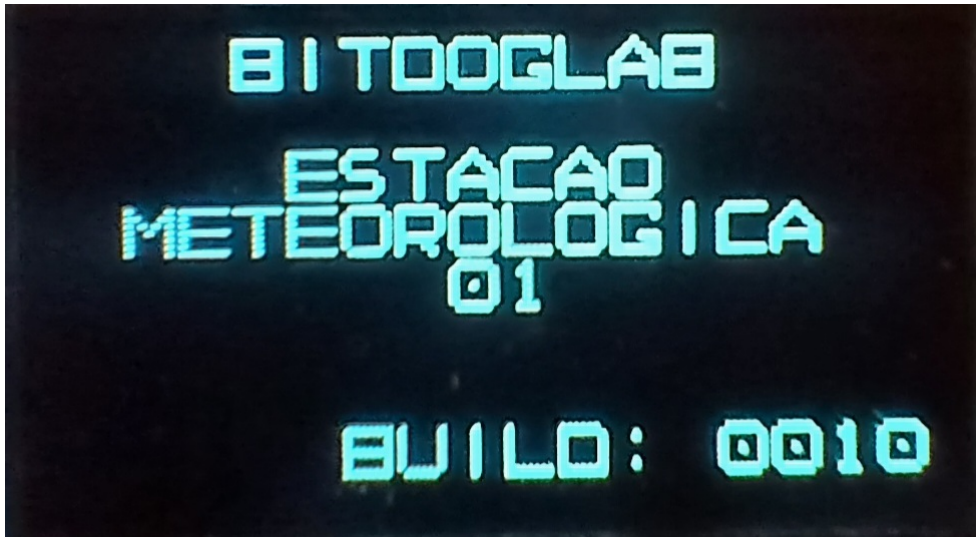
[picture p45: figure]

Se o botão A for pressionado quando o display ainda está piscando e continuar assim até o LED azul ficar acesso, a estação ativa o modo de configuração, conforme já mencionado acima. Após a configuração e/ajuste do relógio a operação da estação meteorológica começa.

3.1 Indicações do LED RGB

Durante a operação, a cor do LED indica:

Vermelho ==> Não há conexão com o roteado;
Verde ==> Conexão WiFi estabelecida com o roteador, roteador, e não houve falhas de acesso ao servidor;
Amarelo ==> Conexão WiFi estabelecida com o roteador, mas a última tentativa de conexão com o servidor falhou
Piscadas Azuis ==> Dados da estação estão sendo salvos na memória não volátil

3.2 Indicações do Display da Placa Mãe

Durante o funcionamento o display é atualizado a cada nova aquisição de dados. As 3 primeiras linhas do display são fixas e indicam:

"DATA" - A data atual (UTC)
"TIME" - A hora atual (UTC)
"CYCLE" - número de aquisições feitas desde quando os dados foram limpos da memória

As 4 últimas linhas trazem informações da estação e das leituras efetuadas e com o joystick é possivel navegar entre elas:

Build : Build do software;
linha em branco;
nome_da_estação;

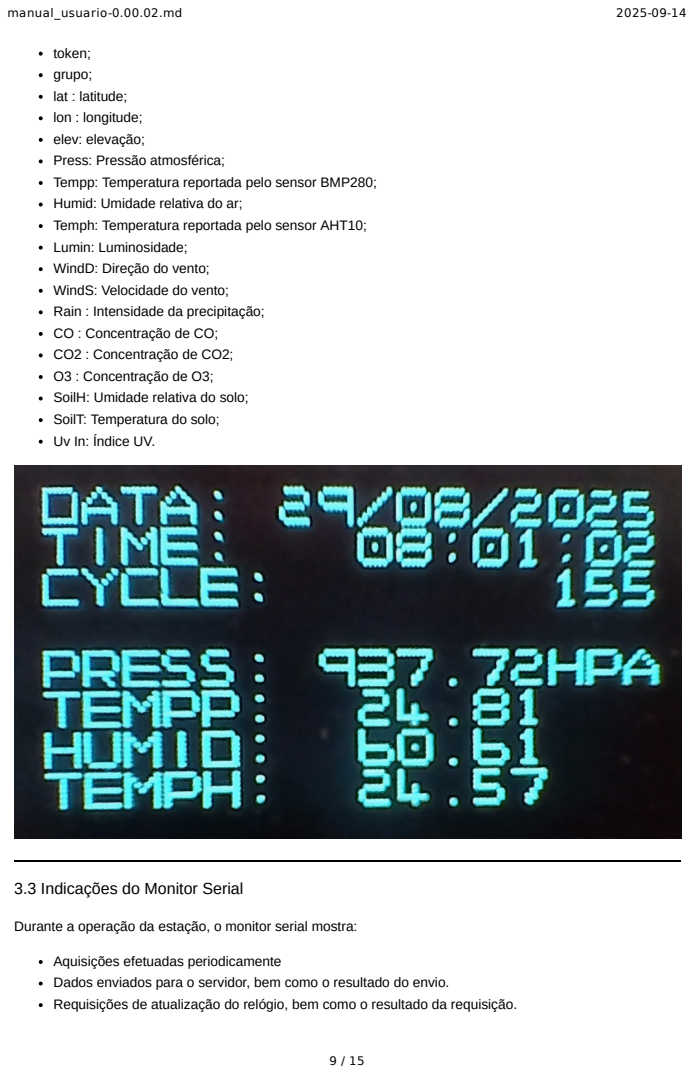
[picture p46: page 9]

token;
grupo;
lat : latitude;
lon : longitude;
elev: elevação;
Press: Pressão atmosférica;
Tempp: Temperatura reportada pelo sensor BMP280;
Humid: Umidade relativa do ar;
Temph: Temperatura reportada pelo sensor AHT10;
Lumin: Luminosidade;
WindD: Direção do vento;
WindS: Velocidade do vento;
Rain : Intensidade da precipitação;
CO : Concentração de CO;
CO2 : Concentração de CO2;
O3 : Concentração de O3;
SoilH: Umidade relativa do solo;
SoilT: Temperatura do solo;
Uv In: Índice UV.

3.3 Indicações do Monitor Serial

Durante a operação da estação, o monitor serial mostra:

Aquisições efetuadas periodicamente
Dados enviados para o servidor, bem como o resultado do envio.
Requisições de atualização do relógio, bem como o resultado da requisição.


## 4. Instalação do Servidor

Para que os dados da estação possam ser armazenados remotamente e acessos pela internet é necessário instalar o servidor. Esta versão básica de servidor é de simples instalação e inclui todos os componentes necessários e roda em contêiner. Para instalar e levantar o servidor faça:

download dos arquivos do servidor em https://github.com/EmbarcaTech-2025/projeto-final-carlos_ricardo/tree/main/Etapa4/Servidor em um diretório servidor
no terminal entre no diretório servidor
rode:
$ docker-compose build
e depois rode:
$ docker-compose up

Isso colocará no ar três contêiner docker com as funcionalidades necessárias:

API
Banco de dados
Grafana Obs.: É possível acompanhar a chegada das requisições da estação monitorando o terminal a onde foi executado o comando:
$ docker-compose up Exemplo abaixo:

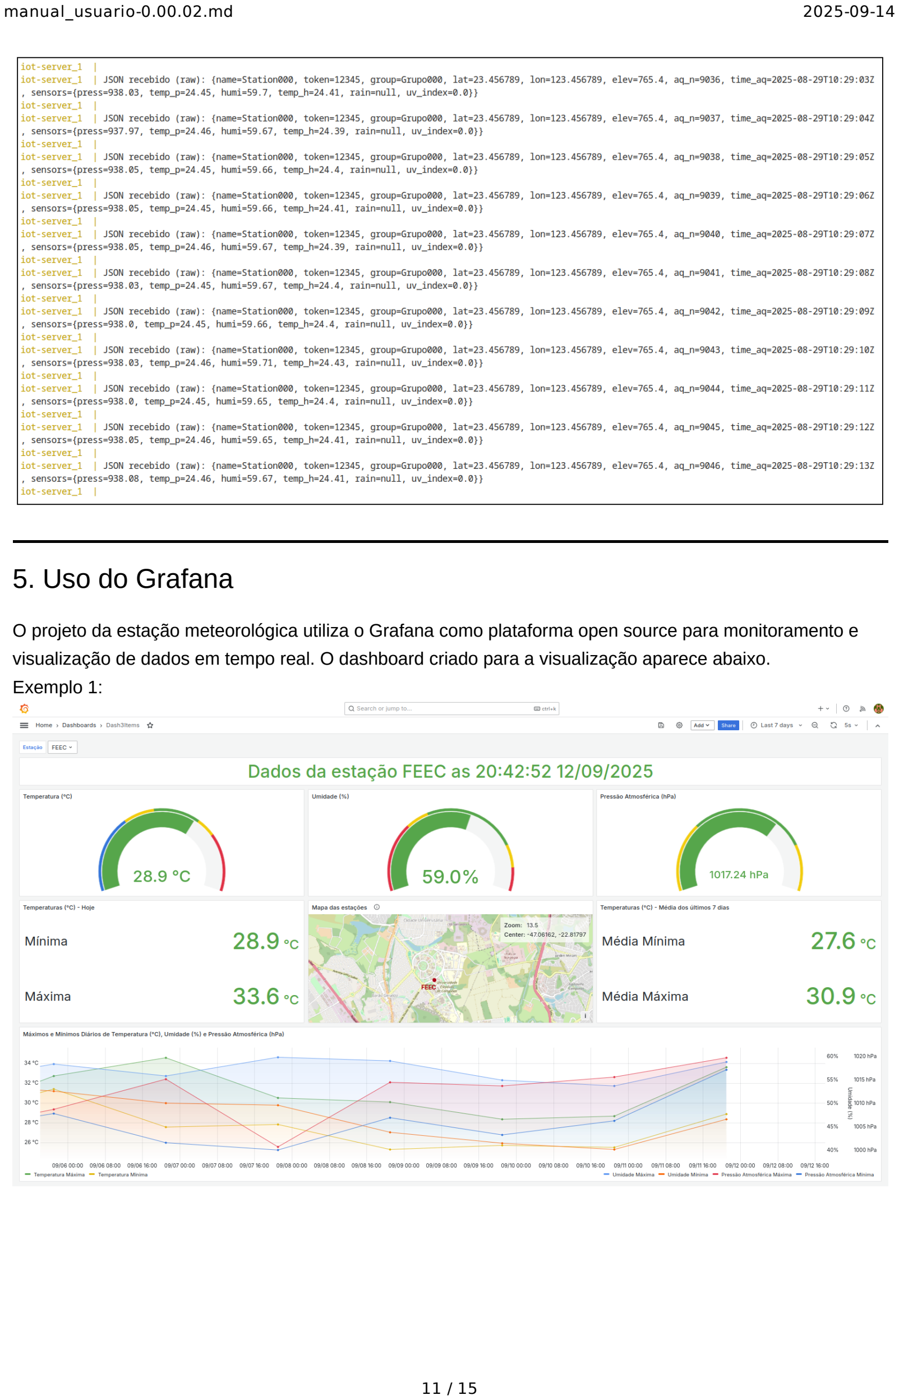
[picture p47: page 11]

## 5. Uso do Grafana

O projeto da estação meteorológica utiliza o Grafana como plataforma open source para monitoramento e visualização de dados em tempo real. O dashboard criado para a visualização aparece abaixo.
Exemplo 1:

Exemplo 2:


5.1 Painéis do Dashboard

Descrição do exemplo1

Escolha da estação

Selecione a estação que deseja visualizar no painel Device, no canto superior esquerdo do dashboard. Um menu suspenso mostra as estações que tiveram dados colhidos. O dashboard é atualizado instantaneamente.

Indicadores em tempo real (Gauges)

Os três painéis superiores exibem as últimas informações colhidas para temperatura, umidade relativa e pressão atmosférica no local da estação.

Temperaturas mínimas e máximas do dia

O painel de central à esquerda exibe as temperaturas mínima e máxima do dia.

Médias semanais

O painel direito central apresenta as médias semanais, mostrando os valores médios das temperaturas mínima e máxima registradas nos últimos 7 dias da a estação selecionada.

Mapa das estações

No centro do dashboard, o mapa exibe a localização geográfica da estação selecionada.

Gráfico de históricos

O gráfico na parte inferior do dashboard apresenta as séries temporais das medições da estação selecionada, permitindo acompanhar a evolução das temperaturas máxima e mínima, das umidades relativas máxima e mínima e das pressões atmosféricas máxima e mínima dds dados dos últimos 7 dias. A figura abaixo mostra um exemplo do gráfico:

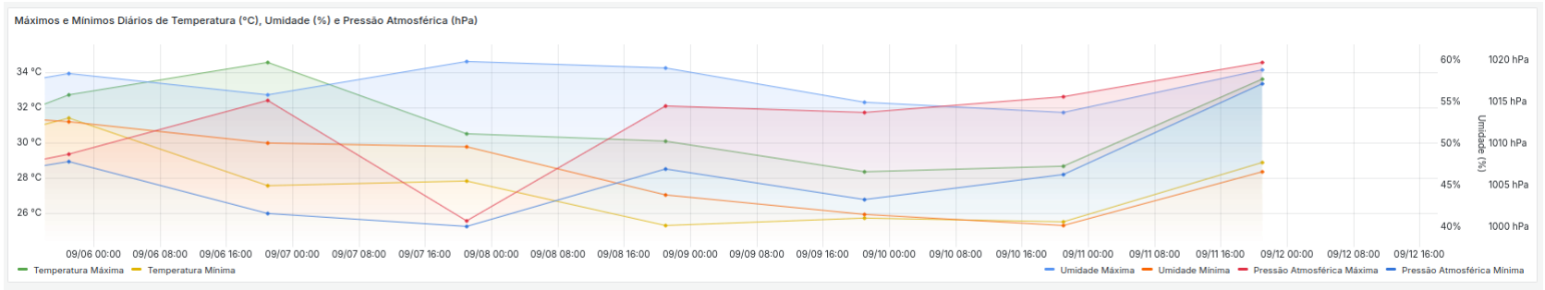
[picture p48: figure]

5.2 Como Acessar o Dashboard

Para ter acesso ao dashboard, siga estes passos:

1. Abrir o navegador: a partir de qualquer navegador web, acesse o endereço http://localhost:3000/login. Esse é o gateway de acesso ao Grafana, desde que o servidor esteja em execução.
2. Login no Grafana: insira o nome de usuário e senha cadastrados para acessar o ambiente do Grafana.
3. Configurar a fonte de dados (Data Source):

No menu lateral, selecione Connections → Data sources. Clique em Add data source e escolha a opção PostgreSQL.

4. Conectar ao banco de dados: na tela de configuração do PostgreSQL, informe os seguintes dados:

Nome do banco: o nome definido na instalação/configuração do banco de dados. Usuário e senha: credenciais de acesso ao banco.
TLS/SSL: selecionar a opção Disabled.
5. Salvar e testar: clique em Save & test para verificar se a conexão foi estabelecida corretamente.
6. Acessar o dashboard: depois que a conexão com o banco de dados for validada, é possível visualizar os dashboards já configurados. Para isso:

No menu lateral do Grafana, clique em Dashboards.
No canto superior direito da tela, selecione a opção New → Import.
Escolha o dashboard desejado pelo nome na lista disponível ou insira o ID de um dashboard previamente exportado.
Clique em Load e confirme para abrir o painel e navegar.

## 6. Especificações Técnicas da Estação

Principais características

Placa mãe: BitDogLab V6.3.

Software Build: 0012 ou superior.

Consumo total médio típico:

WiFi desconectado: 46 mA
WiFi conectado: 70 mA
Transmitindo dados: 97 mA

Obs.: Sem sensores AD de alto consumo.

Duração estimada da bateria backup presente na BitDogLab: 20 horas

Para Bateria 18650 de 2000 mA hora

Modo de comunicação:

WiFi Conexão constante com o roteador, com reconexão automática.

Vida estimada da memória Flash:

> 12 anos Supondo uma aquisição salva por segundo.
> 120 anos Supondo uma aquisição salva a cada 10 segundos.

Ref.: minimo 100K escritas por setor(W25Q16JV).

Mecanismo de Integridade:

WatchDog com timeout de 45 segundos.

Características dos sensores homologados

Sensor | Grandeza | Unidade | Range | Precisão

Faixa de
Operação
Consumo | Outros
BMP280 | Pressão | hPa | 300- 1100hPa | +-1hPa (de 0 a +40C)
-40 - +85 C

1120 uA
peak

I2C
ad=0x76
BMP280 | Temperatura | Celsius | 0 - 65 C | +-1.0 C
AHT10 | Umidade | Relativa | 0 -
| | | 100%
+-3% | -40 - 100C | 23 ua

I2C
ad=0x38
AHT10 | Temperatura | Celsius | -40 - 80C | +- 0,4 C
BH1750 | Luminosidade | lx

0-65535
*
1.2x | -40 - +85C | 190 uA

I2C
ad=0x23
0x5C

Características dos sensores em homologação

Obs.1: Para sua inclusão na estação pode ser necessitar de atualização de firmware e/ou hardware Obs.2: Como os sensores estão em homologação a tabela abaixo é apenas um indicativo, com valores ausentes em virtude da homologação.

Sensor | Grandeza | Unidade | Range | Precisão

Faixa de
Operação
Sensor | Grandeza | Unidade | Range | Precisão | Consumo | Outros

Faixa de
Operação
| | | | | Consumo | Outros

HMC5883

Direção do
Vento

Graus

0-359
graus
1 grau | -30 - +85C | 100 uA

I2C
ad=0x1E
| Quantidade de chuva
mm | --- | --- | --- | ---
| Velocidade do Vento
m/s | --- | --- | --- | ---
Índice UV | índice | 0 - 12 | --- | --- | ---

Portas
AD de 0
a 8
Umidade do Solo | % | --- | --- | --- | ---

Portas
AD de 0
a 8
Temperatura do Solo | Celsius | --- | --- | --- | ---

Portas
AD de 0
a 8
Concentração de CO | ppm | --- | --- | --- | ---

Portas
AD de 0
a 8
Concentração de CO2 | ppm | --- | --- | --- | ---

Portas
AD de 0
a 8
Concentração de O3 | ppm | --- | --- | --- | ---

Portas
AD de 0
a 8

Especificação do servidor

Suporte a Docker contêineres 64 bits;
IP fixo;
Porta 8080 liberada para acesso externo;
1G de memoria Ram disponível para a aplicação;
16G de HD para a Aplicação;
Obs.: as configurações podem ser maiores dependendo do número de estações conectadas, taxa de dados adquiridas e número de dashboards ativos.

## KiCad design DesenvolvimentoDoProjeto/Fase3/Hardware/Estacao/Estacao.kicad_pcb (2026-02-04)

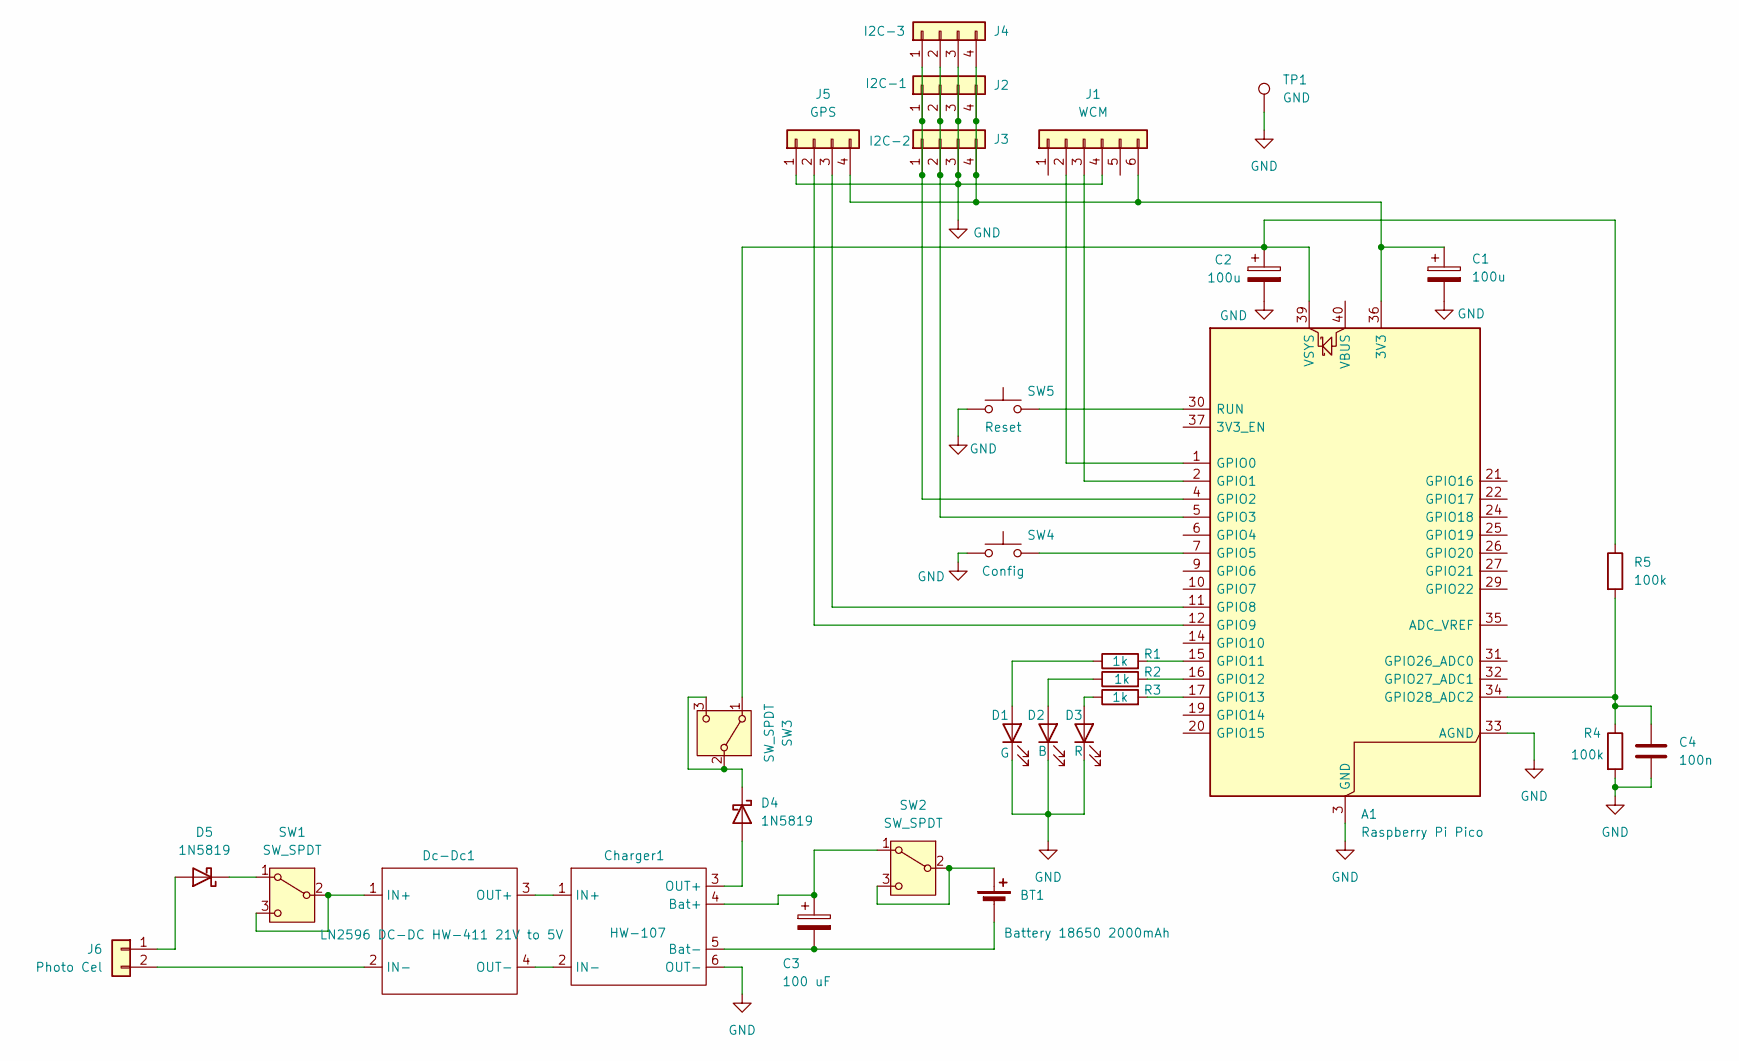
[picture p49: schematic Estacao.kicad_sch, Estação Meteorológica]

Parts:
A1: Raspberry Pi Pico; RaspberryPi_Pico_Common_Unspecified
BT1: Battery 18650 2000mAh; BatteryHolder_MPD_BK-18650-PC2b
C1, C2: 100u; CP_Radial_D7.5mm_P2.50mm
C3: 100 uF; CP_Radial_D7.5mm_P2.50mm
C4: 100n; C_Disc_D5.0mm_W2.5mm_P5.00mm
Charger1: HW-107; Charger
D1: G; LED_D5.0mm
D2: B; LED_D5.0mm
D3: R; LED_D5.0mm
D4, D5: 1N5819; D_DO-41_SOD81_P10.16mm_Horizontal
Dc-Dc1: LN2596 DC-DC HW-411 21V to 5V; Dc_DC
J1: WCM; PinSocket_1x06_P2.54mm_Vertical
J2: I2C-1; JST_XH_B4B-XH-A_1x04_P2.50mm_Vertical
J3: I2C-2; JST_XH_B4B-XH-A_1x04_P2.50mm_Vertical
J4: I2C-3; JST_XH_B4B-XH-A_1x04_P2.50mm_Vertical
J5: GPS; JST_XH_B4B-XH-A_1x04_P2.50mm_Vertical
J6: Photo Cel; BorneBatSolar
R1, R2, R3: 1k; R_Axial_DIN0207_L6.3mm_D2.5mm_P10.16mm_Horizontal
R4, R5: 100k; R_Axial_DIN0207_L6.3mm_D2.5mm_P10.16mm_Horizontal
SW1, SW2, SW3: SW_SPDT; switch_3p_2.54mm_on_off
SW4: Config; SW_PUSH_6mm
SW5: Reset; SW_PUSH_6mm
TP1: GND; PinHeader_1x01_P2.54mm_Vertical

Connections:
GND: A1.3 (GND), A1.8 (GND), A1.13 (GND), A1.18 (GND), A1.23 (GND), A1.28 (GND), A1.33 (AGND), A1.38 (GND), C1.2, C2.2, C4.2, Charger1.6 (OUT-), D1.1 (K), D2.1 (K), D3.1 (K), J1.4, J2.3, J3.3, J4.3, J5.1, R4.2, SW4.1, SW5.1, TP1.1
unnamed: A1.36 (3V3), C1.1, J1.6, J2.4, J3.4, J4.4, J5.4
unnamed: A1.1 (GPIO0), J1.2
unnamed: A1.2 (GPIO1), J1.3
unnamed: A1.4 (GPIO2), J2.1, J3.1, J4.1
unnamed: A1.5 (GPIO3), J2.2, J3.2, J4.2
unnamed: A1.7 (GPIO5), SW4.2
unnamed: A1.11 (GPIO8), J5.3
unnamed: A1.12 (GPIO9), J5.2
unnamed: A1.15 (GPIO11), R1.2
unnamed: A1.16 (GPIO12), R2.2
unnamed: A1.17 (GPIO13), R3.2
unnamed: A1.34 (GPIO28_ADC2), C4.1, R4.1, R5.2
unnamed: A1.30 (RUN), SW5.2
unnamed: A1.39 (VSYS), C2.1, R5.1, SW3.1 (A)
unnamed: BT1.1 (+), SW2.2 (B), SW2.3 (C)
unnamed: BT1.2 (-), C3.2, Charger1.5 (Bat-)
unnamed: C3.1, Charger1.4 (Bat+), SW2.1 (A)
unnamed: Charger1.1 (IN+), Dc-Dc1.3 (OUT+)
unnamed: Charger1.2 (IN-), Dc-Dc1.4 (OUT-)
unnamed: Charger1.3 (OUT+), D4.2 (A)
unnamed: D1.2 (A), R1.1
unnamed: D2.2 (A), R2.1
unnamed: D3.2 (A), R3.1
unnamed: D4.1 (K), SW3.2 (B), SW3.3 (C)
unnamed: D5.2 (A), J6.1
unnamed: D5.1 (K), SW1.1 (A)
unnamed: Dc-Dc1.1 (IN+), SW1.2 (B), SW1.3 (C)
unnamed: Dc-Dc1.2 (IN-), J6.2

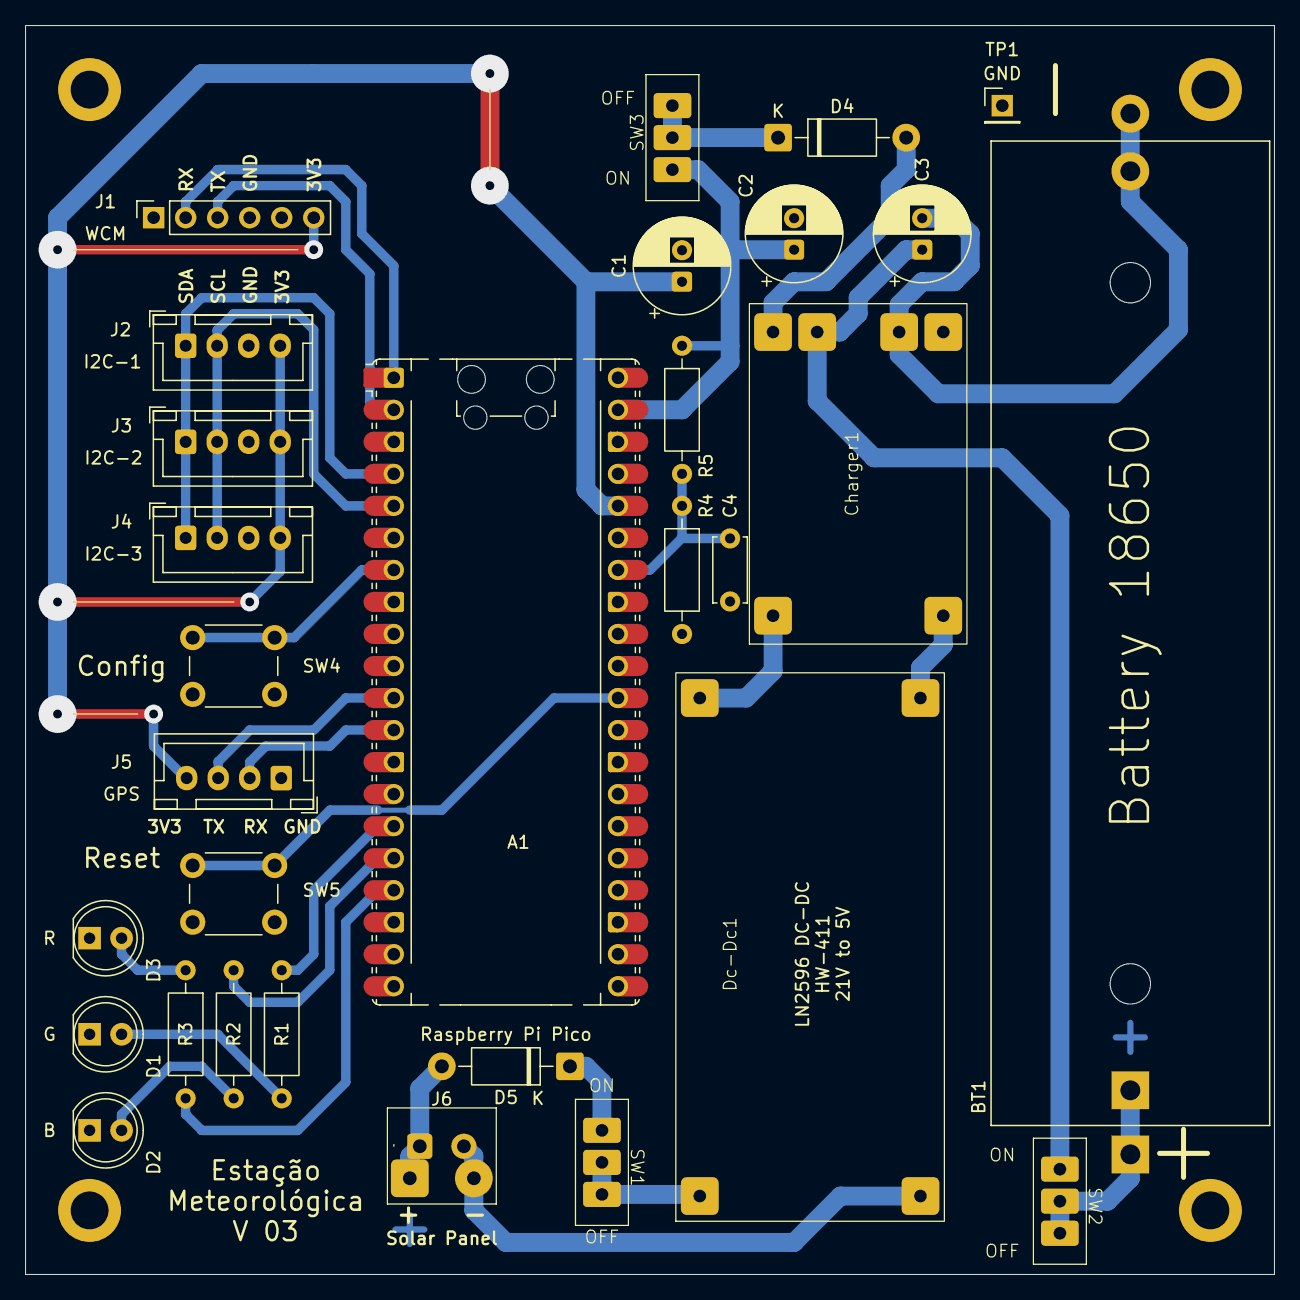
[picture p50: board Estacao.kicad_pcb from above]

Board: 2 copper layers, 99.1 x 99.1 mm, 30 parts (0 on the bottom side), 29 nets.

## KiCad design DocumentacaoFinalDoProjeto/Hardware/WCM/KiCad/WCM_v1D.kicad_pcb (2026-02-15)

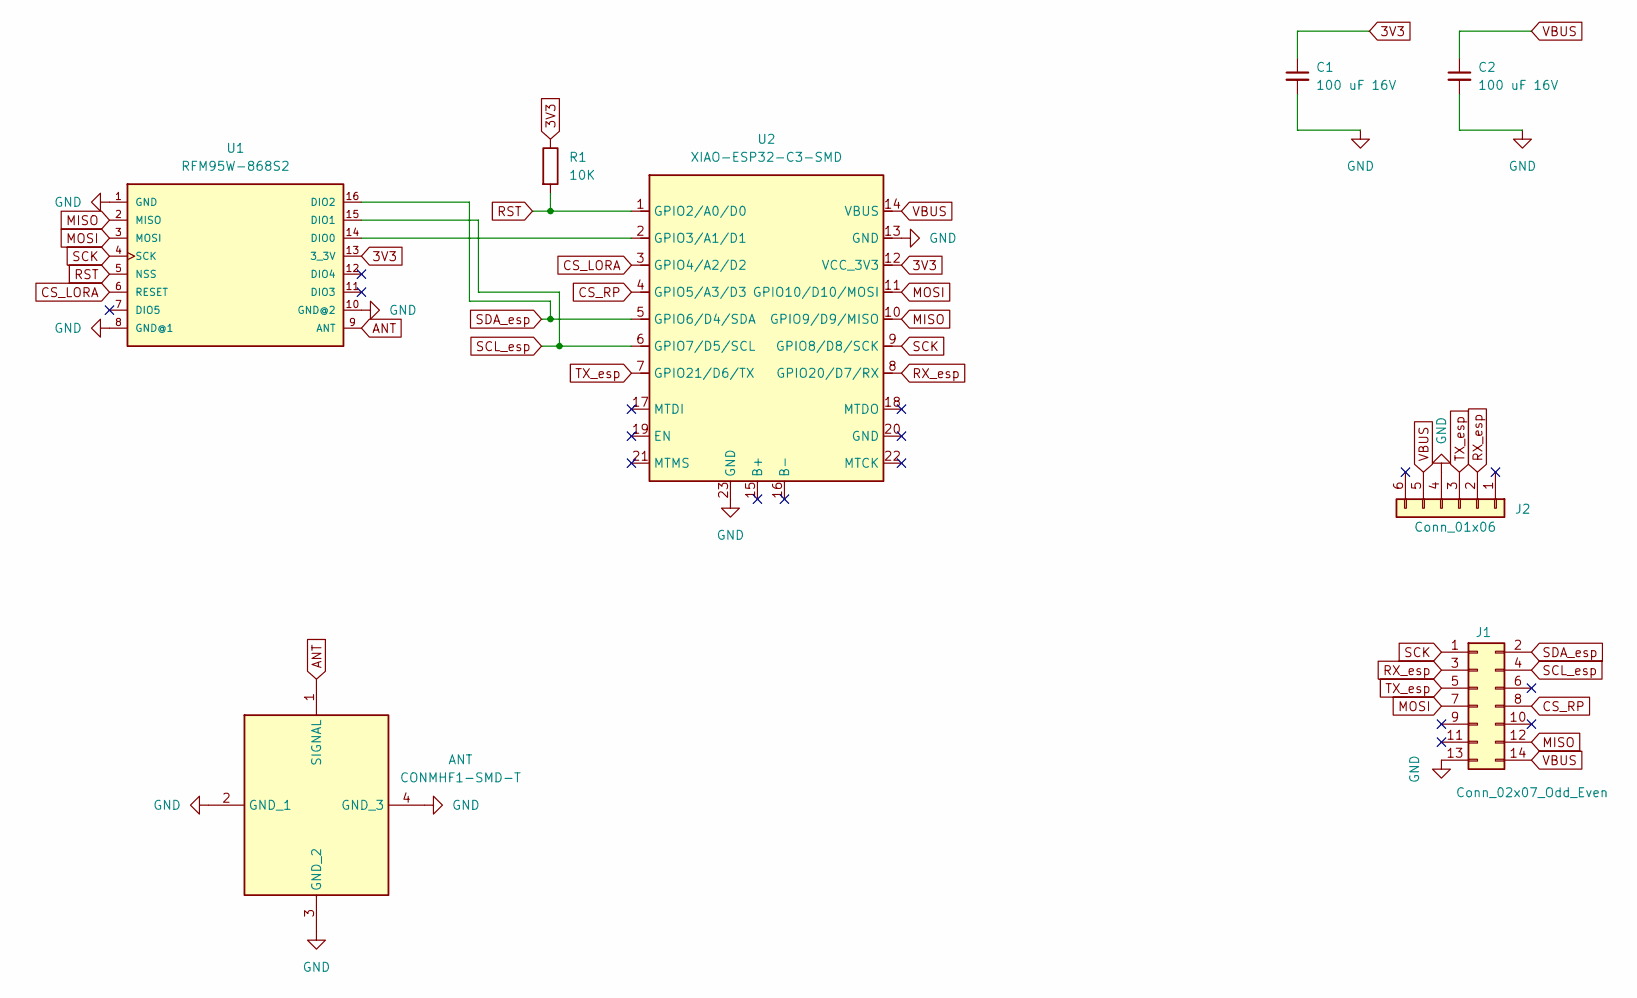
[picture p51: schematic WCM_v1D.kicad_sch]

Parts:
ANT: CONMHF1-SMD-T; CONMHF1SMDT; Mouser Part Number 712-CONMHF1-SMD-T
C1, C2: 100 uF 16V; CP_Elec_4x3.9
J1: Conn_02x07_Odd_Even; PinHeader_2x07_P2.54mm_Vertical_SMD
J2: Conn_01x06; PinHeader_1x06_P2.54mm_Vertical
R1: 10K; R_0603_1608Metric_Pad0.98x0.95mm_HandSolder
U1: RFM95W-868S2; XCVR_RFM95W-868S2
U2: XIAO-ESP32-C3-SMD; XIAO-ESP32C3-SMD

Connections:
3V3: C1.1, R1.1, U1.13 (3_3V), U2.12 (VCC_3V3)
ANT: ANT.1 (SIGNAL), U1.9 (ANT)
CS_LORA: U1.6 (RESET), U2.3 (GPIO4/A2/D2)
CS_RP: J1.8, U2.4 (GPIO5/A3/D3)
GND: ANT.2 (GND_1), ANT.3 (GND_2), ANT.4 (GND_3), C1.2, C2.2, J1.13, J2.4, U1.1 (GND), U1.8 (GND@1), U1.10 (GND@2), U2.13 (GND), U2.23 (GND)
MISO: J1.12, U1.2 (MISO), U2.10 (GPIO9/D9/MISO)
MOSI: J1.7, U1.3 (MOSI), U2.11 (GPIO10/D10/MOSI)
unnamed: U1.14 (DIO0), U2.2 (GPIO3/A1/D1)
RST: R1.2, U1.5 (NSS), U2.1 (GPIO2/A0/D0)
RX_esp: J1.3, J2.2, U2.8 (GPIO20/D7/RX)
SCK: J1.1, U1.4 (SCK), U2.9 (GPIO8/D8/SCK)
SCL_esp: J1.4, U1.15 (DIO1), U2.6 (GPIO7/D5/SCL)
SDA_esp: J1.2, U1.16 (DIO2), U2.5 (GPIO6/D4/SDA)
TX_esp: J1.5, J2.3, U2.7 (GPIO21/D6/TX)
VBUS: C2.1, J1.14, J2.5, U2.14 (VBUS)

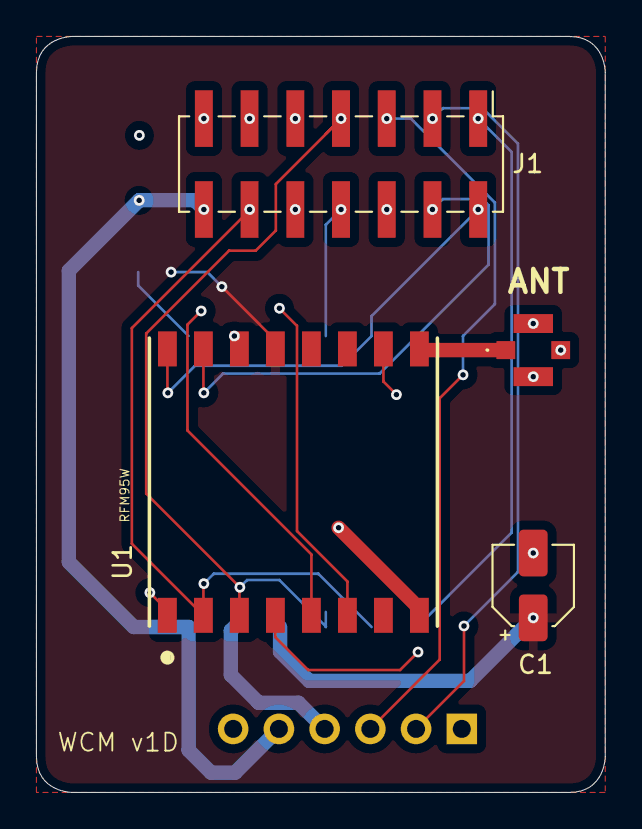
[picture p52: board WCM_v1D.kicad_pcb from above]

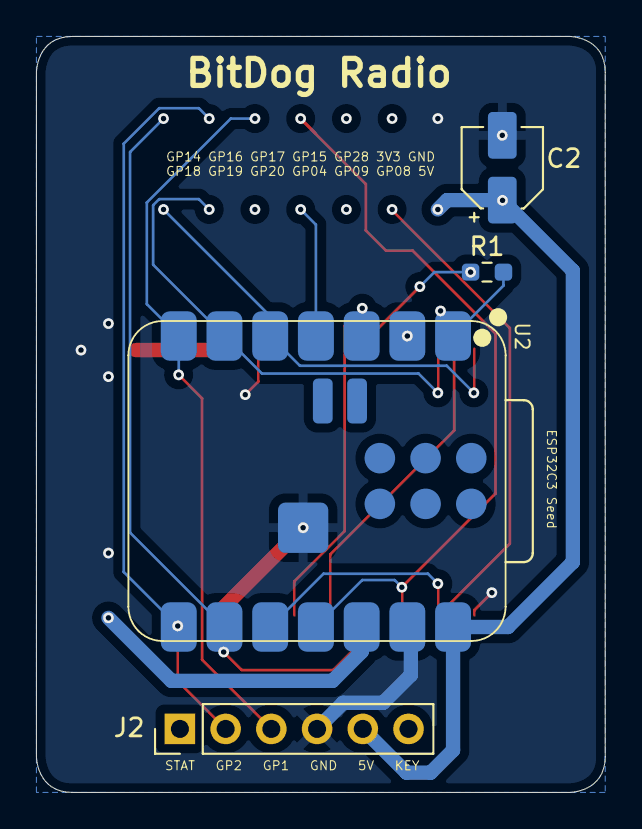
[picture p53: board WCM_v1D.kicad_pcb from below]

Board: 2 copper layers, 31.6 x 42.0 mm, 8 parts (4 on the bottom side), 15 nets.

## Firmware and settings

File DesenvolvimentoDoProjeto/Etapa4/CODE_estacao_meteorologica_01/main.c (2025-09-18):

/**
 * @file    main.c
 * @author  Carlos e Ricardo
 * @brief   Inicialização do sistema e main loop para transmissão de dados
 * @version 0.1
 * @date    2025-09-04
 * 
 * @copyright Copyright (c) 2025
 */

#include <stdio.h>
#include <pico/cyw43_arch.h>
#include "pico/stdlib.h"
#include "pico/multicore.h"
#include "hardware/i2c.h"
#include "include/config.h"
#include "include/config_data.h"
#include "include/core_communication.h"
#include "include/core0_comm.h"
#include "include/core1_main.h"
#include "include/led_rgb.h"
#include "include/menu_config.h"
#include "include/menu_clock.h"
#include "include/storage.h"
#include "include/ui_display.h"
#include "include/util.h"
#include "include/wrap_watchdog.h"
#include "include/wifi.h"
#include "include/wifi_tcp.h"

#define PAGE_SEND       "/dados"
#define PAGE_TIME       "/hora"


typedef enum {
    WIFI_ST_DISCONNECTED = 0,
    WIFI_ST_CONNECTED_NO_ERROR,
    WIFI_ST_CONNECTED_WITH_ERROR
} WiFiState;



/**
 * @brief Envia uma aquisição completa, ainda não enviada, para o servidor
 * 
 * @return true, o servidor recebeu a mensagem
 * @return false, o servidor não recebeu a mensagem
 */
static bool send_data(){
    char * url = config_data.server_ip;
    ip_addr_t ip;
    ip4addr_aton(url, &ip);

    int16_t size = estation_data_json(&core_comm_estation_data, estation_data_buf_tmp);
    //static uint32_t send_data_count = 0;
    //int16_t size = estation_data_json_full_fake(estation_data_buf_tmp, ++send_data_count);
    WifiTcpData * ret = wifi_tcp_send(ip, url, config_data.server_port, PAGE_SEND, estation_data_buf_tmp);

    if(ret == NULL) return false;
               else return wifi_tcp_answer_send(ret); 
}

/**
 * @brief  Get the server time object
 * 
 * @return true, recebeu a data/hora atual do servidor e atualizou o relógio local
 * @return false, não conseguiu receber a data/hora atual do servidor
 */
static bool get_server_time(){
    char * url = config_data.server_ip;
    ip_addr_t ip;
    ip4addr_aton(url, &ip);

    char jsont_to_send[48] = {0};
    sprintf(jsont_to_send, "{\"id\":\"%s\",\"token\":\"%s\"}", config_data.station_name, config_data.station_token);

    WifiTcpData * ret = wifi_tcp_send(ip, url, config_data.server_port, PAGE_TIME, jsont_to_send);

    if(ret == NULL) return false;
    else{
        uint64_t new_time;
        if(wifi_tcp_answer_get_time(ret, &new_time)){
            core0_comm_new_time(new_time);
            return true;
        }else{
            return false;
        }
    }
}

/**
 * @brief Inicializa todo o sistema, ativa o core1 e mantem ativo um looping infinito para transmitir os dados
 * 
 */
int main()
{
    stdio_init_all();

#ifdef BITDOGLAB_WITH_DEBUG_PROBE
    gpio_set_function( 0, GPIO_FUNC_SIO);
    gpio_set_function( 1, GPIO_FUNC_SIO);
    gpio_set_function(17, GPIO_FUNC_UART);
    gpio_set_function(16, GPIO_FUNC_UART);
#endif

#if defined(WATCHDOG_PWM) || defined(WATCHDOG_TIMER)
    wrap_watchdog_disable();
#endif

    printf("***** Estação Meteorológica 01 *****\n");
    
    // Inicializar LEDs
    led_rgb_init();

    // Inicializar I2Cs
    i2c_init(         I2C_MAIN_BUS,      I2C_MAIN_BAUDRATE);
    gpio_pull_up(     I2C_MAIN_GPIO_SDA);
    gpio_pull_up(     I2C_MAIN_GPIO_SCL);
    gpio_set_function(I2C_MAIN_GPIO_SDA, GPIO_FUNC_I2C);
    gpio_set_function(I2C_MAIN_GPIO_SCL, GPIO_FUNC_I2C);

    i2c_init(         I2C_OLED_BUS,      I2C_OLED_BAUDRATE);
    gpio_pull_up(     I2C_OLED_GPIO_SCL);
    gpio_pull_up(     I2C_OLED_GPIO_SDA);
    gpio_set_function(I2C_OLED_GPIO_SCL, GPIO_FUNC_I2C);
    gpio_set_function(I2C_OLED_GPIO_SDA, GPIO_FUNC_I2C);
    
    // init display oled
    ui_display_init(false);

    led_rgb_set_st(LEDRGB_ST_BUSY);

#ifndef EASTER_EGG_ENABLED
    // Dump de memória
    if(!gpio_get(BUTTON_B_GPIO)){
        led_rgb_set_st(LEDRGB_ST_WIFI_ST_CONNECTED_WITH_ERROR);
        sleep_ms(10000);
        led_rgb_set_st(LEDRGB_ST_WIFI_ST_DISCONNECTED);

        estation_data_printf();
        stored_printf(true);
        
        led_rgb_set_st(LEDRGB_ST_WIFI_ST_CONNECTED_WITH_ERROR);
        sleep_ms(10000);
        led_rgb_set_st(LEDRGB_ST_BUSY);
    }
#endif

    // verifica se é para configurar:
    bool config = false;
    config |= !gpio_get(BUTTON_A_GPIO);
    config |= !config_data_storage_read();
    if(config) menu_config_init();
    if(config || (!config_data.rtc_with)) menu_clock();

    // Instala e habilita o IRQ do FIFO para o Core 0
    irq_set_exclusive_handler(SIO_IRQ_PROC0, core0_comm_core0_fifo_irq_handler);
    multicore_fifo_clear_irq();//SIO_IRQ_PROC0
    irq_set_enabled(SIO_IRQ_PROC0, true);

    // Ativa Core1  Led fica amarelo durante ativação do core1
    led_rgb_set_st(LEDRGB_ST_WIFI_ST_CONNECTED_WITH_ERROR);
    multicore_fifo_drain();

    printf("Starting Core1\n");
    multicore_launch_core1(core1_main);
    //multicore_fifo_pop_blocking();
    core0_comm_aguarda_cmd();   // Aguarda o Core1 ficar ativo
    led_rgb_set_st(LEDRGB_ST_OFF);

    wifi_init();
    
    uint64_t dt_next_show      =   1000000 * config_data_get_period_in_sec(config_data.period_show);
    uint64_t dt_next_send      =   1000000 * config_data_get_period_in_sec(config_data.period_send);
    uint64_t dt_next_get_time  =   1000000 * config_data_get_period_in_sec(config_data.period_sync_clk);
    uint64_t dt_next_retry     =   1000000 * config_data_get_period_in_sec(config_data.period_retry);

    uint64_t t_next_show       = 0;
    uint64_t t_next_send       = 0;
    uint64_t t_next_get_time   = 0;
    
    WiFiState last_wifi_st = WIFI_ST_DISCONNECTED;
    led_rgb_set_st(LEDRGB_ST_WIFI_ST_DISCONNECTED);

    printf("Starting Core0 Main Loop\n");

#if defined(WATCHDOG_PWM) || defined(WATCHDOG_TIMER)    
    wrap_watchdog_enable();
#endif

    printf("START\n");

    //sleep_ms(10000);

    while (true) {
        bool wifi_st = wifi_update();

#if defined(WATCHDOG_PWM) || defined(WATCHDOG_TIMER)
        wrap_watchdog_refresh();
#endif

        if(wifi_st){
            if(last_wifi_st == WIFI_ST_DISCONNECTED){
                last_wifi_st = WIFI_ST_CONNECTED_NO_ERROR;
                led_rgb_set_st(LEDRGB_ST_WIFI_ST_CONNECTED_NO_ERROR);
            }

            // Atualiza RTC
            if((config_data.period_sync_clk < PERIOD_N)&&(time_us_64() >= t_next_get_time)){
                printf("Requisitando Hora do servidor: ");
                if(get_server_time()){
                    util_print_timestamp(core_comm_new_time);
                    printf(" -- OK --\n");
                    last_wifi_st    = WIFI_ST_CONNECTED_NO_ERROR;
                    led_rgb_set_st(LEDRGB_ST_WIFI_ST_CONNECTED_NO_ERROR);
                    t_next_get_time = time_us_64() + dt_next_get_time; 
                }else{
                    printf(" -- ERRO --\n");
                    last_wifi_st = WIFI_ST_CONNECTED_WITH_ERROR;
                    t_next_get_time = time_us_64() + dt_next_retry; 
                }
            }
                
            // Envio de dados para o servidor
            if((config_data.period_send < PERIOD_N)&&(time_us_64() >= t_next_send)){
                bool fim = false;
                while(!fim){
                    if(core0_comm_give_next_data()){
                        printf("Enviado dados para o servidor: ");
                        estation_data_json(&core_comm_estation_data, estation_data_buf_tmp);
                        printf(estation_data_buf_tmp);
                        
                        if(send_data()){
                            last_wifi_st = WIFI_ST_CONNECTED_NO_ERROR;
                            led_rgb_set_st(LEDRGB_ST_WIFI_ST_CONNECTED_NO_ERROR);
                            core0_comm_give_next_data_sent();
                            printf(" -- OK --\n");
                        }else{
                            fim          = true;
                            last_wifi_st = WIFI_ST_CONNECTED_WITH_ERROR;
                            t_next_send  = time_us_64() + dt_next_retry;
                            printf(" -- ERROR --\n");
                        }
                    }else{
                        fim         = true;
                        t_next_send = time_us_64() + dt_next_send;
                    }
#if defined(WATCHDOG_PWM) || defined(WATCHDOG_TIMER)
                    wrap_watchdog_refresh();
#endif  
                }
            }
        }else{  // WiFi OFF
            last_wifi_st = WIFI_ST_DISCONNECTED;
        }

        // Atualiza os LEDs
        switch(last_wifi_st){
            case WIFI_ST_DISCONNECTED:         led_rgb_set_st(LEDRGB_ST_WIFI_ST_DISCONNECTED);         break;
            case WIFI_ST_CONNECTED_NO_ERROR:   led_rgb_set_st(LEDRGB_ST_WIFI_ST_CONNECTED_NO_ERROR);   break;
            case WIFI_ST_CONNECTED_WITH_ERROR: led_rgb_set_st(LEDRGB_ST_WIFI_ST_CONNECTED_WITH_ERROR); break;
        }

        // Envia dados para o terminal
        if((config_data.period_show < PERIOD_N) && (time_us_64() >= t_next_show)){
            t_next_show = time_us_64() + dt_next_show;

            core0_comm_give_last_data();
            int size  = estation_data_json(&core_comm_estation_data, estation_data_buf_tmp);
            printf("Last Data : %s\n", estation_data_buf_tmp);
        }

#if defined(WATCHDOG_PWM) || defined(WATCHDOG_TIMER)
#ifdef EASTER_EGG_ENABLED        
        if(!gpio_get(BUTTON_J_GPIO)){
            printf("Iniciado processo de Watdog reset\n");
            led_rgb_set_st(LEDRGB_ST_WHITE);
            uint64_t t0 = time_us_64();
            while(true){
                printf("%d\n", (int32_t)(time_us_64() - t0));
                sleep_ms(1000);
            }
        }
#endif
#endif
        
        //cyw43_arch_poll();
        sleep_us(1000);
    }
}

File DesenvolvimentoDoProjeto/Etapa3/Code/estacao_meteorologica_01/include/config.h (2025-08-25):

/**
 * @file    config.h
 * @author  Ricardo e Vagner
 * @brief   Configurações do hardware e definição de mensagens
 * @version 0.1
 * @date    2025-06-25
 */
#ifndef CONFIG_H
#define CONFIG_H


#define DEBUG_BITDOG_LAB
#define BITDOGLAB_WITH_DEBUG_PROBE


#define WIFI_DEINIT_DELAY_MS               500
#define WIFI_AFTER_CONNECT_FAIL_DELAY_MS  2000
#define WIFI_CONNECTION_TIMEOUT_MSW      30000



#define BUTTON_A_GPIO                  5
#define BUTTON_B_GPIO                  6
#define BUTTON_J_GPIO                 22

#define BUTTON_DEBONCE_MS             50

// I2C_MAIN used by all i2c sensors
#define I2C_MAIN_GPIO_SCL              1
#define I2C_MAIN_GPIO_SDA              0
#define I2C_MAIN_BAUDRATE         400000
#define I2C_MAIN_BUS                i2c0



// I2C_MAIN used by OLED
#define I2C_OLED_GPIO_SCL             15
#define I2C_OLED_GPIO_SDA             14
#define I2C_OLED_BAUDRATE         400000
#define I2C_OLED_BUS                i2c1

// I2C_GYRO used by Accelerometro
#define I2C_GYRO_GPIO_SCL              1
#define I2C_GYRO_GPIO_SDA              0
#define I2C_GYRO_BAUDRATE         400000
#define I2C_GYRO_BUS                i2c0


#define LED_R_GPIO                    13
#define LED_G_GPIO                    11
#define LED_B_GPIO                    12


#define GPIO_MOTOR_STANDBY_GPIO     20

#define GPIO_MOTOR_LEFT_GPIO_PWM    8       // 4A
#define GPIO_MOTOR_LEFT_GPIO_IN1    4       // 2A
#define GPIO_MOTOR_LEFT_GPIO_IN2    9       // 4B

#define GPIO_MOTOR_RIGHT_GPIO_PWM    16     // 0A
#define GPIO_MOTOR_RIGHT_GPIO_IN1    18     // 1A
#define GPIO_MOTOR_RIGHT_GPIO_IN2    19     // 1B

#define PWM_TICK_SLICE  3


#endif // CONFIG_H

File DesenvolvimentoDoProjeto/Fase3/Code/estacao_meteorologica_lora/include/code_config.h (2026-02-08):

/**
 * @file    code_config.h
 * @author  Antonio-Carlos-Ricardo
 * @brief   Parâmetros de configuração de compilação
 * @version 0.1
 * @date    2026-02-07
 * 
 * @copyright Copyright (c) 2026
 * 
 */
#ifndef CODE_CONFIG_H
#define CODE_CONFIG_H


// ********** Descrição do código gerado **********

#define NAME                        "Weather Station"
#define VERSION                     "0.00.01"
#define VERSION_DATA                "2026/02/08"
#define BUILD                       "0032"
#define CONFIG_DATA_VERSION         4   // uint32_t version;



// ********** Principais parâmetros de configuração **********

//#define PICO_WITH_DEBUG_PROBE                         // habilita o uso do debug probe reconfigurando as portas UART a serem utilizadas

#define DEBUG_ON                false   // true         // habilita printf de log para depuração
#define DEBUG_ON_AD             (DEBUG_ON && true)      // habilita printf de log do módulo aq_data_ad, VSys e MPU Temp
#define DEBUG_ON_BAT            (DEBUG_ON && true)      // habilita printf de log do módulo aq_data_bat
#define DEBUG_ON_BMEP280        (DEBUG_ON && false)     // habilita printf de log do módulo aq_data_bmep280
#define DEBUG_ON_GPS            (DEBUG_ON && true)      // habilita printf de log do módulo aq_data_gps
#define DEBUG_ON_LUXIMETER      (DEBUG_ON && true)      // habilita printf de log do módulo aq_data_lux

#define WATCHDOG_ENABLED                                // se definido ativa o funcionamento do watchdog
//#define START_SEND_WITH_FIX_DATA                      // se definido faz com que as 5 primeiras transmissões sejam valores conhecidos independentes do valor lido, útil para debug
#define SLEEP_STATE_BY_GPIO                             // se definido faz que durante os períodos de sleep os gpio reflitam o funcionamento do Sleep mode, util para debug
#define INITIAL_DELAY_MS        10000                   // define o tempo, em milissegundos, de espera inicial para rodar o programa, permitindo assim conectar a interface serial (USB) antes do programa iniciar
#define USB_TURN_ON_TIME_S      5
//#define ADD_CHECKSUM_ON_PAYLOAD                       // adiciona um CHECKSUM no final do payload



// ********** Parâmetros auxiliares **********

#define LOOP_PRINTF_ENABLED                             // se definido ativa o funcionamento da função loop_printf

// HW_SLEEP_LOW_POWER define se o modo low power será ativado ou não
#ifdef PICO_WITH_DEBUG_PROBE
//#define HW_SLEEP_LOW_POWER false
#define HW_SLEEP_LOW_POWER true
#else
#define HW_SLEEP_LOW_POWER true
#endif



// GPIOs utilizadas para reportar sleep-mode 
#define SLEEP_STATE_GPIO_0      18
#define SLEEP_STATE_GPIO_1      19

// Parâmetros de comunicação do GPS
#define GPS_UART_ID             uart1
#define GPS_UART_UART_IRQ       UART1_IRQ
#define GPS_UART_BAUD_RATE      9600
#define GPS_UART_TX_PIN         8
#define GPS_UART_RX_PIN         9
#define GPS_TIMEOUT_US          10000000

#define GPIO_BUTTON             5
#define GPIO_LED_RED            13
#define GPIO_LED_GREEN          11 
#define GPIO_LED_BLUE           12

// Parâmetros de comunicação do I2C
#define I2C_MAIN_GPIO_SCL       2
#define I2C_MAIN_GPIO_SDA       3
#define I2C_MAIN_BAUDRATE       400000
#define I2C_MAIN_BUS            i2c1
#define I2C_TIMEOUT_US_BMEP280  10000
#define I2C_TIMEOUT_US_BH1750   10000

// Parâmetros de comunicação do WCM via UART
#define WCM_UART_ID             uart0
#define WCM_UART_TX_PIN         0       
#define WCM_UART_RX_PIN         1       
#define WCM_UART_BAUD_RATE      115200
#define WCM_TIMEOUT_US          10000000

#define WATCHDOG_TIME_MS        5000        // dispara o watchdog em 5 segundos se ele não for atualizado


#endif // CODE_CONFIG_H

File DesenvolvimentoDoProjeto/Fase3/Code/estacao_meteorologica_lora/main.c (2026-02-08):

/**
 * @file    main.c
 * @author  Antonio-Carlos-Ricardo
 * @brief   Inicialização do sistema e main loop
 * @version 0.2
 * @date    2026-02-08
 * 
 * @copyright Copyright (c) 2026
 */

#include <stdio.h>
#include "pico/stdlib.h"
#include "include/aq_data.h"
#include "include/buttons_and_leds.h"
#include "include/code_config.h"
#include "include/est_config.h"
#include "include/hw_sleep.h"
#include "include/loop_printf.h"
#include "include/menu_conf.h"
#include "include/wcm.h"
#include "include/wrap_watchdog.h"


#define MAIN_ST_INIT            LED_GREEN       // LED Green, indica inicializando o sistema, tempo para conectar USB
#define MAIN_ST_WAIT_BUTTON     LED_YELLOW      // LED Red e Green, indica que botão será reconhecido
#define MAIN_ST_MENU            LED_RED         // Indica que o menu de configuração esta ativo
#define MAIN_ST_MENU_AFTER      LED_CYAN        // Indica que a estação já passo pelo menu
#define MAIN_ST_AQUISITION      LED_BLUE        // Indica que está fazendo aquisição dos dados
#define MAIN_ST_TRANSMISSION    LED_WHITE       // Indica que está transmitindo os dados
#define MAIN_ST_SLEEPING        LED_BLACK       // Indica que a estação está em sleep-mode, baixo consumo de energia


static uint32_t  wakeup_cycle = 0;
static AqData    aq_data;
static EstConfig est_config;

/**
 * @brief Inicializa todo o sistema e mantêm o main loop
 * 
 * @return int  Nunca retorna (main-loop)
 */
int main(){
    int ret;

    stdio_init_all();
    wrap_watchdog_disable();

    #ifdef SLEEP_STATE_BY_GPIO
        // Configuração das GPIOs utilizadas para monitorar o sleep state da estação
        gpio_set_dir(     SLEEP_STATE_GPIO_0, GPIO_OUT);
        gpio_put(         SLEEP_STATE_GPIO_0, 0);
        gpio_set_function(SLEEP_STATE_GPIO_0, GPIO_FUNC_SIO);

        gpio_put(         SLEEP_STATE_GPIO_1, 0);
        gpio_set_dir(     SLEEP_STATE_GPIO_1, GPIO_OUT);
        gpio_set_function(SLEEP_STATE_GPIO_1, GPIO_FUNC_SIO);
    #endif

#ifdef PICO_WITH_DEBUG_PROBE
    // Reconfiguração dos GPIOs da UART para uso em Debug
    gpio_set_function( 0, GPIO_FUNC_SIO);
    gpio_set_function( 1, GPIO_FUNC_SIO);
    gpio_set_function(17, GPIO_FUNC_UART);
    gpio_set_function(16, GPIO_FUNC_UART);
#endif

    buttons_and_leds_init();
    buttons_and_leds_set_color(MAIN_ST_INIT);
    wcm_init();

    // Dar tempo para conectar a interface serial
    sleep_ms(INITIAL_DELAY_MS);    

    printf("********** %s **********\n\n", NAME);
    printf("Version: %s - %s - Build: %s\n", VERSION, VERSION_DATA, BUILD);

    // Janela para pressionar o botão
    bool button_pressed = false;
    for(int i=0;i<25;i++){
        buttons_and_leds_set_color(i&0x01?MAIN_ST_INIT:MAIN_ST_WAIT_BUTTON);
        for(int j=0;j<100;j++){
            if(buttons_and_leds_button_pressed()) button_pressed = true;
            sleep_us(2000);
        }
    }

    
    bool valid_flash_data = est_config_storage_read(&est_config);
    printf(valid_flash_data?"Flash: Valid Data\n\n\n":"Flash: Invalid Data\n\n\n");

    // Verifica condições para iniciar o terminal TXT:
    //    - Dados inválidos na flash                     ou
    //    - (Botão pressionado  e always_menu == false)  ou
    //    - (Botão solto        e always_menu == true )
    //    Obs.: O Botão pressionado inverte o funcionamento do parâmetro always_menu
    if((!valid_flash_data) || 
       (  button_pressed  && (!est_config.always_menu)) || 
       ((!button_pressed) &&   est_config.always_menu)){
        buttons_and_leds_set_color(MAIN_ST_MENU);
        menu_conf(&est_config, valid_flash_data);
    }

    buttons_and_leds_set_color(MAIN_ST_MENU_AFTER);
    aq_data.active_sensors = est_config.active_sensors;

    // Inicializa, power_on de todos os sensores
    if(ret = aqdata_init_power_on(&aq_data, est_config.lux_k_10000, est_config.vsys_k_10000)){
        loop_printf("Init Power sensors fail: %d\n", ret);
        while(1){
            buttons_and_leds_set_color(LED_BLACK);
            sleep_ms(200);
            buttons_and_leds_set_color(LED_RED);
            sleep_ms(200);
        }
    }

    // desativa recursos desnecessários do rp2040
    hw_sleep_init(est_config.usb_mode, est_config.active_sensors.cpu_temp || est_config.active_sensors.vsys,  est_config.sleep_time_min);    
    buttons_and_leds_set_color(LED_BLACK);
    
    wrap_watchdog_enable();

    while (true) {
        wrap_watchdog_update();
        
        // Avisa que vai iniciar a aquisição
        if(est_config.leds_on) buttons_and_leds_set_color(MAIN_ST_AQUISITION);
        
        // Faz a aquisição completa:
        
        // inicia o processo de aquisição
        if(ret = aqdata_init_aq(&aq_data)){
            loop_printf("Init Aq sensors fail: %d\n", ret);
        }
        // lê os dados
        if(ret = aqdata_read(&aq_data)){
            loop_printf("Read sensors fail: %d\n", ret);
        }
        // Coloca os sensores em sleep-mode
        if(ret = aqdata_sleep(&aq_data)){
            loop_printf("Sleep sensors fail: %d\n", ret);
        }
        
        // Envia os dados
        loop_printf("Station sending data\n");
        if(est_config.leds_on) buttons_and_leds_set_color(MAIN_ST_TRANSMISSION);
        wcm_send(&est_config, &aq_data);
        
        // Coloca o rp2040 em "sleep-mode" e o ativa para o modo normal quando for fazer o novo ciclo de leitura e aquisição
        loop_printf("Station sleeping\n");
        if(est_config.leds_on) buttons_and_leds_set_color(MAIN_ST_SLEEPING);
        hw_sleep();

        loop_printf("Station Wake Up %d\n", ++wakeup_cycle);
    }
}

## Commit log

2025-08-12 Add Enderecos I2C
2025-08-25 Adding EstMeteo ET3.md with prototype information
2025-08-25 Correção de texto
2025-12-06 Add Pic Current
2026-01-21 Add PCB
    [Estacao.kicad_pcb, Estacao.kicad_sch]
2026-01-22 Updade Slik da PCB V01
    [Estacao.kicad_pcb, Estacao.kicad_sch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]
2026-01-26 pcb v02-00
    [Estacao.kicad_pcb, Estacao.kicad_sch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]
2026-01-31 Update PCB V03
    [Estacao.kicad_pcb, Estacao.kicad_sch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]
2026-02-04 UpdatePcb V3
    [Estacao.kicad_pcb, Estacao.kicad_sch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]
2026-02-22 Atualizacao final
    [Estacao.kicad_pcb, Estacao.kicad_sch, haste fixação painel solar.stl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]
2026-02-25 WCM: Versão 0.00.07 - 25/02/2026 - Build: 0007 - Remoção das mensagens de debug
2026-03-03 Add no dir KiCad main board fp-lib-table
